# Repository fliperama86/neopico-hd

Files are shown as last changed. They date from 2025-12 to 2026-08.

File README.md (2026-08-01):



# NeoPico-HD

Digital video and audio capture with HDMI output for Neo Geo MVS arcade hardware using Raspberry Pi Pico 2 (RP2350B).

## Features

- **Native 240p HDMI output** at 60fps (via 480p line doubling for audio compatibility)
- **Experimental exact-clock 720p HDMI output** - the normal selector uses a 64.000 MHz, 1440x741 reduced-blanking raster at 59.979 Hz and centers the source at 3x scale
- **15-bit RGB + SHADOW/DARK capture** - 19-bit capture path includes SHADOW and DARK control lines
- **Pixel Conversion Modes** - Stable 32K-entry RGB LUT, plus an optional live and persistent `Digital`/`Analog` normal-color selector that remains separate from DARK/SHADOW processing
- **Translucent OSD Panel** - Enabled by default; game pixels under the black panel retain 12.5% brightness while text and menu colors remain opaque
- **Digital audio capture** from I2S bus (before DAC) with 48kHz HDMI output
- **Zero-overhead DMA video capture** - uses PIO + DMA with ping-pong buffering for perfect stability
- **PicoHDMI Output** - Powered by the [PicoHDMI](https://github.com/fliperama86/pico_hdmi) library for efficient, hardware-native TMDS encoding via RP2350 HSTX.

## Status

| Feature | Status |
| --- | --- |
| 480p HDMI video | Working |
| 720p HDMI video | Experimental (exact-clock runtime selector mode) |
| 60fps capture | Working |
| RGB555 Digital path | Working |
| Live Colors selector | Available whenever DARK/SHADOW is off (MVS builds) |
| SHADOW/DARK capture | Working |
| SHADOW/DARK conversion  | Experimental, default off; split-LUT hardware test showed bottom-screen pixel jitter |
| HDMI audio (48kHz) | Working |
| OSD Diagnostics | Working |
| Morhph4K, RetroTink 4K  | Tested |
| Samsung Q80, Acer Pred. | Tested |

## Hardware Requirements

- **Raspberry Pi Pico 2** - Must be RP2350**B** variant (48 GPIOs) for digital audio capture
- **Neo Geo MVS board** - Tested on MV1C
- **HDMI connector** wired to Pico GPIO

### Hardware Setup & Signal Integrity

To ensure clean audio and video capture, follow these best practices:

1.  **Common Ground**: A solid ground connection between the MVS board and the Pico is **mandatory**.
2.  **HDMI Power**: It is **absolutely mandatory** to have the HDMI connector properly powered with **+5V**. While some devices (like the Morph4K) may be forgiving, others (like the RetroTINK, TVs and monitors) will not pick up the signal without it.
3.  **Level Shifting**: Route all MVS -> Pico digital lines through proper **5V-to-3.3V level shifters**.
4.  **Clock Conditioning**: Keep **Schmitt-trigger conditioning** on PCLK and BCK for clean edges.
5.  **Power-Path Isolation**: Prevent back-feed between external 5V and USB 5V (ideal diode/power mux approach recommended).
6.  **Cable Separation**: Physically separate the I2S audio wires (GPIO 22-24 path) from the video wire bundle to avoid coupling.
7.  **Shielding**: Use a **GND-Signal-GND** pattern when using ribbon cables.

### Pin Configuration

#### Video Capture (Bank 1)

| Function | GPIO | Notes |
| --- | --- | --- |
| MVS CSYNC  | GPIO 27 | Composite sync |
| MVS PCLK | GPIO 28 | 6 MHz pixel clock |
| MVS Blue | GPIO 29-33 | B4-B0 (contiguous) |
| MVS Green  | GPIO 34-38 | G4-G0 (contiguous) |
| MVS Red | GPIO 39-43 | R4-R0 (contiguous) |
| MVS SHADOW | GPIO 44 | Shadow dimming |
| MVS DARK | GPIO 45 | Dark dimming control |

#### HSTX Output (Bank 0/1)

| Function | GPIO |
| --- | --- |
| TMDS CLK | GPIO 12-13 |
| TMDS D0  | GPIO 14-15 |
| TMDS D1  | GPIO 16-17 |
| TMDS D2  | GPIO 18-19 |

#### Audio Capture

| Function | GPIO | MV1C Tap Point |
| --- | --- | --- |
| I2S DAT  | GPIO 22 | R91 |
| I2S WS | GPIO 23 | R90 |
| I2S BCK  | GPIO 24 | R92 |

#### Controller OSD Inputs (MVS/AES)

| Controller input | GPIO |
| --- | ---- |
| START / MENU | GP0  |
| SELECT / BACK | GP1  |
| DOWN | GP2  |
| UP | GP3  |

The inputs are active low and use weak internal pull-ups so untapped pins stay
idle. They are always enabled, on both MVS/AES and SNES builds (GP0-3 are
unused by SNES capture, so this is harmless there too).

## Prebuilt Firmware

GitHub Releases include ready-to-flash selector firmware. Each UF2 can switch
between 240p, 480p, and 720p from the reboot-based OSD resolution menu. The MVS
asset also includes persistent Audio and live-preview Colors menus. The optional
PC monitor modes are default-off and are not included in those release choices.
The selector's 720p entry uses the exact 64.000 MHz reduced-blanking timing;
because it is non-CTA and advertises VIC 0, sink compatibility still needs broad
testing.

| Asset | Capture | OSD choices |
| ----- | --- | --- |
| `neopico_hd_mvs.uf2` | Neo Geo MVS/AES | Resolution, Audio, and Digital/Analog Colors |
| `neopico_hd_snes.uf2` | SNES | Resolution |

Matching ELF files and the `neopico-hd-jlcpcb.zip` fabrication package are also
attached to each release. Controller-driven AES OSD navigation is enabled in
both release assets (GP0-3 are unused by SNES capture).

## Building

Requires [Pico SDK](https://github.com/raspberrypi/pico-sdk) with `PICO_SDK_PATH` set.

```bash
# Build and flash
./flash

# Optional standalone HDMI/OSD self-test firmware
cmake -S . -B build_selftest -DNEOPICO_BUILD_SELFTEST=ON
cmake --build build_selftest --target neopico_selftest -j4

# Standard MVS build. Audio is always SELECTABLE (persistent Audio menu
# between the digital NEO-YSA2 tap and an external PCM1802 ADC) and the
# live persistent Colors selector (Digital/Analog normal-color, ignoring
# DARK/SHADOW) is available automatically since DARK/SHADOW defaults off.
cmake -S . -B build_mvs
cmake --build build_mvs --target neopico_hd -j4

# Separate DARK/SHADOW timing experiment. This path produced bottom-screen
# pixel jitter in hardware testing. Enabling it automatically compiles out
# the Colors selector (the two features share the same capture LUT machinery).
cmake -S . -B build_effects \
  -DNEOPICO_ENABLE_DARK_SHADOW=ON \
  -DNEOPICO_MVS_EFFECT_MODEL=MISTER
cmake --build build_effects --target neopico_hd -j4

# Digital-only register-processing experiment. This replaces the split effect
# LUT with RBIT, bitfield, saturating DARK, and packed SHADOW operations. It is
# default off and must be hardware-validated before use in release firmware.
cmake -S . -B build_effects_processing \
  -DNEOPICO_COPY_TO_RAM=ON \
  -DNEOPICO_ENABLE_DARK_SHADOW=ON \
  -DNEOPICO_MVS_DIGITAL_EFFECT_PROCESSING=ON \
  -DNEOPICO_MVS_EFFECT_MODEL=MISTER
cmake --build build_effects_processing --target neopico_hd -j4
```

## Architecture

```
Core 0: Video Capture               Core 1: Audio Pipeline + HSTX
+--------------------------+       +--------------------------+
| Video: PIO1 -> DMA (PP)  |       | Audio: PIO2 -> processing|
| Conv: 32K LUT (dual opt) |       | [ PicoHDMI Library ]     |
| Main loop: Control       |       | - 640x480 @ 60Hz         |
| Heartbeat LED            |       | - HDMI Data Islands      |
+--------------------------+       +--------------------------+
          |                        +--------------------------+
          |                                   |
          +--------- framebuf ----------------+
                  (320x240 RGB565)
```

### PicoHDMI Library Integration

The project leverages the [PicoHDMI](https://github.com/fliperama86/pico_hdmi) library (found in `lib/pico_hdmi`) to interface with the RP2350's HSTX peripheral. This library provides the high-performance TMDS encoding and Data Island management required for stable HDMI output.

- **Dedicated Output Core**: To ensure rock-solid HDMI timing (exactly 800 cycles per line), the library runs its main loop on **Core 1**. This isolates the high-priority TMDS serialization from the video capture logic on Core 0.
- **Zero-Latency Scaling**: We use the library's `video_output_set_scanline_callback()` to implement a scanline doubler. This performs 2x vertical upscaling (240p to 480p) on-the-fly as pixels are streamed to the HSTX, avoiding the need for a full 480p framebuffer.
- **HDMI Audio Injection**: Audio data is integrated via the library's Data Island queue (`hstx_di_queue`). The audio subsystem pushes TERC4-encoded packets into this queue, which the library then automatically injects during the horizontal blanking intervals.
- **Frame Synchronization**: A VSYNC callback is used to keep the video capture ring buffer and the HDMI output in perfect sync, minimizing latency and preventing screen tearing.

## Documentation

- **[System Architecture](docs/ARCHITECTURE.md)**: High-level design, core partitioning, and the closed-loop audio sync.
- **[Video Implementation](docs/MVS_MV1C_DIGITAL_VIDEO.md)**: Tap points, signal logic, and PIO capture.
- **[Audio Implementation](docs/MVS_MV1C_DIGITAL_AUDIO.md)**: I2S format, ASRC strategy, and drift control.
- **[Standalone PCM1802 USB Capture](docs/PCM1802_USB_CAPTURE.md)**: Raw ADC diagnostic firmware and host capture tool.
- **[HSTX & HDMI](docs/HSTX_IMPLEMENTATION.md)**: Output timing, TMDS, and Data Islands.
- **[OSD](docs/OSD_IMPLEMENTATION.md)**: On-Screen Display rendering.
- **[Reboot Resolution Switching](docs/REBOOT_RESOLUTION_SWITCHING.md)**: Reboot selector modes.
- **[720p Samsung Game Mode Investigation](docs/720P_SAMSUNG_GAME_MODE_INVESTIGATION.md)**: Current findings on Samsung Game Mode 720p glitches.
- **[Known Issues](docs/KNOWN_ISSUES.md)**: Current limitations and compatibility notes.

## Architecture Highlights

- **Dual-Core Design**: Dedicated cores for Video Capture (Core 0) and HDMI Output (Core 1).
- **Closed-Loop Audio Sync**: Software-defined feedback loop effectively "genlocks" the MVS audio to the HDMI clock, preventing drift and glitches without an FPGA.
- **Zero-Lag**: Scanline-doubling architecture with no framebuffer delay.

## Installation

Unlicense

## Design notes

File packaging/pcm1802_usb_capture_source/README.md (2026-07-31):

# NeoPico PCM1802 USB Capture Source

This is a standalone source package for the NeoPico PCM1802 USB capture
diagnostic. It builds without the NeoPico-HD video or PicoHDMI sources.

The firmware captures standard-I2S PCM1802 DOUT as signed, stereo, 24-bit PCM
and sends versioned, CRC-protected packets through TinyUSB CDC. The default
transport preserves all 24 bits. An optional reduced-bandwidth transport sends
the upper 16 bits, and the included host tool automatically writes a matching
48 kHz stereo WAV file.

## Validation status

The source package is built from the same files as the NeoPico-HD repository.
Its standalone CMake project is tested after export with clean 24-bit and 16-bit
RP2350 builds. The 24-bit firmware has completed a local zero-drop 48 kHz
hardware capture; achievable USB throughput remains host-dependent.

## Source layout

```text
CMakeLists.txt
LICENSE
src/
  main.c
  usb_descriptors.c
  tusb_config.h
  i2s_capture.pio
tools/
  capture_pcm1802_usb.py
```

## Requirements

- Raspberry Pi Pico SDK with RP2350 support
- Arm GNU Toolchain
- CMake and a supported build tool such as Ninja or Make
- WeAct RP2350B board, or another RP2350 board exposing GP22 through GP24

## Build

Set `PICO_SDK_PATH`, then configure and build from this extracted directory:

```sh
cmake -S . -B build \
  -DPICO_SDK_PATH="$HOME/pico-sdk" \
  -DCMAKE_BUILD_TYPE=Release
cmake --build build --target neopico_pcm1802_usb_capture -j
```

The default board is `weact_studio_rp2350b_core`. Override `PICO_BOARD` and, if
needed, `PICO_PLATFORM` for another RP2350 board.

The standalone UF2 is generated at:

```text
build/neopico_pcm1802_usb_capture.uf2
```

For the reduced-bandwidth diagnostic, add this configure option and use a
separate build directory:

```sh
-DNEOPICO_PCM1802_USB_BITS_PER_SAMPLE=16
```

The default is `24`. The 16-bit option does not reconfigure the PCM1802 or PIO;
it discards the least-significant byte only while staging USB packets.

## Expected PCM1802 connection

| Signal | RP2350B pin |
| --- | --- |
| PCM1802 DOUT | GP22 |
| PCM1802 LRCK | GP23 |
| PCM1802 BCK | GP24 |

Expected format: standard Philips I2S, 24-bit, LRCK low for left and high for
right. With 12.288 MHz SCKI in 256fs master mode, LRCK is 48 kHz and BCK is
3.072 MHz.

## Power safety

Prevent backfeeding between USB 5 V and external 5 V. Disconnect external power
unless the installation has verified power-path isolation. Keep a solid shared
ground between the PCM1802 and RP2350B, and do not alter wiring while powered.

## Host protocol self-test and capture

The self-test does not require pyserial or hardware:

```sh
python3 tools/capture_pcm1802_usb.py --self-test
```

Install pyserial for a real capture:

```sh
python3 -m pip install pyserial
python3 tools/capture_pcm1802_usb.py pcm1802-raw.wav
```

Use `--seconds 30` for a timed capture or `--port COM5` on Windows when explicit
port selection is needed.

Flashing this diagnostic temporarily replaces the normal NeoPico-HD firmware.
Flash the normal NeoPico-HD UF2 again after collecting the WAV.

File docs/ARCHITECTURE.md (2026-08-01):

# NeoPico-HD System Architecture

NeoPico-HD is a specialized firmware that transforms the RP2350 microcontroller into a real-time, digital-to-digital capture and upscaling bridge for the Neo Geo MVS.

## 1. High-Level Overview

The system bridges two asynchronous clock domains:
1.  **Input Domain**: The Neo Geo MVS (Variable/Drifting clock ~6 MHz pixel, ~55.5 kHz audio).
2.  **Output Domain**: Standard HDMI/DVI (Fixed clock 25.2 MHz pixel, 48 kHz audio).

Unlike FPGA solutions that "slave" the output clock to the input, NeoPico-HD uses the RP2350's raw horsepower to **resample** the data in real-time, maintaining a standards-compliant HDMI output signal regardless of the input source's behavior.

## 2. Core Responsibilities

The workload is strictly partitioned between the two cores to ensure deterministic timing for critical tasks.

### Core 0: Capture & Conversion (The "Input" Core)
*   **Video Capture**: Uses PIO1 (Bank 1 GPIOs) to sample the 15-bit RGB bus + Control signals at exactly 6 MHz.
*   **Synchronization**: Re-synchronizes the PIO state machine on every single CSYNC falling edge to prevent horizontal drift.
*   **Pixel Processing**:
    *   Detects `SHADOW` and `DARK` bits.
    *   Default build uses a pre-computed 32K LUT for corrected RGB555 -> RGB565 conversion.
    *   Whenever `NEOPICO_ENABLE_DARK_SHADOW` is off (MVS builds), the live Colors selector generates 64 KiB `Digital` and `Analog` normal-color LUTs at boot. Core 0 selects one base pointer at input VSYNC, while the pixel loop remains one lookup per pixel. Both choices ignore SHADOW/DARK.
    *   Separate `NEOPICO_ENABLE_DARK_SHADOW=ON` uses an 8,448-byte R/G-plus-B split LUT for four effect states. This timing experiment produced bottom-screen pixel jitter and remains default off.
    *   Converts raw MVS data into standard RGB565.
*   **Frame Management**: Writes to a ping-pong buffer in RAM.
*   **Deferred Colors Persistence**: After a completed frame, Core 0 services the rare queued flash write and resets capture for clean synchronization. This path is experimental and does not run during ordinary frames.

### Core 1: Output & Audio (The "Output" Core)
*   **Video Output**: Drives the HSTX peripheral to generate 640x480p @ 60Hz DVI/HDMI signals.
*   **Scanline Doubling**: Reads the 320x240 capture buffer and performs line doubling on-the-fly during DMA interrupts.
*   **OSD Overlay**: Injects the On-Screen Display menu pixels during the scanline generation phase.
*   **Colors Control**: Browsing previews through a frame-boundary LUT request. SELECT restores the committed model; START/MENU queues persistence without rebooting.
*   **Audio Pipeline**:
    *   Captures I2S audio via PIO2 (Bank 0).
    *   Runs the **Closed-Loop ASRC** (Asynchronous Sample Rate Converter) to downsample ~55.5kHz to 48kHz.
    *   Encodes audio into TERC4 Data Islands and injects them into the HDMI blanking intervals.

## 3. The Audio Sync Solution (Closed-Loop ASRC)

One of the project's key innovations is handling the asynchronous audio without an FPGA.

### The Problem
The MVS audio clock drifts relative to the RP2350's crystal. A fixed resampling ratio eventually leads to buffer underrun (silence) or overflow (glitches) every ~40 seconds.

### The Solution
We implemented a **Proportional Control Loop**:
1.  **Measure**: The system monitors the fill level of the HDMI Data Island Ring Buffer (`hstx_di_queue`).
2.  **Feedback**:
    *   If buffer > 60% full -> The SRC is "producing too fast". We effectively increase the input rate parameter, causing the SRC to drop more samples to catch up.
    *   If buffer < 35% full -> The SRC is "producing too slow". We decrease the input rate parameter, causing the SRC to emit more samples.
3.  **Result**: The audio buffer hovers around 50%, essentially "locking" the audio production rate to the video consumption rate.

## 4. Memory Map

| Region | Size | Usage |
| :--- | :--- | :--- |
| **SRAM_STRIPED** | 8.25-128 KiB | **Video LUT** (64 KiB stable table, 128 KiB dual normal-color menu, or 8.25 KiB separate four-state effect experiment) |
| **SRAM** | 150 KB | **Framebuffer** (320x240 RGB565) |
| **SRAM** | 16 KB | **Audio DMA Buffer** (Raw I2S capture) |
| **SCRATCH_X** | 4 KB | **Core 1 ISRs** (HSTX/Audio critical code) |
| **SCRATCH_Y** | 4 KB | **Core 0 ISRs** (Capture critical code) |

## 5. Hardware Interfaces

*   **Bank 0 (GPIO 0-29)**: Standard I/O. Used for I2S Audio (PIO2) and HSTX Output.
*   **Bank 1 (GPIO 25-47)**: High-speed capture. Used for the MVS 24-bit video bus.
    *   *Note*: Accessing Bank 1 requires specific SDK register manipulation (`GPIOBASE` offsets).

## 6. Critical Constraints

*   **Interrupt Latency**: Core 1's DMA ISR must complete well within the horizontal blanking period (~1.9µs) to maintain HDMI sync.
*   **CPU Cycle Sensitivity**: In the scanline generation phase, every nanosecond counts. Unoptimized logic (such as `if` statements inside pixel loops) will cause the HSTX FIFO to underrun, resulting in an immediate loss of video signal.
*   **Grounding**: The digital video tap is extremely sensitive to ground loops. A low-impedance shared ground is mandatory.

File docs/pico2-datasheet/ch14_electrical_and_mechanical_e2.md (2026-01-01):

## Chapter 14. Electrical and mechanical E2

This section contains physical and electrical details for RP2350.

## 14.1. QFN-60 package

Millimetre

Nom.

0.850

0.203 REF

0.400 BSC

0.350

Tolerances of form and position aaa

bbb cCC

didd eee

fff

All dimensions are in millimetres

Drawings not to scale ddd M

<!-- image -->

A

C A

в

Table 1423. Thermal data for the QFN-60 package.

Figure 144. Recommended PCB Footprint for the RP2350 QFN-60 package

<!-- image -->

Leads have a matte Tin (Sn) finish. Annealing is done post-plating, baking at 150°C for 1 hour. Minimum thickness for lead plating is 8 microns, and the intermediate layer material is CuFe2P (roughened Copper (Cu)).

## 14.1.1. Thermal characteristics

The thermal characteristics of the QFN-60 package are shown in Table 1423.

| Device | θ JA (°C/W) - Still Air | θ JA (°C/W) - 1m/s Forced Air | θ JA (°C/W) - 2m/s Forced Air | θ JB (°C/W) | θ JC (°C/W) |
|---|---|---|---|---|---|
| RP2350A  | 40.542 | 31.99 | 30.264 | 12.588 | 14.315 |
| RP2354A  | TBD | TBD | TBD | TBD | TBD |

## 14.1.2. Recommended PCB footprint

<!-- image -->

## 14.2. QFN-80 package

\_aser mark for pir identification in

this area aaa

C ×2

aaa

Table 1424. Thermal data for the QFN-80 package.

× 80

Bottom view

D2- ffM

A

Pin 1 identification

<!-- image -->

<!-- image -->

##  NOTE

Leads have a matte Tin (Sn) finish. Annealing is done post-plating, baking at 150°C for 1 hour. Minimum thickness for lead plating is 8 microns, and the intermediate layer material is CuFe2P (roughened Copper (Cu)).

## 14.2.1. Thermal characteristics

The thermal characteristics of the QFN-80 package are shown in Table 1424.

| Device | θ JA (°C/W) - Still Air | θ JA (°C/W) - 1m/s Forced Air | θ JA (°C/W) - 2m/s Forced Air | θ JB (°C/W) | θ JC (°C/W) |
|---|---|---|---|---|---|
| RP2350B  | TBD | TBD | TBD | TBD | TBD |
| RP2354B  | TBD | TBD | TBD | TBD | TBD |

## 14.2.2. Recommended PCB footprint

<!-- image -->

## 14.3. Flash in package

RP2354A and RP2354B feature 2 MB of internal flash. In all other respects, including pinout, they are identical to their flashless  counterparts  RP2350A  and  RP2350B.  They  use  the  same  QFN-60  (RP2354A)  and  QFN-80  (RP2354B) packages. An RP2354 device contains two stacked silicon die:

- the same RP2350 die as the flashless variants
- a Winbond W25Q16JVWI QSPI NOR flash

## Winbond W25Q16JVWI datasheet

For detailed information on the W25Q16JVWI device used in RP2354 see:

www.winbond.com/hq/product/code-storage-flash-memory/serial-norflash/?\_\_locale=en&amp;partNo=W25Q16JV

The six dedicated QSPI pads on the RP2350 die ( CSn , SCK and SD0 through SD3 ) connect to both the internal flash die and the external package pins. This makes them behave similarly to flashless RP2350 devices in the following ways:

- The QSPI CSn can be driven low at reset or power-up to select BOOTSEL mode
- This harmlessly selects the internal flash die but does not issue commands to it
- The QSPI SD1 pin can be driven high when selecting BOOTSEL to choose UART boot
- UART TX appears on SD2 and UART RX on SD3 , as per Section 5.8
- Even with the chip select asserted low, the internal flash die maintains a high-impedance state on its SD0 through SD3 pins if there are no transitions on SCK , so you can keep CSn asserted throughout UART boot
- Internal flash can be programmed via UF2 drag-and-drop download using the USB BOOTSEL mode
- A second QSPI device can be attached externally by connecting it to the QSPI pins and a secondary chip select from the Bank 0 GPIOs
- This may be used for additional flash capacity, or external QSPI RAM

- See Section 12.14 for more details of the RP2350 QSPI memory interface and its capabilities

The internal flash die can also be programmed externally by holding the RP2350 die in reset via the RUN pin (active-low reset), and driving QSPI signals into the chip from an external programmer.

The internal  flash  is  powered  by  the  QSPI\_IOVDD  supply  input.  This  voltage  must  be  in  the  range  2.7  to  3.6 V.  You should account for the increased high-frequency currents on this supply pin in your decoupling circuit and PCB layout.

The maximum QSPI clock frequency of the W25Q16JVWI is 133 MHz. Consult the W25Q16JVWI datasheet for detailed timings and AC parameters.

If you do not require access to the RP2350 QSPI bus from the outside, you should minimise the track length connected to the QSPI package pins on your PCB. This avoids unnecessary emissions and capacitive loading of the QSPI bus.

The PADRESETB reset input on the W25Q16JVWI is not connected to any external package pins, or to any internal signals on the RP2350 die. This means there is no way to perform a hardware reset of the flash die. When the RP2350 die comes out of reset it initialises the flash die in the same way it would an external flash device by issuing a fixed XIP exit sequence that returns the flash die to a serial command state in preparation for execute-in-place setup.

## 14.4. Package markings

RP2350 comes in 7 × 7 mm QFN-60 and 10 × 10 mm QFN-80 packages, which are marked with the following data:

- Pin 1 dot
- Logo
- Part number
- Date code (Week)
- Silicon lot number
- Date code (Year)

The part number consists of the following:

- Device name "RP2350"
- Package type, "A" for QFN-60 or "B" for QFN-80
- Package revision "0"
- Die stepping "A2", "A3", or "A4"

See Appendix C for a summary of the differences between die steppings.

## 14.5. Storage conditions

To preserve the shelf and floor life of bare RP2350 devices, follow JEDEC J-STD (020E &amp; 033D).

RP2350 QFN-60 is classified as Moisture Sensitivity Level 1 (MSL1). The MSL of QFN-80 is still being characterised and details will follow in a future datasheet update.

All RP2350 devices should be stored under 30°C and 85% relative humidity.

## 14.6. Solder profile

RP2350 is a Pb-free part, with a T p value of 260°C.

All  temperatures  refer  to  the  centre  of  the  package,  measured  on  the  package  body  surface  that  faces  up  during

Figure 147. Classification profile (not to scale)

Table 1425. Solder profile values

assembly reflow (live-bug orientation). If parts are reflowed in a different orientation (e.g. dead-bug), T p shall be within ±2°C of the live-bug T p and still meet the T c requirements; otherwise, you must adjust the profile to achieve the latter.

<!-- image -->

Reflow profiles in this document are for classification/preconditioning, and are not meant to specify board assembly profiles. Actual board assembly profiles should be developed based on specific process needs and board designs, and should not exceed the parameters in Table 1425.

| Profile feature | Value |
|---|---|
| Temperature min (T smin ) | 150°C |
| Temperature max (T smax ) | 200°C |
| Time (t s ) from (T smin to T smax ) | 60 - 120 seconds  |
| Ramp-up rate (T L to T p ) | 3°C/second max. |
| Liquidous temperature (T L ) | 217°C |
| Time (t L ) maintained above T L | 60 to 150 seconds |
| Peak package body temperature (T p ) | 260°C |
| Classification temperature (T c ) | 260°C |
| Time (t p ) within 5°C of the specified classification temperature (T c ) | 30 seconds |
| Ramp-down rate (T p to T L ) | 6°C/second max. |
| Time 25°C to peak temperature | 8 minutes max. |

## 14.7. Compliance

RP2350 QFN-60 is compliant to Moisture Sensitivity Level 1. The Moisture Sensitivity Level compliance of RP2350 QFN80 is yet to be fully characterised, and details will follow in a future datasheet update.

RP2350 is compliant to the requirement of REACH Substances of Very High Concern (SVHC), EU ECHA directive.

RP2350 is compliant to the requirement and standard of Controlled Environment-related Substance of RoHS directive (EU) 2011/65/EU and directive (EU) 2015/863.

Raspberry Pi Ltd carried out the following Package Level reliability qualifications on RP2350:

- Temperature Cycling per JESD22-A104
- HAST per JESD22-A110
- HTSL per JESD22-A103
- MSL level per JESD22-A113

The following Silicon Level reliability qualification were also carried out:

- HTOL per JESD22-A108F

<!-- image -->

##  NOTE

A  tin  whiskers  test  is  not  performed.  RP2350  is  a  bottom-only  termination  device  in  the  QFN-60  and  QFN-80 packages, therefore JEDEC standard (JESD201A) is not applicable.

## 14.8. Pinout

## 14.8.1. Pin locations

## 14.8.1.1. QFN-60 (RP2350A)

Figure 148. RP2350 Pinout for QFN-60 7 × 7mm

Figure 149. RP2350 Pinout for QFN-80 10 × 10mm

<!-- image -->

## 14.8.1.2. QFN-80 (RP2350B)

<!-- image -->

Table 1426. Pin Types

Table 1427. GPIO pins

## 14.8.2. Pin definitions

## 14.8.2.1. Pin types

In the following pin tables (Table 1427), the pin types are defined as shown below.

| Pin Type | Direction | Description |
|---|---|---|
| Digital In | Input only | Standard Digital . Programmable Pull-Up, Pull-Down, Slew Rate, Schmitt Trigger and Drive Strength. Default Drive Strength is 4 mA. |
| Digital IO | Bi-directional | Standard Digital . Programmable Pull-Up, Pull-Down, Slew Rate, Schmitt Trigger and Drive Strength. Default Drive Strength is 4 mA. |
| Digital In (FT) | Input only | Fault Tolerant Digital . These pins are described as Fault Tolerant, which in this case means that very little current flows into the pin whilst it is below 3.63 V and IOVDD is 0 V. Additionally, they will tolerate voltages up to 5.5 V, provided IOVDD is powered to 3.3 V. |
| Digital IO (FT) | Bi-directional | These pins have enhanced ESD protection. Programmable Pull-Up, Pull-Down, Slew Rate, Schmitt Trigger and Drive Strength. Default Drive Strength is 4 mA. |
| Digital IO / Analogue | Bi-directional (digital), Input (Analogue) | Standard Digital and ADC input . Programmable Pull-Up, Pull-Down, Slew Rate, Schmitt Trigger and Drive Strength. Default Drive Strength is 4 mA. |
| USB IO | Bi-directional | These pins are for USB use, and contain internal pull-up and pull-down resistors, as per the USB specification. USB operation requires external 27 Ω series resistors. |
| Analogue (XOSC) | | Oscillator input pins for attaching a 12 MHz crystal. Alternatively, XIN may be driven by a square wave. |

## 14.8.2.2. Pin list

| Name | QFN-60 Number | QFN-80 Number | Type | Power Domain | Reset State | Description |
|---|---|---|---|---|---|---|
| GPIO0  | 2 | 77 | Digital IO (FT) | IOVDD | Pull-Down | User IO |
| GPIO1  | 3 | 78 | Digital IO (FT) | IOVDD | Pull-Down | User IO |
| GPIO2  | 4 | 79 | Digital IO (FT) | IOVDD | Pull-Down | User IO |
| GPIO3  | 5 | 80 | Digital IO (FT) | IOVDD | Pull-Down | User IO |
| GPIO4  | 7 | 1 | Digital IO (FT) | IOVDD | Pull-Down | User IO |
| GPIO5  | 8 | 2 | Digital IO (FT) | IOVDD | Pull-Down | User IO |
| GPIO6  | 9 | 3 | Digital IO (FT) | IOVDD | Pull-Down | User IO |
| GPIO7  | 10 | 4 | Digital IO (FT) | IOVDD | Pull-Down | User IO |
| GPIO8  | 12 | 6 | Digital IO (FT) | IOVDD | Pull-Down | User IO |
| GPIO9  | 13 | 7 | Digital IO (FT) | IOVDD | Pull-Down | User IO |
| GPIO10 | 14 | 8 | Digital IO (FT) | IOVDD | Pull-Down | User IO |
| GPIO11 | 15 | 9 | Digital IO (FT) | IOVDD | Pull-Down | User IO |
| GPIO12 | 16 | 11 | Digital IO (FT) | IOVDD | Pull-Down | User IO |
| GPIO13 | 17 | 12 | Digital IO (FT) | IOVDD | Pull-Down | User IO |
| GPIO14 | 18 | 13 | Digital IO (FT) | IOVDD | Pull-Down | User IO |

| Name | QFN-60 Number | QFN-80 Number | Type | Power Domain | Reset State | Description |
|---|---|---|---|---|---|---|
| GPIO15 | 19 | 14 | Digital IO (FT) | IOVDD | Pull-Down | User IO |
| GPIO16 | 27 | 16 | Digital IO (FT) | IOVDD | Pull-Down | User IO |
| GPIO17 | 28 | 17 | Digital IO (FT) | IOVDD | Pull-Down | User IO |
| GPIO18 | 29 | 18 | Digital IO (FT) | IOVDD | Pull-Down | User IO |
| GPIO19 | 31 | 19 | Digital IO (FT) | IOVDD | Pull-Down | User IO |
| GPIO20 | 32 | 20 | Digital IO (FT) | IOVDD | Pull-Down | User IO |
| GPIO21 | 33 | 21 | Digital IO (FT) | IOVDD | Pull-Down | User IO |
| GPIO22 | 34 | 22 | Digital IO (FT) | IOVDD | Pull-Down | User IO |
| GPIO23 | 35 | 23 | Digital IO (FT) | IOVDD | Pull-Down | User IO |
| GPIO24 | 36 | 25 | Digital IO (FT) | IOVDD | Pull-Down | User IO |
| GPIO25 | 37 | 26 | Digital IO (FT) | IOVDD | Pull-Down | User IO |
| GPIO26_ADC0 | 40 | - | Digital IO / Analogue | IOVDD / ADC_AVDD | Pull-Down | User IO or ADC input |
| GPIO27_ADC1 | 41 | - | Digital IO / Analogue | IOVDD / ADC_AVDD | Pull-Down | User IO or ADC input |
| GPIO28_ADC2 | 42 | - | Digital IO / Analogue | IOVDD / ADC_AVDD | Pull-Down | User IO or ADC input |
| GPIO29_ADC3 | 43 | - | Digital IO / Analogue | IOVDD / ADC_AVDD | Pull-Down | User IO or ADC input |
| GPIO26 | - | 27 | Digital IO (FT) | IOVDD | Pull-Down | User IO |
| GPIO27 | - | 28 | Digital IO (FT) | IOVDD | Pull-Down | User IO |
| GPIO28 | - | 36 | Digital IO (FT) | IOVDD | Pull-Down | User IO |
| GPIO29 | - | 37 | Digital IO (FT) | IOVDD | Pull-Down | User IO |
| GPIO30 | - | 38 | Digital IO (FT) | IOVDD | Pull-Down | User IO |
| GPIO31 | - | 39 | Digital IO (FT) | IOVDD | Pull-Down | User IO |
| GPIO32 | - | 40 | Digital IO (FT) | IOVDD | Pull-Down | User IO |
| GPIO33 | - | 42 | Digital IO (FT) | IOVDD | Pull-Down | User IO |
| GPIO34 | - | 43 | Digital IO (FT) | IOVDD | Pull-Down | User IO |
| GPIO35 | - | 44 | Digital IO (FT) | IOVDD | Pull-Down | User IO |
| GPIO36 | - | 45 | Digital IO (FT) | IOVDD | Pull-Down | User IO |
| GPIO37 | - | 46 | Digital IO (FT) | IOVDD | Pull-Down | User IO |
| GPIO38 | - | 47 | Digital IO (FT) | IOVDD | Pull-Down | User IO |
| GPIO39 | - | 48 | Digital IO (FT) | IOVDD | Pull-Down | User IO |
| GPIO40_ADC0 | - | 49 | Digital IO / Analogue | IOVDD / ADC_AVDD | Pull-Down | User IO or ADC input |
| GPIO41_ADC1 | - | 52 | Digital IO / Analogue | IOVDD / ADC_AVDD | Pull-Down | User IO or ADC input |

Table 1428. QSPI pins

Table 1429. Crystal oscillator pins

Table 1430. Miscellaneous pins

Table 1431. USB pins

| Name | QFN-60 Number | QFN-80 Number | Type | Power Domain | Reset State | Description |
|---|---|---|---|---|---|---|
| GPIO42_ADC2 | - | 53 | Digital IO / Analogue | IOVDD / ADC_AVDD | Pull-Down | User IO or ADC input |
| GPIO43_ADC3 | - | 54 | Digital IO / Analogue | IOVDD / ADC_AVDD | Pull-Down | User IO or ADC input |
| GPIO44_ADC4 | - | 55 | Digital IO / Analogue | IOVDD / ADC_AVDD | Pull-Down | User IO or ADC input |
| GPIO45_ADC5 | - | 56 | Digital IO / Analogue | IOVDD / ADC_AVDD | Pull-Down | User IO or ADC input |
| GPIO46_ADC6 | - | 57 | Digital IO / Analogue | IOVDD / ADC_AVDD | Pull-Down | User IO or ADC input |
| GPIO47_ADC7 | - | 58 | Digital IO / Analogue | IOVDD / ADC_AVDD | Pull-Down | User IO or ADC input |

| Name | QFN-60 Number | QFN-80 Number | Type | Power Domain | Reset State | Description |
|---|---|---|---|---|---|---|
| QSPI_SD3  | 55 | 70 | Digital IO | QSPI_IOVDD | Pull-Up | QSPI data |
| QSPI_SCLK | 56 | 71 | Digital IO | QSPI_IOVDD | Pull-Down | QSPI clock |
| QSPI_SD0  | 57 | 72 | Digital IO | QSPI_IOVDD | Pull-Down | QSPI data |
| QSPI_SD2  | 58 | 73 | Digital IO | QSPI_IOVDD | Pull-Up | QSPI data |
| QSPI_SD1  | 59 | 74 | Digital IO | QSPI_IOVDD | Pull-Down | QSPI data |
| QSPI_SS | 60 | 75 | Digital IO | QSPI_IOVDD | Pull-Up | QSPI chip select / USB BOOTSEL |

| Name | QFN-60 Number | QFN-80 Number | Type | Power Domain | Description |
|---|---|---|---|---|---|
| XIN | 21 | 30 | Analogue (XOSC) | IOVDD | Crystal oscillator. XIN may also be driven by a square wave. |
| XOUT | 22 | 31 | Analogue (XOSC) | IOVDD | Crystal oscillator. |

| Name | QFN-60 Number | QFN-80 Number | Type | Power Domain | Reset State | Description |
|---|---|---|---|---|---|---|
| RUN | 26 | 35 | Digital In (FT) | IOVDD | Pull-Up | Chip enable / reset_n |
| SWCLK  | 24 | 33 | Digital In (FT) | IOVDD | Pull-Up | Serial Wire Debug clock |
| SWDIO  | 25 | 34 | Digital IO (FT) | IOVDD | Pull-Up | Serial Wire Debug data  |

| Name | QFN-60 Number | QFN-80 Number | Type | Power Domain | Description |
|---|---|---|---|---|---|
| USB_DP | 52 | 67 | USB IO | USB_OTP_VDD | USB Data +ve. 27 Ω series resistor required for USB operation |

Table 1432. Power supply pins

Table 1433. Absolute maximum ratings

| Name | QFN-60 Number | QFN-80 Number | Type | Power Domain | Description |
|---|---|---|---|---|---|
| USB_DM | 51 | 66 | USB IO | USB_OTP_VDD | USB Data -ve. 27 Ω series resistor required for USB operation |

| Name | QFN-60 Number(s) | QFN-80 Number(s) | Description |
|---|---|---|---|
| DVDD | 6, 23, 39 | 10, 32, 51 | Core supply |
| IOVDD | 11, 20, 30, 38, 45, 54 | 5, 15, 24, 29, 41, 50, 60, 76 | IO supply |
| QSPI_IOVDD  | 54 | 69 | QSPI IO supply |
| USB_OTP_VDD | 53 | 68 | USB & OTP supply |
| ADC_AVDD | 44 | 59 | ADC supply |
| VREG_AVDD | 46 | 61 | Voltage regulator analogue supply |
| VREG_PGND | 47 | 62 | Voltage regulator ground |
| VREG_LX | 48 | 63 | Voltage regulator switching output (connect to inductor) |
| VREG_VIN | 49 | 64 | Voltage regulator input supply |
| VREG_FB | 50 | 65 | Voltage regulator feedback input |
| GND | - | - | Ground connection via central exposed pad |

## 14.9. Electrical specifications

The following electrical specifications are obtained from characterisation over the specified temperature and voltage ranges,  as  well  as  process  variation,  unless  the  specification  is  marked  as  'Simulated'.  In  this  case,  the  data  is  for information purposes only, and is not guaranteed.

## 14.9.1. Absolute maximum ratings

Stresses  beyond  the  absolute  maximum  ratings  listed  in  the  following  table  can  cause  permanent  damage  to  the device. These are stress ratings only and do not refer to the functional operation of the device.

| Parameter | Symbol | Conditions | Minimum | Maximum | Units | Comment |
|---|---|---|---|---|---|---|
| Core Supply (DVDD) Voltage | DVDD | | -0.5 | 1.21 | V | |
| I/O Supply (IOVDD) & QSPI Supply (QSPI_IOVDD) Voltage | IOVDD | | -0.5 | 3.63 | V | |

Table 1434. ESD performance for all pins, unless otherwise stated

Table 1435. Thermal Performance

Table 1436. Digital IO characteristics Standard and FT unless otherwise stated. In this table IOVDD also refers to QSPI\_IOVDD where appropriate

| Parameter | Symbol | Conditions | Minimum | Maximum | Units | Comment |
|---|---|---|---|---|---|---|
| Voltage at IO (Standard) | V PIN | | -0.5 | IOVDD + 0.5 | V | |
| Voltage at IO (FT) | V PIN_FT | IOVDD=3.3V | -0.5 | 5.5 | V | IOVDD must be present |
| Voltage at IO (FT) | V PIN_FT | IOVDD=2.5V | -0.5 | 4.2 | V | IOVDD must be present |
| Voltage at IO (FT) | V PIN_FT | IOVDD=1.8V | -0.5 | 3.63 | V | IOVDD must be present |
| Voltage at IO (FT) | V PIN_FT | IOVDD=0V | -0.5 | 3.63 | V | |
| Junction temperature | | | -40 | 125 | °C | |
| Storage temperature | | | | 150 | °C | |

## 14.9.2. ESD performance

| Parameter | Symbol | Maximum | Units | Comment |
|---|---|---|---|---|
| Human Body Model | HBM | 2 | kV | Compliant with JEDEC specification JS-001- 2012 (April 2012) |
| Human Body Model Digital (FT) pins only | HBM | 4 | kV | Compliant with JEDEC specification JS-001- 2012 (April 2012) |
| Charged Device Model | CDM | 500 | V | Compliant with JESD22-C101E (December 2009) |

## 14.9.3. Thermal performance

| Parameter | Symbol | Minimum | Typical | Maximum | Units | Comment |
|---|---|---|---|---|---|---|
| Ambient | T C | -40 | | 85 | °C | |
| Temperature | | | | | | |

## 14.9.4. IO electrical characteristics

| Parameter | Symbol | Conditions | Minimum | Maximum | Units | Comment |
|---|---|---|---|---|---|---|
| Pin Input Leakage Current | I IN | | | 1 | μ A | |
| Input Voltage | V IH | IOVDD=1.8V | 0.65 * IOVDD | IOVDD + 0.3 | V | |
| High (Standard IO) | | IOVDD=2.5V | 1.7 | IOVDD + 0.3 | V | |
| | | IOVDD=3.3V | 2 | IOVDD + 0.3 | V | |

Table 1437. USB IO

characteristics

| Parameter | Symbol | Conditions | Minimum | Maximum | Units | Comment |
|---|---|---|---|---|---|---|
| Input Voltage High (FT) | V IH | IOVDD=1.8V | 0.65 * IOVDD | 3.63 | V | IOVDD must be powered to tolerate input voltages above 3.63V |
| Input Voltage High (FT) | V IH | IOVDD=2.5V | 1.7 | 4.2 | V | IOVDD must be powered to tolerate input voltages above 3.63V |
| Input Voltage High (FT) | V IH | IOVDD=3.3V | 2 | 5.5 | V | IOVDD must be powered to tolerate input voltages above 3.63V |
| Input Voltage Low | V IL | IOVDD=1.8V | -0.3 | 0.35 * IOVDD | V | |
| Input Voltage Low | V IL | IOVDD=2.5V | -0.3 | 0.7 | V | |
| Input Voltage Low | V IL | IOVDD=3.3V | -0.3 | 0.8 | V | |
| Input Hysteresis Voltage | V HYS | IOVDD=1.8V | 0.1 * IOVDD  | | V | Schmitt Trigger enabled |
| Input Hysteresis Voltage | V HYS | IOVDD=2.5V | 0.2 | | V | Schmitt Trigger enabled |
| Input Hysteresis Voltage | V HYS | IOVDD=3.3V | 0.2 | | V | Schmitt Trigger enabled |
| Output Voltage High | V OH | IOVDD=1.8V | 1.24 | IOVDD | V | I OH = 2, 4, 8 or 12mA depending on setting |
| Output Voltage High | V OH | IOVDD=2.5V | 1.78 | IOVDD | V | I OH = 2, 4, 8 or 12mA depending on setting |
| Output Voltage High | V OH | IOVDD=3.3V | 2.62 | IOVDD | V | I OH = 2, 4, 8 or 12mA depending on setting |
| Output Voltage Low | V OL | IOVDD=1.8V | 0 | 0.3 | V | I OL = 2, 4, 8 or 12mA depending on setting |
| Output Voltage Low | V OL | IOVDD=2.5V | 0 | 0.4 | V | I OL = 2, 4, 8 or 12mA depending on setting |
| Output Voltage Low | V OL | IOVDD=3.3V | 0 | 0.5 | V | I OL = 2, 4, 8 or 12mA depending on setting |
| Pull-Up Resistance | R PU | IOVDD=1.8V | 32 | 106 | k Ω | |
| Pull-Up Resistance | R PU | IOVDD=2.5V | 42 | 123 | k Ω | |
| Pull-Up Resistance | R PU | IOVDD=3.3V | 32 | 86 | k Ω | |
| Pull-Down Resistance | R PD | IOVDD=1.8V | 35 | 189 | k Ω | |
| Pull-Down Resistance | R PD | IOVDD=2.5V | 49 | 180 | k Ω | |
| Pull-Down Resistance | R PD | IOVDD=3.3V | 36 | 113 | k Ω | |
| Maximum Total IOVDD current | I IOVDD_MAX | | | 100 | mA | Sum of all current being sourced by GPIO pins |
| Maximum Total QSPI_IOVDD current | I QSPI_IOVDD_MAX | | | 20 | mA | Sum of all current being sourced by QSPI pins |
| Maximum Total VSS current due to GPIO (IOVSS) | I IOVSS_MAX | | | 100 | mA | Sum of all current being sunk into GPIO pins |
| Maximum Total VSS current due to QSPI (QSPI_IOVSS) | I QSPI_IOVSS_MAX | | | 20 | mA | Sum of all current being sunk into QSPI pins |

Table 1438. ADC characteristics

Table 1439. Oscillator pin characteristics

| Parameter | Symbol | Minimum | Maximum | Units | Comment |
|---|---|---|---|---|---|
| Pin Input Leakage Current | I IN | | 1 | μ A | |
| Single Ended Input Voltage High | V IHSE | 2 | | V | |
| Single Ended Input Voltage Low  | V ILSE | | 0.8 | V | |
| Differential Input Voltage High | V IHDIFF | 0.2 | | V | |
| Differential Input Voltage Low  | V ILDIFF | | -0.2 | V | |
| Output Voltage High | V OH | 2.8 | USB_OTG_VDD | V | |
| Output Voltage Low | V OL | 0 | 0.3 | V | |
| Pull-Up Resistance - RPU2 | R PU2 | 0.873 | 1.548 | k Ω | |
| Pull-Up Resistance - RPU1&2 | R PU1&2  | 1.398 | 3.063 | k Ω | |
| Pull-Down Resistance | R PD | 14.25 | 15.75 | k Ω | |

| Parameter | Symbol | Minimum | Typical | Maximum | Units | Comment |
|---|---|---|---|---|---|---|
| ADC Input Voltage Range  | V PIN_ADC | 0 | | ADC_AVDD  | V | |
| Effective Number of Bits | ENOB | 9 | 9.5 | | bits | |
| Resolved Bits | | | | 12 | bits | |
| ADC Input Impedance | R IN_ADC  | 100 | | | k Ω | |

| Parameter | Symbol | Minimum | Typical | Maximum | Units | Comment |
|---|---|---|---|---|---|---|
| Input Frequency | f osc | 1 | 12 | 50 | MHz | See Section 8.6.3 for restrictions imposed by PLLs. See Section 5.2.8.1 for restrictions imposed by the USB and UART bootloaders. |

Table 1440. SWCLK pin characteristics

| Parameter | Symbol | Minimum | Typical | Maximum | Units | Comment |
|---|---|---|---|---|---|---|
| Input Voltage High | V IH | 0.65*IOVDD | | IOVDD + 0.3 | V | Square Wave input. XIN only. XOUT floating |
| Input Voltage Low  | V IL | 0 | | 0.35*IOVDD  | V | Square Wave input. XIN only. XOUT floating |

<!-- image -->

## NOTE

By default, USB Bootmode relies on a 12MHz input being present. However OTP can be configured to override the XOSC and PLL settings during USB Bootmode. See Section 13.10 for details.

See Section 8.2 for more details on the Oscillator, and the Minimal Design Example in Hardware design with RP2350 for information on crystal usage.

| Parameter | Symbol | Minimum | Typical | Maximum | Units | Comment |
|---|---|---|---|---|---|---|
| SWCLK Input Frequency | f SWCLK  | 0 | 10 | 50 | MHz | See Table 1430 for SWCLK pin definitions. |

Host-to-target data on the SWDIO pin should be transmitted centre-aligned with SWCLK . Target-to-host data on the SWDIO pin transitions on rising edges of SWCLK .

<!-- image -->

## NOTE

RP2350 internal SWD logic in the SW-DP operates reliably up to 50 MHz. However, signal integrity of the external SWD signals may be a challenge.

If you observe unreliable SWD operation such as write data parity errors from the SW-DP, reduce the SWCLK frequency. Always connect ground directly between the SWD probe and RP2350 in addition to SWDIO and SWCLK . Minimise the wire length between the probe and RP2350, and avoid multi-drop wiring at higher frequencies.

## 14.9.4.1. Interpreting GPIO output voltage specifications

The GPIOs on RP2350 have four different output drive strengths, nominally called 2, 4, 8 and 12mA modes. These are not hard limits, nor do they mean that they will always source (or sink) the selected amount of milliamps.

The amount of current a GPIO sources or sinks is dependent on the load attached. It will attempt to drive the output to the IOVDD level (or 0V in the case of a logic 0), but the amount of current it is able to source is limited and dependent on the selected drive strength.

Therefore the higher the current load is, the lower the voltage will be at the pin. At some point, the GPIO will source so much current and the voltage will drop so low that it won't be recognised as a logic 1 by the input of a connected device. The output specifications in Table 1436 quantify how much lower the voltage can be expected to be when drawing specified amounts of current from the pin.

The Output High Voltage (VOH) is defined as the lowest voltage the output pin can be when driven to a logic 1 with a particular  selected  drive  strength;  e.g.,  4mA  sourced  by  the  pin  whilst  in  4mA  drive  strength  mode.  The  Output  Low Voltage is similar, but with a logic 0 being driven.

In addition to this, the sum of all the IO currents being sourced (i.e. when outputs are being driven high) from the IOVDD bank (essentially the GPIO and QSPI pins), must not exceed I IOVDD\_MAX . Similarly, the sum of all the IO currents being sunk (i.e. when the outputs are being driven low) must not exceed I IOVSS\_MAX .

Voltage at GPIO pin (V)

3.5

2.5

1.5

1.2

E 0.8

0.6

0.4

0.2

Voltage at GPIO pin :

Figure 150. Typical Current vs Voltage curves of a GPIO output.

— 2mA setting

— 2mA setting

Table 1441. Power Supply Specifications

Typical GPIO Output High IV curve

....

Figure 150 shows the effect on the output voltage as the current load on the pin increases. You can clearly see the effect of the different drive strengths; the higher the drive strength, the closer the output voltage is to IOVDD (or 0V) for a given current. The minimum VOH and maximum VOL limits are shown in red.

<!-- image -->

You can see that at the specified current for each drive strength, the voltage is well within the allowed limits, meaning that this particular device could drive a lot more current and still be within V OH /VOL specification. This is a typical part at room temperature, but because devices vary, there will be a spread of other devices which will have voltages much closer to this limit.

If  your  application doesn't need such tightly controlled voltages, you can source or sink more current from the GPIO than the selected drive strength setting. However, experimentation is required to determine if it indeed safe to do so in your application.

## 14.9.5. Power supplies

| Power Supply | Supplies | Min | Typ | Max | Units |
|---|---|---|---|---|---|
| IOVDD a | Digital IO | 1.62  | 1.8 / 3.3 |  3.63 | V |
| QSPI_IOVDD (RP2350 only) a | Digital IO | 1.62  | 1.8 / 3.3 |  3.63 | V |
| QSPI_IOVDD (RP2354 only) | Digital IO | 2.97  | 3.3 |  3.63 | V |
| DVDD b | Digital core | 1.05  | 1.1 |  1.16 | V |
| VREG_VIN | Voltage regulator | 2.7 | 3.3 |  5.5  | V |
| VREG_AVDD | Voltage regulator | 3.135 | 3.3 |  3.63 | V |

Table 1442. Voltage Regulator Specifications

| Power Supply | Supplies | Min | Typ | Max | Units |
|---|---|---|---|---|---|
| USB_OTP_VDD | USB PHY & OTP | 3.135 | 3.3 |  3.63 | V |
| ADC_AVDD c | ADC | 1.62  | 3.3 |  3.63 | V |

<!-- image -->

##  NOTE

RP2354 contains an internal 3.3V flash device, therefore QSPI\_IOVDD must be 3.3V. Furthermore, if the QSPI pins are to be used to connect to an additional flash or PSRAM device, then IOVDD must be 3.3V, as a GPIO is used as QSPI chip select in this case.

## 14.9.6. Core voltage regulator

| Parameter | Description | Min | Typ | Max | Units |
|---|---|---|---|---|---|
| V OUT (normal mode) | regulated output voltage range (normal mode) | 0.55  | 1.1 | 3.3 | V |
| V OUT (low power mode) | regulated output voltage range (low power mode) | 0.55  | 1.1 | 1.3 | V |
| Δ V OUT (normal mode) | voltage deviation from programmed value (normal mode) | -3 | | 3 | % of selected output voltage |
| Δ V OUT (low power mode) | voltage deviation from programmed value (low power mode) | -9 | | 9 | % of selected output voltage |
| I MAX (normal mode) | output current (normal mode) | | | 200 | mA |
| I MAX (low power mode) | output current (low power mode) | | | 1 | mA |
| I LIMIT (normal mode startup) | current limit (normal mode startup) | | 240 | 300 | mA |
| I LIMIT (normal mode) | current limit (normal mode) | 260 | 500 | 800 | mA |
| I LIMIT (low power mode) | current limit (low power mode) | 5 | |  25 | mA |
| VOUT_OK TH.ASSERT | VOUT_OK assertion threshold | 87 | 90 |  93 | % of selected output voltage |

0.9

0.8

0.7 #

0.4

0.3

0.2

Figure 151. Typical Regulator Efficiency, Vout =1.1V, VREG\_VIN=3.3V.

Typical Regulator Efficiency

| Parameter | Description | Min | Typ | Max | Units |
|---|---|---|---|---|---|
| VOUT_OK TH.DEASSERT | VOUT_OK de- assertion threshold | 84 | 87 | 90 | % of selected output voltage |
| f sw | switching frequency | | 3 | | MHz |
| Efficiency (V OUT =1.1V) | I load =10mA, VREG_VIN=2.7V | | 74 | | % |
| Efficiency (V OUT =1.1V) | I load =10mA, VREG_VIN=3.3V | | 70 | | % |
| Efficiency (V OUT =1.1V) | I load =10mA, VREG_VIN=5.5V | | 59 | | % |
| Efficiency (V OUT =1.1V) | I load =100mA, VREG_VIN=2.7V | | 70 | | % |
| Efficiency (V OUT =1.1V) | I load =100mA, VREG_VIN=3.3V | | 72 | | % |
| Efficiency (V OUT =1.1V) | I load =100mA, VREG_VIN=5.5V | | 72 | | % |
| Efficiency (V OUT =1.1V) | I load =200mA, VREG_VIN=2.7V | | 70 | | % |
| Efficiency (V OUT =1.1V) | I load =200mA, VREG_VIN=3.3V | | 59 | | % |
| Efficiency (V OUT =1.1V) | I load =200mA, VREG_VIN=5.5V | | 63 | | % |

<!-- image -->

##  WARNING

VOUT can  exceed  the  maximum  core  supply  ( DVDD ).  While  there  is  a  voltage  limit  to  prevent  this  happening accidentally,  the  limit  can  be  disabled  under  software  control.  For  reliable  operation DVDD should  not  exceed  its maximum voltage rating.

<!-- image -->

## 14.9.7. Power consumption

Table 1443. Baseline power consumption

Table 1444. Baseline power consumption for ADC and USBCTRL

## 14.9.7.1. Peripheral power consumption

Baseline readings are taken with only clock sources and essential peripherals (BUSCTRL, BUSFAB, VREG, Resets, ROM, SRAMs) active in the WAKE\_EN0 / WAKE\_EN1 registers. Clocks are set to default clock settings.

Each peripheral is activated in turn by enabling all clock sources for the peripheral in the WAKE\_EN0 / WAKE\_EN1 registers. Current consumption is the increase in current when the peripheral clocks are enabled.

| Peripheral | Typical DVDD Current Consumption ( μ A/MHz) |
|---|---|
| DMA | 2.6 |
| I2C0 | 3 |
| I2C1 | 3.6 |
| IO + Pads | 24.5 |
| PWM | 9.9 |
| SIO | 2 |
| SHA256 | 0.1 |
| SPI0 | 1.7 |
| SPI1 | 1.4 |
| Timer 0 | 0.8 |
| Timer 1 | 0.6 |
| TRNG | 0.8 |
| UART0 | 2.6 |
| UART1 | 3.6 |
| Watchdog | 1.1 |
| XIP | 37.6 |

Because of fixed  reference  clocks  of  48MHz,  as  well  as  the  variable  system  clock  input,  ADC  and  USBCTRL  power consumption does not vary linearly with system clock (as it does for other peripherals which only have system and/or peripheral  clock  inputs).  The  following  table  shows  absolute  DVDD  current  consumption  of  the  ADC  and  USBCTRL blocks at standard clocks settings:

| Peripheral | Typical DVDD Current Consumption (mA) |
|---|---|
| ADC | 0.14 |
| USBCTRL | 1.25 |

## 14.9.7.2. Power consumption in Low Power states

Table 1445 shows the typical power consumption in low power states P1.0 → P1.7 . All voltage supplies are 3.3V (except DVDD which is supplied by the voltage regulator (in low power mode)), with the environment at room temperature.

All GPIOs, SWDIO and SWCLK are pulled down  internally, and  not connected  externally. QSPI  is  connected  to W25Q16JVSSIQ flash device. USB PHY has been powered down, and the DP and DM pull-downs were enabled prior to entering the low power state. The USB cable remains connected to a host computer. The table also shows the power consumed when RUN is held low. This is not technically a low power state (the voltage regulator is in normal switching mode), but it is included for completeness.

Table 1445. Low Power States Power Consumption

Table 1446. Power Consumption

| Low Power State | VREG_VIN ( μ A) | VREG_AVDD ( μ A) | IOVDD ( μ A) | QSPI_IOVDD ( μ A) | ADC_IOVDD ( μ A) | USB_OTP_VDD ( μ A) | Total Power ( μ W) |
|---|---|---|---|---|---|---|---|
| P1.0 | 128 | 0.5 | 11 | 22 | 1 | 3.5 | 548 |
| P1.1 | 77 | 0.5 | 11 | 22 | 1 | 3.5 | 380 |
| P1.2 | 79 | 0.5 | 11 | 22 | 1 | 3.5 | 380 |
| P1.3 | 26 | 0.5 | 11 | 22 | 1 | 3.5 | 204 |
| P1.4 | 120 | 0.5 | 11 | 22 | 1 | 3.5 | 520 |
| P1.5 | 67 | 0.5 | 11 | 22 | 1 | 3.5 | 345 |
| P1.6 | 68 | 0.5 | 11 | 22 | 1 | 3.5 | 350 |
| P1.7 | 19 | 0.5 | 11 | 22 | 1 | 3.5 | 188 |
| RUN=low | 40 | 187 | 69 | 22 | 1 | 35 | 1170 |

## 14.9.7.3. Power consumption for typical user cases

The following table details the typical power consumption of RP2350 in various example use cases. All measurements were taken using 3.3V voltage supplies (except DVDD, which is supplied by the voltage regulator (set to 1.1V)), with the environment at room temperature.

SWD and SWCLK are not connected externally. GPIO0 and GPIO1 are connected to a Raspberry Pi Debug Probe (UART), but all  other  GPIOs are not connected (except USB Boot mode, where GPIO0 and GPIO1 are also unconnected). QSPI is connected to W25Q16JVSSIQ flash device, and USB is connected to a host.

hello\_serial , hello\_usb and hello\_adc are  basic  applications  found  in  pico-examples  where  characters  are  constantly transmitted to a serial console.

| Use Case | Condition | VREG_VIN ( μ A) | VREG_AVDD ( μ A) | IOVDD ( μ A) | QSPI_IOVDD ( μ A | ADC_IOVDD ( μ A) | USB_OTP_VDD ( μ A) | Total Power (mW) |
|---|---|---|---|---|---|---|---|---|
| USB Boot mode | Bus Idle (average) | 6530 | 220 | 437 | 22 | 1 | 375 | 25 |
| USB Boot mode | During Boot (peak) | | | | | | 6050 | |
| USB Boot mode | During UF2 write (average) | | | | | | 1280 | |
| hello_serial | | 14690 | 216 | 506 | 22 | 1 | 62 | 51.1 |
| hello_usb | | 14700 | 216 | 453 | 22 | 1 | 570 | 52.7 |
| hello_adc | | 14680 | 216 | 506 | 22 | 142 | 62 | 51.6 |
| CoreMark benchmark | Single core @150MHz | 11000 | 212 | 455 | 22 | 1 | 90 | 38.7 |

## 14.9.7.3.1. Power consumption versus frequency

There is a relationship between the core RP2350 frequency and the current consumed by the DVDD supply. Figure 152 shows the measured results of a typical RP2350 device that continuously runs CoreMark benchmark tests on a single core at various core clock frequencies.

35

30

25

20

15

10

5

0

Figure 152. DVDD Current vs Core Frequency of a typical RP2350 device, whilst running CoreMark benchmark

50

<!-- image -->

## Appendix A: Register field types

## Changes from RP2040

Register field types are unchanged.

## Standard types

## RW:

- Read/Write
- Read operation returns the register value
- Write operation updates the register value

## RO:

- Read-only
- Read operation returns the register value
- Write operations are ignored

## WO:

- Write-only
- Read operation returns 0
- Write operation updates the register value

## Clear types

## SC:

- Self-Clearing
- Writing a 1 to a bit in an SC field will trigger an event, once the event is triggered the bit clears automatically
- Writing a 0 to a bit in an SC field does nothing

## WC:

- Write-Clear
- Writing a 1 to a bit in a WC field will write that bit to 0

- Writing a 0 to a bit in a WC field does nothing
- Read operation returns the register value

## FIFO types

These fields are used for reading and writing data to and from FIFOs. Accompanying registers provide FIFO control and status. There is no fixed format for the control and status registers, as they are specific to each FIFO interface.

## RWF:

- Read/Write FIFO
- Reading this field returns data from a FIFO
- When the read is complete, the data value is removed from the FIFO
- If the FIFO is empty, a default value will be returned; the default value is specific to each FIFO interface
- Data written to this field is pushed to a FIFO, Behaviour when the FIFO is full is specific to each FIFO interface
- Read and write operations may access different FIFOs

## RF:

- Read FIFO
- Functions the same as RWF, but read-only

## WF:

- Write FIFO
- Functions the same as RWF, but write-only

## Appendix B: Units used in this document

This datasheet follows standard practice for use of SI units as recommended by NIST, except in the context of memory and storage capacity. Here it adopts the convention that the prefixes k ( kilo ), M ( mega ) and G ( giga ) always refer to the nearest power of two to their standard decimal value. This aligns the datasheet with common usage for these units.

## Memory and storage capacity

This datasheet expresses memory and storage capacity using the following units:

- b: bit
- kb: kilobit, 2 10 b = 1024 b
- Mb: megabit, 2 20 b = 1,048,576 b
- Gb: gigabit, 2 30 b = 1,073,741,824 b
- B: byte, eight bits, one octet
- kB: kilobyte, 2 10 B = 1024 B
- MB: megabyte, 2 20 B = 1,048,576 B
- GB: gigabyte, 2 30 B = 1,073,741,824 B

The bit is the most basic unit of information. A bit is either true ( 1 ) or false ( 0 ).

## Transfer Rate

Units for transfer rate are dimensionally the product of one byte or bit with a unit of frequency such as MHz. Therefore the standard SI prefixes apply:

- b/s: bit per second
- kb/s: kilobit per second, 1000 b/s
- Mb/s: megabit per second, 1,000,000 b/s
- Gb/s: gigabit per second, 1,000,000,000 b/s
- B/s: byte per second, 8 b/s
- kB/s: kilobyte per second, 1000 B/s
- MB/s: megabyte per second, 1,000,000 B/s
- GB/s: gigabyte per second, 1,000,000,000 B/s

## Physical Quantities

The following units express physical quantities such as voltage and frequency:

- A: ampere, unit of electrical current, one coulomb per second

- mA: milliampere, 10 -3 A
- μ A: microampere, 10 -6 A · Ω : ohm, unit of electrical impedance or resistance, one volt per ampere ◦ M Ω : megohm, 10 6 Ω ◦ k Ω : kilohm, 10 3 Ω ◦ m Ω : milliohm, 10 -3 Ω · V: volt, unit of electrical potential difference, one joule per coulomb ◦ kV: kilovolt, 10 3 V ◦ mV: millivolt, 10 -3 V ◦ μ V: microvolt, 10 -6 V · Hz: hertz, unit of frequency, one period per second (s -1 ) ◦ kHz: kilohertz, 10 3  Hz ◦ MHz: megahertz, 10 6  Hz ◦ GHz: gigahertz, 10 9  Hz · F: farad, unit of electrical capacitance, one coulomb per volt ◦ mF: millifarad, 10 -3 F ◦ μ F: microfarad, 10 -6 F ◦ nF: nanofarad, 10 -9 F ◦ pF: picofarad, 10 -12 F · H: henry, unit of electrical inductance, one volt-second per ampere (VsA -1 ) ◦ mH: millihenry, 10 -3  H ◦ μ H: microhenry, 10 -6  H ◦ nH: nanohenry, 10 -9  H · s: second, unit of time ◦ ms: millisecond, 10 -3 s ◦ μ s: microsecond, 10 -6 s ◦ ns: nanosecond, 10 -9 s ◦ ps: picosecond, 10 -12 s · J: joule, unit of energy or work, one newton-metre · C: coulomb, unit of electrical charge ◦ mC: millicoulomb, 10 -3 C ◦ μ C: microcoulomb, 10 -6 C ◦ nC: nanocoulomb, 10 -9 C · m: metre, unit of length or distance ◦ mm: millimetre, 10 -3  m · °C: degree celsius, unit of temperature · W: watt, unit of power, one joule per second (Js -1 ) or one volt-ampere (VA)

- mW: milliwatt, 10 -3  W
- μ W: microwatt, 10 -6  W
- nW: nanowatt, 10 -9  W

## Scale Prefixes

The standard SI prefixes used in the previous sections are:

- G: giga, factor of 10 9 (one short billion)
- M: mega, factor of 10 6 (one million)
- k: kilo, factor of 10 3 (one thousand)
- c: centi, factor of 10 -2 (one hundredth)
- m: milli, factor of 10 -3 (one thousandth)
- μ , micro, factor of 10 -6 (one millionth)
- n: nano, factor of 10 -9 (one short billionth)
- p: pico, factor of 10 -12 (one short trillionth)

The customary binary prefixes used in the memory and storage capacity section are:

- G: giga, factor of 2 30 (approximately 10 9 )
- M: mega, factor of 2 20 (approximately 10 6 )
- k: kilo, factor of 2 10 (approximately 10 3 )

These customary binary prefixes are equivalent to the following prefixes from IEC 60027-2:

- Gi, gibi
- Mi, mebi
- Ki, kibi

## Digit Separators

Numbers written out with many digits may have either commas or spaces inserted for easier reading:

- 1,000,000: one million
- 1 000 000: one million

A comma in a number never represents a decimal (radix) point.

## Appendix C: Hardware revision history

This appendix summarises the differences between RP2350 hardware revisions, referred to as steppings . To determine the stepping of an unknown device, check the package markings, as described in Section 14.4. Software running on the device can also read the CHIP\_ID.REVISION register field, or call the rp2350\_chip\_version() SDK function.

In this appendix:

- The term fix refers to an issue that's fully resolved.
- The term mitigate refers to an issue that's either partially resolved or believed to be fully resolved but with an unpredictable underlying cause, such as a fault injection vulnerability.
- The term update refers to any other difference between steppings.

This appendix offers a high-level overview; for detailed information, refer to individual errata entries in appendix E.

## RP2350 A2

Stepping A2 is identified by a CHIP\_ID.REVISION value of 0x2 .

A2 is the first generally available version of RP2350, and the earliest stepping documented in this datasheet.

## RP2350 A3

Stepping A3 is identified by a CHIP\_ID.REVISION value of 0x3 .

## Hardware changes

Stepping A3 introduces the following hardware fixes and mitigations:

- Fix RP2350-E3 : in QFN-60 package, GPIO\_NSMASK controls wrong PADS registers. Hardware now remaps GPIO\_NSMASK to the correct PADS registers in the QFN60 package.
- Fix RP2350-E9 : increased leakage current on Bank 0 GPIO when pad input is enabled. The pad circuit is modified to eliminate the erroneous leakage path through the input buffer.
- Mitigate RP2350-E12 : inadequate synchronisation of USB status signals. Signals used by the bootrom are now valid across the full PVT range in the bootrom's clock configuration. Other software must not rely on these mitigations.
- Mitigate RP2350-E16 : USB\_OTP\_VDD disruption can cause corrupt OTP row read data. The following changes apply:
- Multiple changes to the OTP PSM and OTP read circuits to detect unreliable operation.
- RISC-V debug is now disabled by CRIT1.SECURE\_DEBUG\_DISABLE, in addition to CRIT1.DEBUG\_DISABLE. (On A2, only the latter bit was used.)
- CRIT0.ARM\_DISABLE no longer disables the Arm processors.
- Programming both CRIT0.ARM\_DISABLE and CRIT0.RISCV\_DISABLE is decoded as an illegal combination, and the device won't boot.

- Update the reset state of the following clock configuration registers:
- ROSC: FREQA.DS0\_RANDOM and FREQA.DS1\_RANDOM from 0 to 1 , enabling randomisation of first two drive stages.
- CLOCKS: CLK\_SYS\_CTRL.SRC from 0 to 1 (select AUX source).
- CLOCKS: CLK\_SYS\_CTRL.AUXSRC from 0 to 2 (select ROSC as AUX source).

## Bootrom changes

The A3 bootrom introduces the following changes:

- Fix RP2350-E10 : UF2 drag-and-drop doesn't work with partition tables. This previously required a workaround in picotool , but the A3 bootrom no longer requires this workaround. picotool retains the workaround for compatibility with A2.
- Fix RP2350-E13 : a binary containing an explicitly invalid IMAGE\_DEF followed by a valid IMAGE\_DEF (in that order) fails to boot.
- Fix RP2350-E14 : the bootrom connect\_internal\_flash() function always uses pin 0, ignoring any configured FLASH\_DEVINFO CS1 chip select pin.
- Fix RP2350-E15 : the bootrom otp\_access() function applies incorrect access permission to pages 62 and 63.
- Fix RP2350-E19 : RP2350 reboot halts if certain bits are set in FRCE\_OFF when rebooting.
- Mitigate RP2350-E20 : an attacker with physical access to the chip and the ability to physically glitch the CPU at precise times could cause unsigned code execution on a secured RP2350 by targeting legitimate Non-secure calls to the bootrom reboot() function.
- Mitigate RP2350-E21 : an attacker with physical access to the chip and the ability to physically glitch the CPU at precise times, could extract sensitive data from OTP on a RP2350 in BOOTSEL mode.
- Fix RP2350-E22 : parsing a malformed lollipop block loop causes the system to halt rather than fail.
- Fix RP2350-E23 : PICOBOOT GET\_INFO command always returns zero for PACKAGE\_SEL)
- Mitigate RP2350-E26 : RCP random delays can create a side-channel. These delays are disabled in the bootrom.
- Update the early boot path to change the clk\_ref divider from 1 to 5 , and the ROSC divider from 8 to 2 .
- Together with the register reset state changes, this increases the boot clk\_sys frequency by a factor of 4, to approximately 48 MHz.
- These changes reduce boot time and fault injection susceptibility.
- These changes apply for all boot outcomes, including watchdog and POWMAN vector boot.

## RP2350 A4

Stepping A4 is identified by a CHIP\_ID.REVISION value of 0x8 .

## Hardware Changes

This stepping has no hardware changes.

## Bootrom Changes

The A4 bootrom introduces the following changes:

- Fix RP2350-E18 : the RP2350 forever fails to boot if FLASH\_PARTITION\_SLOT\_SIZE contains an invalid ECC bit pattern. This issue is a consequence of RP2350-E17 (a guarded read on a single ECC OTP row causes a fault if the data in the adjacent row isn't also valid ECC data). The underlying hardware issue isn't resolved, but the bootrom avoids the issue in this instance.
- Mitigate RP2350-E24 : an attacker with physical access to the chip, moderate hardware, and the ability to physically glitch the CPU at precise times, could cause unsigned code execution on a secured RP2350. The A4 bootrom contains additional fault injection mitigations for this vulnerability, and for other potential vulnerabilities with the same underlying mechanism.
- Fix RP2350-E25 : a LOAD\_MAP that uses non-word sizes previously didn't cause an error. The bootrom now correctly rejects these structures.

## Appendix E: Errata

Alphabetical by section.

## ACCESSCTRL

## RP2350-E3

| Reference | RP2350-E3 |
|---|---|
| Summary | In QFN-60 package, GPIO_NSMASK controls wrong PADS registers |
| Affects | RP2350 A2, QFN-60 package only |
| Description | RP2350 remaps IOs, their control registers and their ADC channels so that both package sizes appear to have consecutively numbered GPIOs, even though for physical design reasons the QFN-60 package bonds out a sparse selection of IO pads. The connection between the GPIO_NSMASK0/GPIO_NSMASK1 registers and the PADS registers doesn't take this remapping into account. Consequently, in the QFN-60 package only, the GPIO_NSMASK0 register bits are applied to registers for the wrong pads. Specifically, PADS_BANK0 registers 29 through 0 are controlled by the concatenation of GPIO_NSMASK bits 47 through 44, 39 through 33, 30 through 28, 24 through 17 and 15 through 8 (all inclusive ranges). This means that granting Non-secure access to the PADS registers in the QFN-60 package doesn't allow Non-secure software to control the correct pads. It may also allow Non-secure control of pads that aren't granted in GPIO_NSMASK0 . |
| Workaround  | Disable Non-secure access to the PADS registers by clearing PADS_BANK0.NSP, NSU . Implement a Secure Gateway (Arm) or ecall handler (RISC-V) to permit Non-Secure/U-mode code to read/write its assigned PADS_BANK0 registers. |
| Fixed by | RP2350 A3, Documentation, Software |

## Bootrom

## RP2350-E10

| Reference | RP2350-E10 |
|---|---|
| Summary | UF2 drag-and-drop doesn't work with partition tables |
| Affects | RP2350 A2 |
| Description | When dragging and dropping a UF2 onto the USB Mass Storage Device, the bootrom on chip revision A2 doesn't set up the flash before checking the partition table. This causes the UF2 download to fail if there is a partition table present. |

| Workaround | Add a single block at the start of the UF2 with an Absolute family ID, targeting the end of Flash, with block number set to 0 and number of blocks set to 2. This block is written to flash first but doesn't reboot the device, and sets up the flash for the rest of the UF2 to be downloaded correctly. This is handled for you automatically by picotool in the SDK, which adds this block when generating UF2s if the --abs-block flag is specified. This workaround means that the last block of flash is erased when downloading such a UF2, which could overwrite user data. As of picotool version 2.1.0, this additional UF2 block is marked with a Raspberry Pi specific UF2 extension UF2_EXTENSION_RP2_IGNORE_BLOCK ( 0x9957e304 ). The RP2350 A3 and later bootroms, contain a fix for this erratum, and therefore don't need the workaround. The presence of this extension in the UF2 block allows the newer RP2350 to recognize and ignore the workaround block, thus avoiding the risk of |
|---|---|
| Fixed by | RP2350 A3 bootrom, Documentation, Software |

## RP2350-E13

| Reference | RP2350-E13 |
|---|---|
| Summary | A binary containing an explicitly invalid IMAGE_DEF followed by a valid IMAGE_DEF (in that order) fails to boot |
| Affects | RP2350 A2 |
| Description | When the block loop of a binary contains an IMAGE_DEF that is explicitly invalid before the valid IMAGE_DEF for RP2350, booting from that binary fails. An IMAGE_DEF is explicitly invalid if either: • It is for RP2040 • It doesn't have a rollback version, and the BOOT_FLAGS0.ROLLBACK_REQUIRED flag is set in OTP |
| Workaround  | Instead of an explicitly invalid IMAGE_DEF , use an IGNORED item. RP2040 doesn't require an IMAGE_DEF to boot a binary, and when using rollback, the invalid IMAGE_DEF is ignored anyway. SDK uses this workaround for RP2040 binaries. When you set PICO_CRT0_INCLUDE_PICOBIN_BLOCK , the SDK uses an IGNORED item instead of an IMAGE_DEF for RP2040 binaries. You can override this behaviour and use an IMAGE_DEF by setting PICO_CRT0_INCLUDE_PICOBIN_IMAGE_TYPE_ITEM . For an additional example, see the universal binaries in pico-examples. picotool uses this workaround for rollback versions. When you use picotool seal to seal a binary and add a rollback version, it converts the first IMAGE_DEF without a rollback version to an IGNORED item. |
| Fixed by | RP2350 A3 bootrom, Documentation, Software |

## RP2350-E14

| Reference | RP2350-E14 |
|---|---|
| Summary | The bootrom connect_internal_flash() function always uses pin 0, ignoring any configured FLASH_DEVINFO CS1 chip select pin |
| Affects | RP2350 A2 |

| Description | When using the bootrom function connect_internal_flash() to configure CS1 (for instance, during a flash boot), the bootrom always configures the pad registers for pin 0, ignoring any CS1 pin specified in FLASH_DEVINFO. As a result, the specified CS1 pin remains isolated (see Section 9.7). Accesses to the QSPI device connected to the second chip select fails unless CS1 is connected to pin 0. FLASH_DEVINFO can be configured in OTP or at runtime. For more information, see flash_devinfo16_ptr. |
|---|---|
| Workaround | Manually configure the CS1 pads registers to remove the isolation after using the bootrom connect_internal_flash() function. Alternatively, connect CS1 to pin 0. |
| Fixed by | RP2350 A3 bootrom, Documentation, Software |

## RP2350-E15

| Reference | RP2350-E15 |
|---|---|
| Summary | The bootrom otp_access() function applies incorrect access permission to pages 62 & 63 |
| Affects | RP2350 A2 |
| Description | The bootrom otp_access() function incorrectly applies the access permissions specified in OTP rows PAGE62_LOCK1 and PAGE63_LOCK1 to the entirety of their respective OTP pages (62 and 63). This is incorrect, as pages 62 and 63 contain lock words for other pages: each lock word is instead protected by the permissions of the corresponding page. The ATE programming then locks down write access from non-Secure software and the bootloader to the page 63 lock word (to prevent non-Secure setting of the RMA flag), and write access from non-Secure software to the page 62 lock word. This prevents non-Secure software from modifying any of the OTP page locks, and the bootloader from modifying the locks for pages 32-63. |
| Workaround  | When running code on the device, don't use the non-Secure otp_access() function to set locks for OTP pages. To set OTP page locks from non-Secure code, implement your own Secure API to do this that can be called from non-Secure code. Page locks for OTP pages 32-63 can be set by picotool using the picotool otp permissions command. This command loads a Secure binary into XIP SRAM on the device to change the permissions before rebooting back into the USB bootloader. |
| Fixed by | RP2350 A3 bootrom, Documentation, Software |

## RP2350-E18

| Reference | RP2350-E18 |
|---|---|
| Summary | The RP2350 will forever fail to boot if FLASH_PARTITION_SLOT_SIZE contains an invalid ECC bit pattern |
| Affects | RP2350 A2, RP2350 A3 |

| Description | If ECC row programming is interrupted, an ECC row may contain a value that fails ECC validation. Because any ECC could potentially contain an invalid, partially written value, the bootrom uses a separate "enable" flag in OTP to indicate whether a particular ECC row is expected to contain a valid value. The user is expected to only set this flag after a particular ECC row is known to have been written correctly. For FLASH_PARTITION_SLOT_SIZE, the "enable" flag is BOOT_FLAGS0.OVERRIDE_FLASH_PARTITION_SLOT_SIZE. In the case of FLASH_PARTITION_SLOT_SIZE, the bootrom reads the row value and asserts the value is valid before checking the enable flag, and thus the boot process will hang if the BOOT_FLAGS0.OVERRIDE_FLASH_PARTITION_SLOT_SIZE row in OTP contains an invalid ECC value. |
|---|---|
| Workaround | Don't program FLASH_PARTITION_SLOT_SIZE or at least be aware that doing so may brick your device if the programming operation is interrupted or fails. |
| Fixed by | RP2350 A4 bootrom, Documentation |

## RP2350-E19

| Reference | RP2350-E19 |
|---|---|
| Summary | RP2350 reboot hangs if certain bits are set in FRCE_OFF when rebooting. |
| Affects | RP2350 A2 |
| Description | An incorrect assertion in the boot path, assumes the all bits (other than FRCE_OFF.PROC1) are clear. These bits can only be set during boot if the user had set them and then re-entered the boot path. |
| Workaround  | Don't perform a WATCHDOG or POWMAN boot, or a core0 reset with bits other than FRCE_OFF.PROC1 set. |
| Fixed by | RP2350 A3 bootrom, Documentation |

## RP2350-E20

| Reference | RP2350-E20 |
|---|---|
| Summary | An attacker with physical access to the chip and the ability to physically "glitch" the CPU at precise times, could cause unsigned code execution on a secured RP2350 by targeting legitimate Non-secure calls to the bootrom reboot() function |
| Affects | RP2350 A2 |
| Description | The RP2350 bootrom provides a reboot() function to reboot the RP2350. This method is potentially accessible to Non-secure callers via the PICOBOOT interface (e.g. picotool ) or, if the corresponding permission is set, to Non-secure code running on the device. A particular reboot type ( REBOOT_TYPE_PC_SP ) isn't allowed in the bootrom reboot() function when called from Non-secure code as it launches user-provided code in a Secure state post reboot. The reboot() function correctly disallows this reboot type when called from a Non-secure context. However, if a valid reboot type (e.g. REBOOT_TYPE_NORMAL ) is passed to the function instead, a late, precisely-timed processor glitch can cause an incorrect code path to be taken, which configures the WATCHDOG scratch registers in a way that allows secure execution of user-provided code post reboot. |

| Workaround | If any WATCHDOG based reboot types other than into the regular boot path aren't required (this includes programmatic reboots into BOOTSEL mode and FLASH_UPDATE boots which are important when using A/B partitions), the OTP flag BOOT_FLAGS0.DISABLE_WATCHDOG_SCRATCH can be set, which causes the WATCHDOG scratch registers to be completely ignored during boot, meaning that the only type of boot available via WATCHDOG reset is regular boot. A more refined approach would be to disable use of the reboot() function from Non-secure code. This is the default case for Non-secure code started by a secure application (see Section 5.4.2). However, the BOOTSEL mode bootloader is itself a Non-secure application that does have access to the function. BOOTSEL mode, however, can be disabled if not needed through BOOT_FLAGS0.DISABLE_BOOTSEL_UART_BOOT, BOOT_FLAGS0.DISABLE_BOOTSEL_USB_PICOBOOT_IFC, and BOOT_FLAGS0.DISABLE_BOOTSEL_USB_MSD_IFC. BOOT_FLAGS0.DISABLE_BOOTSEL_USB_PICOBOOT_IFC is the most important because PICOBOOT provides a conduit for a user to pass specific parameters to the bootrom reboot() function. However, any other use of BOOTSEL mode could be vulnerable in conjunction with some other future attack on the Non-secure code. |
|---|---|
| Credit | Marius Muench |
| Fixed by | RP2350 A3 bootrom, Documentation |

## RP2350-E21

| Reference | RP2350-E21 |
|---|---|
| Summary | An attacker with physical access to the chip, and the ability to physically "glitch" the CPU at precise times, could potentially extract sensitive data from OTP on a RP2350 in BOOTSEL mode. |
| Affects | RP2350 A2 |
| Description | An attacker with physical access to the chip, could precisely time physical glitch attacks during entry to BOOTSEL mode and cause some OTP page access permissions for BOOTSEL mode not to be applied, leading to possible exposure of sensitive data. The RP2350 BOOTSEL mode exposes an API over PICOBOOT such that a user can read or write OTP rows through picotool . Certain OTP rows (such as encryption keys or other secrets) shouldn't be readable through this method. Equally, certain rows might be protected against writes. This is handled at the page (64 row) level by page locks stored in OTP. On entry to BOOTSEL mode, the OTP should be locked down such that no software (including Secure software) can access anything not marked as accessible to BOOTSEL mode. However, with two precisely timed processor glitches, it's possible to prevent a page being correctly locked. |
| Workaround  | 1. Disable the BOOTSEL mode bootloader altogether via BOOT_FLAGS0.DISABLE_BOOTSEL_UART_BOOT, BOOT_FLAGS0.DISABLE_BOOTSEL_USB_PICOBOOT_IFC, and BOOT_FLAGS0.DISABLE_BOOTSEL_USB_MSD_IFC. BOOT_FLAGS0.DISABLE_BOOTSEL_USB_PICOBOOT_IFC is the most important, as PICOBOOT provides the conduit for a user to access the OTP, however any other use of BOOTSEL mode could be vulnerable in conjunction with some other future attack on the non-Secure code. 1. Use an OTP access key (Section 13.5.2) to protect OTP data you don't want accessed from BOOTSEL mode, although this only helps if the data isn't needed until your application can provide the key. |
| Credit | Thomas Roth |

| Fixed by | RP2350 A3 bootrom, Documentation |
|---|---|

## RP2350-E22

| Reference | RP2350-E22 |
|---|---|
| Summary | Parsing a malformed "lollipop" block loop will cause a hang rather than a failure |
| Affects | RP2350 A2 |
| Description | PARTITION_TABLE s and IMAGE_DEF s metadata are stored as part of a block loop. These block loops are parsed during boot and at other times. A "lollipop" block loop is an invalid block loop, which loops back from the last block to a block, which isn't the first. Such an invalid block loop is never generated by the SDK or by picotool ; however, it could potentially be generated by other tooling. |
| Workaround  | Don't use "lollipop" block loops. If you program a "lollipop" block loop into flash such that it's read during the boot process, it will cause a boot hang and also a hang on entry into BOOTSEL mode. Therefore, to re- enable booting, you must clear the flash in some other way, for example, from the debugger over SWD. |
| Fixed by | RP2350 A3 bootrom, Documentation |

## RP2350-E23

| Reference | RP2350-E23 |
|---|---|
| Summary | PICOBOOT GET_INFO command always returns zero for PACKAGE_SEL |
| Affects | RP2350 A2 |
| Description | The PICOBOOT GET_INFO command can be used to get system information in a similar way to the bootrom get_sys_info() function. This information can include the value read from PACKAGE_SEL, which indicates whether the RP2350 package is QFN60 or QFN80. The SYSINFO block is erroneously left in reset when entering BOOTSEL mode, and thus this register is read as zero when accessed via PICOBOOT. This problem doesn't affect use of the bootrom get_sys_info() function itself from user code. |
| Workaround  | Determine the package size by reading register_link_macro:[register=OTP_DATA_NUM_GPIOS_ROW] via the PICOBOOT OTP_READ command instead. This workaround is used by picotool . |
| Fixed by | RP2350 A3 bootrom, Documentation, Software |

## RP2350-E24

| Reference | RP2350-E24 |
|---|---|
| Summary | An attacker with physical access to the chip, moderate hardware, and the ability to physically "glitch" the CPU at precise times, could cause unsigned code execution on a secured RP2350. |
| Affects | RP2350 A2, RP2350 A3 |

| Description | An attacker with physical access to the chip, and the ability to switch the contents of "flash" as read by the RP2350 over QSPI during boot at precise times, could, combined with a precisely-timed physical "glitch" attack of the CPU, trick the bootrom into checking the signature of data other than the program binary as loaded into memory during secure boot. If this "other" data passes the signature check, then the attacker's binary is executed without itself having passed a signature check, which allows the user to run arbitrary unsigned code on the RP2350. |
|---|---|
| Credit | Kévin Courdesses (see https://courk.cc/rp2350-challenge-laser#flash-memory-organization) |
| Workaround | None |
| Fixed by | RP2350 A4 bootrom |

## RP2350-E25

| Reference | RP2350-E25 |
|---|---|
| Summary | A LOAD_MAP that uses non-word sizes doesn't cause an error. |
| Affects | RP2350 A2, RP2350 A3 |
| Description | Non-word sizes in a LOAD_MAP aren't supported and were documented as such. However, they don't currently cause an error. Whilst non-word sizes might currently work in some certain cases, you should never use them because they might not work as you expect in all cases and can be properly treated as an error in the future. The SDK and picotool don't generate such LOAD_MAP s with non-word sized entries. |
| Workaround  | Don't use non-word (not multiple of 4) sizes in a LOAD_MAP . A best practice is to make sure that linker memory segments are both word-sized and word-aligned. As of the RP2350 A4 bootrom, non-word sizes are detected when checking the LOAD_MAP and cause the IMAGE_DEF to be considered invalid if present. |
| Fixed by | RP2350 A4 bootrom, Documentation |

## Bus Fabric

## RP2350-E27

| Reference | RP2350-E27 |
|---|---|
| Summary | Bus priority controls apply to wrong managers for APB and FASTPERI arbiters. |
| Affects | RP2350 A2, RP2350 A3, RP2350 A4 |

| Description | RP2350 bus fabric consists mainly of an AHB5 crossbar, where 6 upstream ports (managers) are routed to 15 downstream crossbar ports. Figure 5 shows the overall structure of the bus fabric, including this crossbar. Because there can be multiple accesses to a given downstream crossbar port on any one cycle, an arbiter circuit selects one transfer to forward to the downstream port, and stalls all other transfers targeting this port. The BUSCTRL BUS_PRIORITY register controls these arbiter circuits. It configures a 1-bit priority level for each of the following four groups of AHB5 managers: • DMA write • DMA read • Core 0 instruction fetch and core 0 load/store • Core 1 instruction fetch and core 1 load/store Accesses from high-priority managers are always routed preferentially over those from low-priority managers. Multiple accesses from managers of the same priority are processed one at a time, taking turns in a repeating cycle (round-robin arbitration). On the FASTPERI and APB arbiters, these signals are mis-wired, such that the wrong managers are prioritised: • BUS_PRIORITY.PROC0 controls DMA write priority • BUS_PRIORITY.PROC1 controls core 0 load/store priority • BUS_PRIORITY.DMA_R controls core 1 load/store priority • BUS_PRIORITY.DMA_W controls DMA read priority The BUS_PRIORITY controls are applied correctly for all other arbiters: ROM, SRAM, and XIP. For example, if the DMA_R and DMA_W bits were set, this would prioritise DMA over processor access to ROM, |
|---|---|
| Workaround | There is no complete fix, but the necessary prioritisation can often still be achieved by configuring BUS_PRIORITY for correct priority at the peripherals, and then arranging buffers in SRAM to minimise contention, such as using SRAM8 or SRAM9 as processor-private memories. Also consider the following approaches: • Split RAM access across the SRAM0 to SRAM3 and SRAM4 to SRAM7 striped regions to further reduce RAM contention. • Try to reduce overall peripheral bandwidth demand by using wider accesses for peripherals that support it. For example, SPI supports 16-bit data, and HSTX and PIO support 32-bit data. • Avoid processor polling of peripheral status registers. Instead, use interrupts or DMA DREQ signals. • Assess whether the default round-robin arbitration performs better than the reachable asymmetric priority configurations. |
| Fixed by | Documentation |

## DMA

RP2350-E5

| Reference | RP2350-E5 |
|---|---|
| Summary | Interactions between CHAIN_TO and ABORT of active channels |
| Affects | RP2350 A2, RP2350 A3, RP2350 A4 |
| Description | The CHAN_ABORT register commands a DMA channel to stop issuing transfers, and to clear its BUSY flag once in-flight transfers have completed. This was originally intended for recovering channels that are stuck with their DREQ low. An ABORT is initiated by writing a bitmap of aborted channels to CHAN_ABORT. Bits remain set until each channel comes to rest. This erratum is a compound of two behaviours: first, aborting a channel will cause its CHAIN_TO to fire, if and only if the aborted channel is the last channel to have completed a write transfer. Second, a channel undergoing an ABORT is susceptible to be re-triggered on the last cycle before the ABORT register clears, because the channel is both inactive and enabled on this cycle, and the ABORT itself doesn't inhibit triggering. However, since the ABORT is still in effect, the transfer count is held at zero. On the cycle after the ABORT finishes, the channel completes because its transfer counter is zero. This causes the channel's IRQ and CHAIN_TO to fire on the cycle after the ABORT completes. These two behaviours are problematic when aborting multiple channels that chain to one another, since they may cause the channels to immediately restart post-abort. |
| Workaround  | Before aborting an active channel, clear the EN bit (CH0_CTRL_TRIG.EN) of both the aborted channel and any channel it chains to. This ensures the channel isn't susceptible to re-triggering. |
| Fixed by | Documentation |

## RP2350-E8

| Reference | RP2350-E8 |
|---|---|
| Summary | CHAIN_TO might not fire for zero-length transfers |
| Affects | RP2350 A2, RP2350 A3, RP2350 A4 |
| Description | The CTRL.CHAIN_TO field configures a channel to start another channel once it completes its programmed sequence of transfers. The CHAIN_TO takes place on the cycle where the channel's last write completes, and the chainee becomes active on the next cycle. The hardware implementation assumes that CHAIN_TO always happens as a result of a write completion. This isn't the case when a channel is triggered with a transfer count of zero; in this case the channel completes on the cycle immediately after the trigger without performing any bus accesses. A CHAIN_TO from a channel started with a transfer count of zero will fire if and only if that channel is the last channel to have completed a write transfer. This is true only when the channel in question has previously performed a non-zero-length sequence of transfers, and no other channel has completed a write since. |
| Workaround  | Don't use CHAIN_TO in conjunction with zero-length transfers. Avoid zero-length transfers in the middle of control block lists, and replace them with dummy transfers if possible. |
| Fixed by | Documentation |

## GPIO

## RP2350-E9

| Reference | RP2350-E9 |
|---|---|
| Summary | Increased leakage current on Bank 0 GPIO when pad input is enabled |
| Affects | RP2350 A2 |

## Description

For GPIO pads 0 through 47:

Increased leakage current when Bank 0 GPIO pads are configured as inputs and the pad is somewhere between VIL and VIH (the undefined logic region).

When the pad is set as an input (input enable is enabled and output enable is disabled) and the voltage on the pad is within the undefined logic region, the leakage current exceeds the standard specified I IN leakage level. During this condition the pad can source current (the exact amount is dependent on the chip  itself  and  the  exact  pad  voltage,  but  typically  around  120 μ A).  This  leakage  will  hold  the  pad  at around 2.2 V as that is the effective  source  voltage  of  the  leakage,  and  can  only  be  overcome  with  a suitably low impedance driver / pull.

The pad pull-down (if enabled) is significantly weaker than the leakage current in this state and therefore isn't strong enough to pull the pad voltage low.

Driving  /  pulling  the  pad  input  low  with  a  low  impedance  source  of  8.2 k Ω or  less  will  overcome  the erroneous leakage and drive the voltage below the level where the leakage current occurs, so in this case if the pad is driven / pulled low it will stay low.

The  erroneous  leakage  only  occurs  (and  continues  to  occur)  when  the  pad  input  enable  is  enabled; disabling the input enable will reset (remove) the leakage.

The pad pull-up still works. If enabled it will pull the pad to IOVDD as it will pull the input voltage out of the problematic range.

The  voltages  and  currents  above  are  based  on IOVDD at  3.3 V.  For IOVDD at  1.8 V  the  effective  source voltage of the leakage becomes 1.8 V and the peak current is around 30 μ A. This is effectively a pull-up (separate to the standard pad pull-up) when the pad voltage is between 0.6 V and 1.8 V.

These  graphs  show  the  leakage  current  versus  pad  input  voltage  for  a  typical  chip  for IOVDD at  3.3 V Figure 153 and 1.8 V Figure 154.

In detail, this issue presents under the following conditions, for any GPIO 0 through 47:

1. The voltage on the pad is in the undefined logic region.
2. Input buffer is enabled in GPIO0.IE
3. Output buffer is disabled (e.g. selecting the NULL GPIO function)
4. Isolation is clear in GPIO0.ISO, or the previous were true at the point isolation was set

When all of the above conditions are met, the input leakage of the pad may exceed the specification.

This issue may affect a number of common circuits:

- Relying on floating pins to have a low leakage current
- Relying on the internal pull-down resistor

If  the  internal  pull-up  is  enabled  then  any  floating  signal  will  be  pulled  high  thus  removing  increased leakage  condition  as  the  excess  leakage  is  only  sourcing  current.  This  of  course  can't  prevent  the increased leakage if the pad is fed via a strong source e.g. strong potential divider.

This  doesn't  affect  the  pull-down  behaviour  of  the  pads  immediately  following  a  PoR  or  RUN  reset because the input enable field is initially clear. The pull-down resistor functions normally in this state.

This issue doesn't affe

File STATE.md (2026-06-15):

# NeoPico-HD — Live State

**Contract:** this document is LIVE — edited in place to always reflect current
reality. Any agent or human picking up the project starts here. The
append-only history stays in `SCRATCHBOOK.md`; architecture rules in
`AGENTS.md`; protocol details in `docs/`.

_Last updated: 2026-06-12 (late evening; 720p precomposed genlock — signal
measurably perfect, picky-sink suspected, second-TV test is the gate)._

---

## TL;DR — where we are right now

- **S1 (480p precomposed-on-RT) is VALIDATED** (run #9, ~1 h clean). The
  runtime-modes RT library running the *precomposed tiny ISR* is the
  architecture of record. The copy-model ISR is on death row.
- **S3 (720p precomposed) is implemented and mostly working.** Picture is
  correct (pillarboxed 4:3, 3x scale), audio works, RS=0 (no HDMI desync
  ever), FIFO never underflows, ISR never runs late. Four real defects were
  found and fixed today (see ledger). A **dynamic genlock** (locks output to
  the MVS ~59.186 Hz via vtotal + sub-line elastic-blanking trim) was built
  from scratch.
- **One symptom remains:** once the genlock LOCKS, the sink shows a
  whole-frame jolt (OSD + game jump together) every ~8–20 s. **Every on-chip
  signal we can measure is constant through these jolts** (FIFO level, ISR
  gap, vtotal, trim, audio-underrun count). The unlocked/drifting state is
  always clean.
- **Prime remaining suspect: the TV.** Locked output is non-CEA 720p (762
  lines, 59.186 Hz, ~1.4% off standard). Same TV ran 480p (standard 525-line)
  clean for an hour. **THE NEXT ACTION IS A ONE-CABLE TEST ON A SECOND
  DISPLAY** — no code. It splits the world: second sink clean → ship as a
  per-sink quirk; second sink also jolts → it's on the wire in a dimension we
  haven't instrumented yet.

**Live build (uncommitted, on the bench):** `build-720p-s3/`. Boots with the
OSD open on a new **Genlock** telemetry screen. All work is in the working
tree of BOTH repos — nothing committed yet (see "Uncommitted code" below).

---

## Current bench build: `build-720p-s3/`

Flags: `NEOPICO_VIDEO_720P=ON NEOPICO_EXP_PRECOMPOSED_HDMI=ON
NEOPICO_EXP_GENLOCK_DYNAMIC=ON NEOPICO_ENABLE_OSD=ON NEOPICO_ENABLE_SELFTEST=ON
NEOPICO_OSD_ROOT_MENU=ON NEOPICO_COPY_TO_RAM=ON NEOPICO_VIDEO_DVI_ONLY=OFF`
(`PICO_HDMI_RUNTIME_MODES=ON` — this is the **RT** path).

Flash: `pi flash build-720p-s3/src/neopico_hd.uf2` (auto reboot-to-bootloader;
the board occasionally drops off USB and needs a cable reseat / BOOT-reset —
this happened ~3x today, not a firmware issue).

### Genlock OSD screen (boots open; also root-menu entry "Genlock")
Row layout (what to read on the bench):
- `PHASE` — µs between MVS vsync and HDMI vsync. Setpoint target = 11000.
  Healthy: parks near 11000 and wanders slowly within the deadband.
- `TRIM` — applied elastic-blanking trim in pixel-clocks (negative = shorter
  blanking = faster output). Equilibrium ≈ −5…−7 (was −17…−20 before the
  uniform-trim fix). Constant for minutes at a time.
- `SLOTS` — # of blanking-line RAW_REPEAT words being trimmed. Should be 10
  (7 clean templates + 3 DI templates). If 0, the servo is a no-op.
- `VTOTAL` — parked at 762 in steady state. 761/763 only flicker during
  acquire.
- `UPTIME` — seconds since boot (doubles as a glitch stopwatch).
- bottom probe row `F.. G.. U.....`:
  - `F` = min HSTX FIFO level seen in last 1 s (≈7, never dips at glitch).
  - `G` = max inter-IRQ gap µs in last 1 s (≈23, never spikes at glitch).
  - `U` = cumulative audio silence-packet insertions (climbs fast at boot to
    ~24000 then frozen; no glitch correlation).

---

## 720p GENLOCK SAGA — investigation ledger (2026-06-12)

Goal: lock the 720p output frame rate to the MVS (~59.186 Hz) so the
free-run beat doesn't cause periodic gray frames, AND do it without
disturbing the sink. The MVS is the timing master; we slave HDMI to it.

**Defects found & fixed, in order (each had a distinct on-screen fingerprint):**

1. **Free-run beat → full gray frame ~1/s** (run #10). Output free-ran 60.00
   Hz vs MVS 59.185; once per ~1.3 s beat the HDMI vsync sampled a capture
   frame-base with zero lines committed → whole frame prepped as no-signal
   gray. *Fix:* dynamic genlock (slave output rate to MVS).

2. **Top-of-image disruption (3-4x band duplication)** — ring lapping. The
   16-line pre-expanded ring holds ~1.07 ms of beam; the Core 1 background
   task legitimately stalls 100s of ms (audio SRC bursts), so prep fell
   behind and the beam wrapped onto stale entries. *Fix:* moved prep off the
   background task onto a **hardware alarm IRQ on Core 1** (250 µs tick,
   bounded ~6 lines/tick, preempts audio bursts; scanline DMA ISR still
   preempts it). `video_pipeline_p720_alarm_cb`.

3. **Frame-restart race** — vsync ISR reset the prep cursor while the alarm
   IRQ was mid-prep; the post-increment landed after the reset → line 0
   skipped → stale top slots. *Fix:* vsync only bumps `p720_frame_seq`; the
   alarm context is the SOLE owner of the prep cursors and detects the new
   frame itself (single writer).

4. **Top garbage under stretched vtotal — LATENT RT LIBRARY BUG.**
   `get_scanline_state()` classified active video as
   `!vsync && !front_porch && !back_porch`, but `active_line` was computed as
   `v_scanline - (v_total - v_active)`. When genlock stretches `v_total`, the
   extra lines between back porch and active got classified active with a
   huge/negative `active_line` → garbage scanout at the top. *Fix:* active
   video is now PINNED right after the back porch
   (`blank_head = v_fp + v_sync + v_bp`), so vsync-to-active distance never
   depends on v_total and stretched lines land at the frame BOTTOM (invisible
   blanking). **This bug affected every dynamic-genlock experiment ever run on
   this lib, including 480p/532-line.** Fixed in lib + mirrored to 2.1-dev.

5. **Gradual gray fills screen every ~4 s — wrong nominal.** 760-line nominal
   was computed for the CEA 74.25 MHz pixel clock, but the hardware runs
   **372 MHz / 5 = 74.4 MHz** (NOT 74.25). At 74.4 MHz, 760 lines = 59.33 Hz
   (too fast) so the phase wrapped. *Fix:* `GENLOCK_NOMINAL_VTOTAL_720 = 762`
   (74.4M / (1650·762) = 59.187 Hz, +2 µs/frame vs MVS — near-perfect),
   plus a fast-acquire state.

6. **Glitch cycle (6 s / 66 s, then 8 s / 23 s) with horizontal kicks — the
   genlock CONTROLLER itself.** This was the long fight. Progression:
   - vtotal bang-bang (762↔761) dithered the frame period a whole line
     (~22 µs) every few frames → sink V-PLL hunts. **Finding: this sink
     visibly reacts to vtotal steps.**
   - → **Elastic blanking (sub-line trim):** keep vtotal CONSTANT, trim a few
     pixels off the big RAW_REPEAT in blanking lines (~0.5 µs/frame per pixel,
     44x finer than a line, below sink line-PLL perception). NEW 2.1 LIBRARY
     FEATURE: `video_output_set_vblank_htrim_px()`. This is the genlock's
     fine actuator.
   - servo sign bug (positive feedback), then limit-cycling (trim/drift/phase
     is a double integration), then a deadlock in the outlier rejection
     (stale reference rejected every real sample → trim pinned at clamp).
     Each fixed in turn: outlier reject w/ streak-accept, slew limit
     1 px/frame, then a **slow integrator** (hold trim constant; step ±1 px
     only past a ±400 µs deadband, rate-limited), then **derivative gating**
     (only step when phase is not already returning — anti-windup + damping).
   - **Bench finding that reframed everything:** trim sitting at the −30 clamp
     (CONSTANT) → clean; trim at the servo equilibrium hunting ±1 px → glitch.
     The sink reacts to trim ACTIVITY, not value.

7. **Intra-vblank sawtooth — uniform trim fix.** We were trimming only ~7 of
   the ~42 blanking lines (DI-carrying templates were excluded out of
   caution). That imposed a line-to-line H-period sawtooth (1650 vs 1650+trim)
   inside every vblank, which the sink tracked once |trim| > ~14 px (matches
   "glitches start around −14"). *Fix:* register the DI vblank templates too
   (`vblank_di_ping/pong/null`). False positives impossible: TERC4 payload
   words always carry high bits, can't match a bare RAW_REPEAT in the
   1200–1600 px window. Tripled authority → equilibrium trim −17 → ~−5.

**After all 7 fixes: the residual jolt.** Locked = jolt every ~8–20 s,
unlocked = clean, AT ANY SETPOINT (tested 8000 and 11000). Discriminators run:
- OSD-jumps-with-picture test → **whole output frame**, not a capture slip.
- FIFO min `F` + ISR-gap `G` probe → **constant through jolts** (output
  delivery provably perfect; no underflow, no late ISR).
- vtotal-spike debounce + raw-excursion counter `A` → `A` stuck at boot value
  → **no measurement-spike-induced vtotal steps**.
- audio silence-insert counter `U` → climbs at boot then frozen, **no glitch
  correlation** → audio queue exonerated.
- DVI-only discriminator → **INVALID / no signal**: precomposed templates
  carry HDMI guard-band/preamble structure, can't be served as clean DVI.
  (Lib gap to note for 2.1; do not retry as-is.)

**Conclusion / current hypothesis:** every on-chip signal dimension is
measurably CONSTANT while the sink jolts. The one thing unique to the locked
state is a frozen, non-CEA timing (762 lines, 59.186 Hz, ~1.4% off standard).
Leading theory: **the TV's format-detection / re-sync heuristic twitches on a
near-but-not-standard timing it can't fully settle on.** Supporting: this same
TV ran standard-timing 480p (525 lines) clean for an hour.

### >>> NEXT ACTION (no code): test a SECOND display <<<
One cable swap. `build-720p-s3` as-is.
- Second sink clean at lock → genlock is correct; this TV dislikes near-CEA
  timing. Treat as per-sink quirk (consider a future "standard-timing +
  accept-the-beat" fallback mode, or true CEA 74.25 via a different
  sysclk/divider).
- Second sink jolts identically → it IS on the wire; instrument the last
  un-probed dimensions (data-island TERC4 content / IEC channel-status
  cadence / infoframe checksum timing under lock).

---

## Uncommitted code (BOTH repos dirty — nothing committed for the 720p work)

**`~/Projects/neogeo/neopico-hd`** (working tree):
- `src/video/video_pipeline.c` — 720p precomposed path (`p720_*` ring, alarm
  IRQ prep, retry pass) + the entire genlock servo (`genlock_dynamic_update`,
  elastic-trim integrator with deadband + derivative gating + slew limit +
  vtotal-spike debounce). Constants: `GENLOCK_NOMINAL_VTOTAL_720=762`,
  `GENLOCK_PHASE_SETPOINT_US=11000` (was 8000; an EXPERIMENT value — revisit),
  `PULLBACK=14000`, `RESUME=4000`, `P720_PREP_INTERVAL_US=250`,
  `P720_RING_LINES=16`. Publishes `g_genlock_phase_us`,
  `g_genlock_outzone_count`.
- `src/experiments/menu_diag_experiment.c` — new `MENU_SCREEN_GENLOCK` +
  "Genlock" root entry; boots OSD open on it; 1 Hz value updates; probe row.
- `src/osd/selftest_layout.c` — reverted the temporary debug line (clean).
- `src/main.c`, `src/video/video_pipeline.h` — `video_pipeline_precomp_background`
  hook + 720p decls.
- `src/CMakeLists.txt` — precomposed 720p restriction relaxed (240p still
  FATAL_ERROR: "S3b pre-doubled ring not done").
- `src/video/scale_pixels.S` (NEW) + `NEOPICO_TRIPLE_ASM` flag (default OFF) —
  hand-written M33 kernels for the 3x/4x pixel-scale (the alarm-IRQ hot path):
  STM-batched stores + post-inc loads, ~1.8-2x vs C, in `.scratch_y` (RAM).
  Boot `video_pipeline_scale_selftest()` compares asm vs C refs over several
  counts (incl. odd/zero); verdict in `g_scale_asm_selftest_ok`, shown on the
  Genlock OSD as `ASM:OK`/`ASM:BAD`. Host-simulated register-faithful (ALL
  MATCH) + disassembly-verified; NOT yet run on device. `build-720p-s3/` is
  currently configured with `NEOPICO_TRIPLE_ASM=ON` (built, not flashed).
  NOTE: this is a prep-MARGIN win, NOT a fix for the locked-state jolt (that's
  still the second-TV question). Flag-OFF is empty-object equivalent by
  construction (`#if NEOPICO_TRIPLE_ASM` guards the whole .S; C bodies under
  `#if !NEOPICO_TRIPLE_ASM`).
- `lib/pico_hdmi` (submodule pointer M; the nested checkout is itself dirty).

**`~/Projects/pico_hdmi`** (branch `2.1-dev`, `src/video_output_rt.c` dirty):
- Elastic blanking: `video_output_set_vblank_htrim_px()` +
  `_get_vblank_htrim_slots/px()` + `htrim_register_all()` (hooked after
  `compose_ring_built`). **2.1 feature.**
- Active-video pinned after back porch (defect #4 fix). **2.1 fix.**
- Perf probe: `video_output_perf_probe_read()` (FIFO min + IRQ gap).
- NOTE: the neopico nested `lib/pico_hdmi` copy and the standalone
  `~/Projects/pico_hdmi` 2.1-dev tree must be kept in sync by hand; the
  active-line fix is mirrored, but verify the htrim + probe code matches
  before committing/pushing 2.1-dev.

**Commit plan when the second-TV verdict is in:** (1) commit lib 2.1-dev
(elastic blanking + active-pin fix + probe) and push branch; (2) commit
neopico 720p path + genlock + Genlock OSD screen behind the existing flags
(verify flag-OFF UF2 unchanged); (3) bump submodule pointer.

---

## Resolved foundation (earlier today — context for the above)

- **Precomposed-on-RT (S1) works.** The exact RT+features path that dropped
  sync in seconds as the *copy-model* ISR is rock-solid as the *precomposed
  tiny ISR* (run #9). RS=0 all day across every 720p experiment confirms the
  RT machinery itself never faulted.
- **XIP layout sensitivity → SOLVED:** `NEOPICO_COPY_TO_RAM=ON`
  (pico_set_binary_type) eliminates runtime XIP; this is why dead code used to
  perturb sync. The precomposed tiny-ISR is the only ISR light enough to also
  survive copy_to_ram (the heavyweight copy-model RT ISR + striped-SRAM fetch
  contention was TOXIC — dropped in seconds).
- **`__scratch_x("")` merges ALL functions into one section** → the linker
  can never GC dead scratch code individually; #if-gate unused scratch
  functions out (did this for the copy-model dispatcher; scratch_x 0x800→0x5c0).
- Canonical 480p baseline: run #6, sha `76c1233d`,
  `build-precomp-baseline/`. RT×copy_to_ram TOXIC policy stands. Scenario B
  (precomposed → runtime-modes path = pico_hdmi 2.1) ratified and in progress.

## Remaining 2.1 stages (DESIGN-2.1.md)
- **S2** — swap-free DMA topology (eliminate the per-IRQ 16/32-bit `al1_ctrl`
  swap). NOTE: 720p uses 32-bit pointer mode and never touches the swap, so
  the S2 hazard is ABSENT at 720p; it's a 480p/native-mode concern.
- **S3b** — 240p (4x = pre-doubled ring + hardware 2x). 720p (3x) done.
- **S4** — runtime mode switching + wire the Resolution menu entry onto the
  precomposed path (currently reboot-based).

## Run log (one line per soak)

| # | Date | Firmware (sha + flags) | Outcome |
|---|---|---|---|
| 1 | 06-11 | v0.6.0 release | clean >1 h |
| 2 | 06-11 | 981efab+3d1cb91, flags OFF | clean ~1 h |
| 3-5,7 | 06-11/12 | precomp+OSD+selftest, flash/XIP | sync drops (XIP, since fixed) |
| 6 | 06-12 | pure phase-2 baseline 76c1233d | CLEAN ~8 h overnight |
| 8 | 06-12 | oracle: glitch-patch + COPY_TO_RAM | CLEAN — XIP convicted |
| 9 | 06-12 | **S1** RT+precomp+OSD+menu+copy_to_ram (`build-s1/`) | **CLEAN ~1 h — S1 validated** |
| 10 | 06-12 | S3-720p first cut | gray flash ~1/s; RS=0 (free-run beat) |
| 11-20 | 06-12 | S3-720p + genlock iterations (`build-720p-s3/`) | 7 defects found & fixed; see ledger |
| 21 | 06-12 | S3-720p genlock final (setpoint 11000, uniform trim, probes) | locked picture clean EXCEPT whole-frame jolt ~8-20 s; all on-chip signals constant → **second-TV test pending** |

## Standing constraints (digest; full rules in AGENTS.md + SCRATCHBOOK)
- scratch_x hard boundary 0x800; measure before adding anything to scratch
  (`grep -A1 '^\.scratch_x' src/neopico_hd.elf.map`). Live build: ~0x6b0.
- `__scratch_x("")` functions can't be GC'd individually — #if-gate dead ones.
- No printf/blocking I/O on Core 1 background path (1 UART line = 7 ms stall).
- OSD render pattern: full draw on entry, value-only ~1 Hz updates.
- Flag-gate everything experimental, default OFF; verify flag-OFF UF2 byte-identical.
- Validate audio with a pure sine + spectrogram (SFX/square waves mask drops).
- The neopico `lib/pico_hdmi` checkout is intentionally a separate dirty tree;
  keep it in sync with `~/Projects/pico_hdmi` 2.1-dev by hand.

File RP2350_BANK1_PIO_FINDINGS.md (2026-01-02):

# RP2350 Bank 1 & PIO Capture: Technical Findings

This document summarizes the technical investigation into video capturing using Bank 1 GPIOs (GP32-47) on the RP2350 B revision.

## 1. Hardware Architecture (Bank 1)

- **GPIO Layout:** RP2350 has 48 GPIOs. Bank 0 (0-31) and Bank 1 (32-47).
- **The GPIOBASE Register:** PIO instances on RP2350 (PIO0 and PIO1) have a new register at offset `0x168`. This register defines the base of a 32-pin window accessible to the PIO.
- **PIO2 Limitation:** PIO2 is a "reduced" instance and **lacks the GPIOBASE register**. It is permanently fixed to Bank 0 (0-31). Video capture must use PIO0 or PIO1.

## 2. PIO Instruction Limitations

- **5-Bit Fields:** The `WAIT GPIO <n>` and `JMP PIN <n>` instructions use a 5-bit field for the pin number. This allows addressing only 32 pins (0-31).
- **Relative Addressing:** On RP2350, these 5 bits are **relative to GPIOBASE**.
  - If `GPIOBASE = 16`, then `WAIT GPIO 0` actually waits for **GP16**.
  - To wait for **GP46**, the instruction needs index `30` (46 - 16).

## 3. SDK "Help" Trap

One of the most unexpected findings was the behavior of `pio_add_program()`:

- **Automatic Instruction Modification:** When `PICO_PIO_USE_GPIO_BASE` is defined, the SDK's program loader **automatically XORs the 5th bit** of `WAIT GPIO` instructions based on the current `GPIOBASE`.
- **Conflict:** if you manually calculate the relative index in your `.pio` file (e.g., using 13 for GP29), and the SDK "helps" you by XORing it again, the PIO ends up looking at the wrong pin entirely.
- **Absolute vs Relative:** The SDK expects you to use **absolute** GPIO numbers in the `.pio` file, and it will attempt to remap them at runtime. However, this remapping is inconsistent across different SDK versions and depends on the `pinhi` field in the `pio_sm_config` struct.

## 4. Struct Layout Mismatch

- **`pio_sm_config` Size:** On RP2350, the `pio_sm_config` struct has an additional 32-bit field `pinhi`.
- **Memory Corruption:** If the application is compiled with different flags than the SDK library, the offsets for `pinctrl`, `execctrl`, and `shiftctrl` will be misaligned, leading to silent failures or crashes when calling `pio_sm_init`.
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

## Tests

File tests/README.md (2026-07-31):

# Host tests

## Exhaustive MVS color characterization

Run:

```sh
bash tests/run_mvs_color_exhaustive.sh
```

The test compiles with the host C compiler and writes its temporary binary
outside the repository. It does not build firmware or access Pico hardware.

It executes all 32,768 captured RGB555 values in all four DARK/SHADOW flag
combinations. Structural conversion errors fail the test. Known color-accuracy
differences are printed as characterization results so they can be corrected
and converted into strict expectations one change at a time.

The same run exhaustively checks both normal-color menu choices. `Digital`
must match the stable RGB555-to-RGB565 LUT for every source color. `Analog`
must match the independent normal-state DAC reference for every source color.
The normal-color API has no DARK/SHADOW input.

It also checks the default-off Digital register-processing backend against the
independent Digital reference for every color and effect state. Raw-word tests
repeat all cases with every CSYNC/PCLK bit combination to ensure captured bits
1:0 cannot leak into the RGB555 fields.

The runner also checks the live menu source contract: moving the selection
requests a preview, SELECT requests the committed model, START queues
persistence, both 64 KiB LUTs exist, and the Colors case contains no
save-and-reboot call.

The runner builds the production split-table code twice, once for each
compile-time model. Independent, test-only reference models are pinned to the
MiSTer Neo Geo implementation and MAME's Neo Geo resistor-network model. Every
production channel entry, split-table result, and synthesized raw capture word
must match its selected independent reference. MAME's resistor values are a
model, not a substitute for measurements from the target MV1C board under the
intended load.

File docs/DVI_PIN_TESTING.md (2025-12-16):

# DVI Pin Configuration for RP2350

## Working Configuration

```
CLK:  GP31-32 (CLKN/CLKP)
D0:   GP25-26 (D0N/D0P)
D1:   GP27-28 (D1N/D1P)
D2:   GP29-30 (D2N/D2P)
```

## Key Findings

### 1. PIO GPIO Window Limitation
RP2350 PIO can only access a 32-pin window at a time. Default is GPIO 0-31.

**Fix for GP32+:** Call `pio_set_gpio_base(pio0, 16)` before `dvi_init()` to shift window to GPIO 16-47.

### 2. PWM Clock Pin Requirement
PWM clock requires both pins on the same PWM slice (even-numbered base pin).

**Fix for odd clock pins:** Add `DVI_USE_PIO_CLOCK=1` compile definition to use PIO-based clock instead.

## Implementation

See `src/neopico_config.h` for the shared configuration:
- `neopico_dvi_cfg` - DVI serializer pin mapping
- `neopico_dvi_gpio_setup()` - Call before `dvi_init()`

All DVI targets in CMakeLists.txt include `DVI_USE_PIO_CLOCK=1`.

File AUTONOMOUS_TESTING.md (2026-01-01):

# Autonomous Testing Procedures

## Serial Monitor - CRITICAL

**NEVER use `cat` or `screen` for serial monitoring** - they are IO-blocking and will cause the agent to hang indefinitely if the device doesn't respond.

### Correct Method: Python with Timeout

```python
import serial
import time
import sys

def monitor_serial(port, baudrate=115200, duration=20):
    """
    Non-blocking serial monitor with timeout.
    Returns immediately if port doesn't exist or after duration expires.
    """
    try:
        ser = serial.Serial(port, baudrate, timeout=0.1)
        start_time = time.time()

        while time.time() - start_time < duration:
            if ser.in_waiting:
                data = ser.read(ser.in_waiting)
                print(data.decode('utf-8', errors='replace'), end='')
                sys.stdout.flush()
            time.sleep(0.05)

        ser.close()
        return True
    except Exception as e:
        print(f"Serial error: {e}", file=sys.stderr)
        return False

# Usage
port = '/dev/tty.usbmodem*'  # Find actual port first
monitor_serial(port, duration=20)
```

## Testing Workflow

1. **Build**: `cd build && make <target>`
2. **Flash**: `picotool load -f ./src/<target>.uf2`
3. **Find Port**: `ls -t /dev/tty.usbmodem* | head -1`
4. **Monitor**: Python script with timeout (NEVER cat/screen)
5. **Analyze**: Parse output, make decisions
6. **Fix**: Update code if needed
7. **Repeat**: Loop until success or blocked

## When to Report to User

- ✅ Definitive results (success or identified root cause)
- ✅ Blocked by major decision (multiple valid approaches)
- ✅ Hardware not responding (device stuck/not found)
- ❌ NOT for status updates or intermediate steps

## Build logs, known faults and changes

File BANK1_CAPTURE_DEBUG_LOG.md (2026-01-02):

# Bank 1 Video Capture Debugging Log

**Date:** 2026-01-01
**Status:** Colors correct, pixels scrambled horizontally

---

## Session Summary

Successfully captured video from MVS using RP2350 Bank 1 GPIOs (GP31-46), but pixels are horizontally scrambled within each line.

---

## Key Findings

### ✅ **SOLVED: Color Mapping**

**Issue:** Background was red-brownish instead of black
**Root Cause:** Incorrect pin mapping - R4 was mapped to GP46 (CSYNC pin) instead of GP45
**Fix:** Updated `pins.h` and `hardware_config.h`:

```c
// BEFORE (WRONG):
#define PIN_MVS_R4 46  // This is CSYNC!
r |= ((gpio_data >> 15) & 1) << 4;  // GP46 → R4 (WRONG)

// AFTER (CORRECT):
#define PIN_MVS_R4 45  // Correct R4 pin
r |= ((gpio_data >> 14) & 1) << 4;  // GP45 → R4 (CORRECT)
```

**Result:** Colors now perfect - black background, white grid, correct blue borders

---

### ✅ **WORKING: Bank 1 GPIO Access**

- **GPIOBASE=16** correctly set for PIO1 (offset 0x168)
- **gpio_get()** works on Bank 1:
  - GP29 (6MHz PCLK): 317k toggles/100ms = 26% capture efficiency ✓
  - GP46 (15.7kHz CSYNC): 3.2k toggles/100ms = 103% efficiency ✓
- **PIO** successfully reads GP31-46 and produces data
- **FIFO** has data, PC advancing

---

### ✅ **WORKING: Bit Remapping**

**GPIO → RGB555 mapping verified correct:**

- All 16 GPIOs (GP31-46) map correctly to RGB bits
- Remapping function `remap_gpio_to_rgb555()` produces correct colors
- RGB555 → RGB565 conversion works

---

### ✅ **SOLVED: Horizontal Pixel Scrambling**

**Issue:** Diagonal streaks and inconsistent horizontal alignment.
**Root Cause:** `WAIT GPIO <n>` instructions in PIO are relative to `GPIOBASE`.

- `WAIT 1 GPIO 43` (CSYNC) was being interpreted as index 11 (43-32=11).
- In the `GPIOBASE=16` window, index 11 is **GP27 (Red 1)**.
- The PIO was syncing to the Red data toggles instead of CSYNC.
  **Fix:**

1. Switched to `WAIT PIN <n>` in PIO, which is relative to the `IN_BASE` register.
2. Manually configured `IN_BASE` and `JMP_PIN` via direct register writes to point to Bank 1 indices (e.g., 27 for GP43).
   **Result:** Rock-solid horizontal alignment.

---

### ✅ **SOLVED: "Only Blue" Channel / Missing Colors**

**Issue:** Only blue bits were visible; red/green were black.
**Root Cause:** Mismatch between PIO `shift_right` and bit extraction logic.

- `shift_right = true` + `autopush = 18` placed the 18-bit pixel at `word[31:14]`.
- Extraction logic expected data at `word[17:0]`.
- Only the "Blue" channel (bits 11-15) saw any data (specifically bit 14/15).
  **Fix:** Set `shift_right = false` (Shift Left) in Pixel SM configuration.
  **Result:** All colors now perfectly captured and correctly mapped.

---

## Final Hardware Configuration

### Pin Mapping (Verified Correct)

```
Bank 0:
  GP29: PCLK (6 MHz)

Bank 1 (GP31-46):
  Red:   R0=GP42, R1=GP41, R2=GP44, R3=GP43, R4=GP45
  Green: G0=GP36, G1=GP33, G2=GP34, G3=GP31, G4=GP32
  Blue:  B0=GP35, B1=GP38, B2=GP37, B3=GP40, B4=GP39
  CSYNC: GP46
```

### PIO Configuration

```c
PIO1 (video capture):
  GPIOBASE: 16 (window GP16-47)
  Sync SM: IN_BASE=30 (GP46), JMP_PIN=30
  Pixel SM: IN_BASE=15 (GP31)
  Shift: right, autopush at 32 bits
```

### Timing Constants

```c
H_SKIP_START: 30 pixels (was 28, adjusted)
H_SKIP_END: 34 pixels (was 36, adjusted)
NEO_H_TOTAL: 384 pixels
Active capture: 320 pixels (160 words)
```

---

## Diagnostic Tools Created

1. **gpio_activity_map** - Hardware-in-loop electrical verification
2. **bank1_gpio_speed_test** - GPIO read performance testing
3. **pio_pc_tracker** - PIO state machine execution monitor
4. **USB viewer** - Live frame display over serial (viewer/run.sh)

---

## Next Steps

1. **Analyze scrambling pattern** - Use USB viewer to identify pixel ordering
2. **Check autopush timing** - Verify 32-bit word assembly
3. **Test different IN shift modes** - Try different PIO configurations
4. **Add horizontal sync per line** - Re-sync to CSYNC each line (not just per frame)
5. **Verify DMA/memory writes** - Check if framebuffer writes are sequential

---

## Reference Documentation

- `RP2350_BANK1_PIO_FINDINGS.md` - Technical findings on Bank 1/PIO
- `AUTONOMOUS_TESTING.md` - Testing procedures for autonomous operation
- Pin definitions: `src/pins.h`
- Bit remapping: `src/video/hardware_config.h`

---

## Code Changes Made

### Files Modified:

- `src/pins.h` - Fixed R4 pin (GP46→GP45)
- `src/video/hardware_config.h` - Updated bit remapping for R4
- `src/video/video_capture.c` - Added diagnostics, adjusted H_SKIP
- `src/video/video_capture.pio` - Removed initial PCLK sync (reverted)
- `src/main.c` - Added USB frame output for viewer
- `src/CMakeLists.txt` - Added diagnostic tool targets
- `viewer/run.sh` - Created viewer launch script (NEW)

### Files Created:

- `src/misc/gpio_activity_map.c`
- `src/misc/bank1_gpio_speed_test.c`
- `src/misc/pio_pc_tracker.c`
- `AUTONOMOUS_TESTING.md`
- `BANK1_CAPTURE_DEBUG_LOG.md` (this file)

---

_Last updated: 2026-01-01_
_Autonomous debugging session by Claude Code_

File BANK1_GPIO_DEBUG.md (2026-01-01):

# Bank 1 GPIO Debug Log - NeoPico-HD

**Date**: 2025-12-31
**Issue**: Video capture not working - black screen on HDMI and Python viewer

---

## Problem Statement

NeoPico-HD video capture showing no video output. Both HDMI and Python viewer (USB serial) show black/no frames.

---

## Root Cause: RP2350 PIO Bank 1 GPIO Limitation

**Technical Issue**: PIO instructions have 5-bit address fields
- `wait gpio N` - can only address N = 0-31 (5-bit field)
- `jmp pin N` - same 5-bit limitation
- **Bank 1 GPIOs (32-47) cannot be addressed directly!**

---

## Pin Configuration (Hardware Verified)

| Pin | Function | Bank | Status |
|-----|---|---|---|
| GP29 | PCLK (Pixel Clock) | Bank 0 | ✅ 6 MHz detected |
| GP46 | CSYNC (Composite Sync) | Bank 1 | ✅ ~16 kHz detected (via GPIO) |
| GP31-46 | RGB555 Data (scrambled) | Bank 1 | ⚠️ PIO cannot access |

**Verification Methods**:
- Oscilloscope: 6 MHz on GP29 ✓
- Direct GPIO read: GP46 toggles 10-20 times per 100ms ✓
- PIO test on GP29: 5.99 MHz detected ✓
- PIO test on GP46: **FAILED with wait gpio** ❌

---

## Attempted Solutions

### 1. Manual gpio_base Configuration (FAILED)
```c
pio->ctrl = (pio->ctrl & ~(0x1F << PIO_GPIOBASE_LSB)) | (32 << PIO_GPIOBASE_LSB);
```
- Set PIO CTRL.GPIOBASE to 32 (Bank 1 offset)
- **Result**: Still failed - gpio_base doesn't affect instruction encoding

### 2. JMP PIN Polling Workaround (FAILED)
```pio
wait_high:
    jmp pin found_high      ; Jump if pin high
    jmp wait_high           ; Loop
found_high:
```
- **Problem**: `jmp pin` also has 5-bit limitation!
- `sm_config_set_jmp_pin()` uses 5-bit EXECCTRL register field

### 3. SDK Function + WAIT PIN (TEST SUCCESS, MAIN CODE FAILED)

**Test Firmware** (`src/misc/bank1_test.c`):
```c
// Used SDK 2.1.1+ function for Bank 1 GPIO support
pio_claim_free_sm_and_add_program_for_gpio_range(
    &pio_edge_program, &pio, &sm, &offset,
    TEST_PIN, 1, true  // gpio_base=46, count=1, set_gpio_base=true
);

// PIO program
wait 0 pin, 0  // Wait for low
wait 1 pin, 0  // Wait for high (edge)
jmp x--, 0     // Count
```

**Result**: ✅ **SUCCESS!**
- Edges counted: **16,154 Hz** on GP46
- PIO selected: **PIO2** SM0
- gpio_base reported: **0** (not 32 as expected!)
- IN_BASE set to: **46** (pin_offset = TEST_PIN - gpio_base)

**Main Firmware** (`src/video/video_capture.c`):
- Applied same SDK function
- Simplified sync program to identical `wait pin` logic
- **Result**: ❌ **FAILED** - continuous timeouts
- Debug output: "Frame capture timeout" repeating
- Diagnosis: `wait_for_vsync()` never detects edges

---

## UPDATE: Boot Messages Investigation (2025-12-31 22:42)

**Finding**: Boot messages are NOT missing - they're printed before USB CDC enumerates!
- Main firmware runs successfully through all initialization
- Timeout messages appear (count 90+) proving stdio works
- Boot printfs happen during 2-second stdio_init delay before USB ready
- **Conclusion**: Firmware initializes correctly, but video capture fails in `wait_for_vsync()`

**USB Enumeration**: After flashing with picotool, explicit `picotool reboot` required for USB CDC to appear.

---

## UPDATE: Deep Dive Investigation (2025-12-31 23:00)

### Critical Findings

**✅ SDK Function Works Correctly**:
- `pio_claim_free_sm_and_add_program_for_gpio_range()` successfully claims PIO2 SM0
- `gpio_base = 0` (same as working test firmware)
- `pin_offset = PIN_CSYNC - gpio_base = 46 - 0 = 46`
- IN_BASE correctly set to 46

**✅ PIO Configuration Verified**:
```
PIO: PIO2 SM0
gpio_base: 0
pin_offset: 46
SM enabled: Yes
```

**❌ FIFO Always Empty**:
- 782,000+ empty checks per 100ms timeout
- Zero data ever pushed to FIFO
- `wait pin` instructions never trigger

### Debugging Steps Taken

1. **PIO Conflict Eliminated**:
   - Changed audio pipeline from PIO2 to PIO1 (then disabled entirely)
   - Disabled pixel capture program - sync runs alone
   - Still fails

2. **Exact Test Replication**:
   - Copied exact 3-instruction edge counter from working bank1_test
   - Matched GPIO initialization sequence exactly
   - Used same SDK function call
   - Used same pin_offset calculation
   - Still fails

3. **PIO Program Evolution**:
   ```pio
   ; Final simplified version (still fails)
   wait 0 pin, 0      ; Wait for CSYNC low
   wait 1 pin, 0      ; Wait for CSYNC high
   push noblock       ; Push edge to FIFO
   jmp entry_point    ; Loop
   ```

4. **Initialization Sequence**:
   ```c
   // Matches test exactly
   gpio_init(PIN_CSYNC);
   gpio_set_dir(PIN_CSYNC, GPIO_IN);
   gpio_pull_down(PIN_CSYNC);
   pio_gpio_init(g_pio_mvs, PIN_CSYNC);

   sm_config_set_in_pins(&c, pin_offset);  // 46
   pio_sm_init(g_pio_mvs, g_sm_sync, offset_sync, &c);
   pio_sm_set_enabled(g_pio_mvs, g_sm_sync, true);
   ```

### Hypotheses Remaining

1. **Hardware State**: MVS might be off/not outputting CSYNC during tests
   - User confirmed MVS works via SCART
   - Test firmware detected 16 kHz on GP46 earlier
   - **Need to verify MVS is currently ON**

2. **DVI Interference**: PicoDVI on PIO0 running before video capture init
   - Unlikely since different PIO blocks
   - But timing/GPIO state might matter

3. **RP2350 PIO2 Bank 1 Access**: gpio_base=0 might not allow Bank 1 access
   - Test had gpio_base=0 and worked
   - Contradicts this theory unless context-dependent

4. **Unknown Initialization Order Issue**: Something about full firmware breaks PIO
   - Test runs standalone, works
   - Main firmware has DVI/audio/complex init, fails
   - Same PIO code, same SDK function, different result

## Current Investigation: Why Test Works But Main Code Doesn't

### Differences Between Test and Main Code

| Aspect | Test (Working) | Main (Failing) |
|---|---|---|
| **PIO Programs** | 1 simple program | 2 programs (sync + pixel) |
| **Setup** | SDK function only | SDK function + manual add |
| **PIO Usage** | Dedicated PIO2 | Shared PIO (both programs) |
| **Other PIOs** | None | PIO0 used by DVI output |
| **GPIO Init** | Simple test pin | Complex: DVI, I2S, Video |
| **Timing** | No time-critical ops | DVI running on Core 1 |

### Hypotheses

1. **PIO Conflict**: Sync on PIO2, but pixel added manually might fail
2. **GPIO Initialization Order**: DVI init (PIO0) might affect PIO2 gpio_base
3. **Timing Issue**: Complex sync program has bugs vs simple edge counter
4. **IN_BASE Misconfiguration**: Init function not setting IN_BASE correctly

---

## Detailed Test Results

### bank1_test.c Output (WORKING)
```
TEST 1: Direct GPIO Read (baseline)
  Sample 1: 26 toggles in 100ms
  Sample 2: 10 toggles in 100ms
  Sample 3: 7 toggles in 100ms

TEST 2: PIO Edge Counter with SDK gpio_range function
  Using pio_claim_free_sm_and_add_program_for_gpio_range()
  Claimed PIO2 SM0, offset=29
  gpio_base=0, pin_offset=46
  Edges counted: 16154 (16154 Hz)
  ✓ SUCCESS! Bank 1 GPIO accessible with jmp pin!
  CSYNC frequency: ~16154 Hz (~15 kHz expected)
```

### Main Firmware Output (FAILING)
```
Starting Core 1 (DVI)
Starting line-by-line capture loop
Frame capture timeout (count: 10)
Frame capture timeout (count: 20)
Frame capture timeout (count: 30)
...
```
Timeout rate: ~100ms per timeout = 10 Hz timeout loop

---

## PIO Code Evolution

### Original (BROKEN - used jmp pin for Bank 1)
```pio
wait_csync_high:
    jmp pin csync_is_high       ; BROKEN: jmp pin can't access GP46
    jmp wait_csync_high
csync_is_high:
    ; ... pixel counting logic
```

### Current Simplified Version (STILL BROKEN)
```pio
.wrap_target
    wait 0 pin, 0               ; Wait for CSYNC low (IN_BASE=46, pin 0)
    wait 1 pin, 0               ; Wait for CSYNC high (rising edge)
    set x, 31
    mov isr, x
    push noblock
.wrap
```

**Configuration**:
- SDK function claims PIO and SM for GPIO range 46
- `sm_config_set_in_pins(&c, pin_csync)` where pin_csync = 46
- PIO should be PIO2 (as in test)

---

---

## Summary of Current State (2025-12-31 23:05)

### What Works
- ✅ bank1_test.c firmware successfully detects 16 kHz on GP46 (Bank 1 GPIO)
- ✅ SDK function correctly claims PIO2 SM0 and sets up for Bank 1 access
- ✅ Main firmware initializes without errors
- ✅ PIO configuration matches working test exactly

### What Doesn't Work
- ❌ Main firmware PIO FIFO always empty
- ❌ `wait pin` instructions never trigger in main firmware context
- ❌ Same code works in test, fails in main

### Critical Question
**Is the MVS currently powered on and outputting CSYNC?**

The test firmware successfully detected signals earlier today. If the MVS is currently off, that would explain why the FIFO is empty. The user confirmed MVS works via SCART, but we need to verify it's powered on RIGHT NOW during these tests.

## Next Steps

1. **IMMEDIATE**: Verify MVS hardware state
   - Check if MVS is powered on
   - Verify CSYNC signal present on GP46 with oscilloscope OR
   - Flash bank1_test again and confirm it still detects 16 kHz

2. **If MVS is ON and test still works**:
   - Compare exact memory/register state between test and main firmware
   - Try minimal main.c with ONLY sync detection (no DVI, no audio)
   - Check if DVI init on PIO0 affects GPIO state globally

3. **Alternative Approaches**:
   - Use direct GPIO polling instead of PIO as temporary workaround
   - Try HSTX for DVI output to free up PIO0
   - Investigate RP2350-specific PIO Bank 1 requirements

---

## Hardware Info

- **Board**: WeAct Studio RP2350B Core
- **MVS**: Neo Geo arcade board (CPS2 DigiAV reference)
- **SDK Version**: pico-sdk with `pio_claim_free_sm_and_add_program_for_gpio_range()` available
- **System Clock**: 150 MHz
- **DVI Output**: 640x480p 60Hz via PicoDVI (PIO0)

---

## Code References

- Test firmware: `/Users/dudu/Projects/neopico-hd/src/misc/bank1_test.c`
- Main capture: `/Users/dudu/Projects/neopico-hd/src/video/video_capture.c`
- PIO programs: `/Users/dudu/Projects/neopico-hd/src/video/video_capture.pio`
- Pin definitions: `/Users/dudu/Projects/neopico-hd/src/pins.h`

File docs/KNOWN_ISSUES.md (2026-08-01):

# Known Issues

This document tracks known hardware and software limitations of the NeoPico-HD project.

## HDMI Sync Stability

### 1. Soft Reset Reliability

**Issue**: Performing a soft reset on the RP2350 (e.g., via `picotool` or a reset button) often results in a "No Signal" state on the connected TV or scaler.
**Symptoms**: The HDMI sink fails to handshake with the HSTX hardware after a reboot.
**Workaround**:

1. Power OFF the Neo Geo MVS.
2. Reset the NeoPico-HD (Pico).
3. Power ON the Neo Geo MVS.

### 2. HDMI 5V Power Requirement

**Issue**: Lack of +5V on the HDMI connector's power pin.
**Symptoms**: "No Signal" on specific scalers, most notably the **RetroTINK** series, TVs and some monitors.
**Observations**:

- The **Morph4K** is more forgiving and can often sync without the 5V line.
- The **RetroTINK** (and many standard TVs) will fail to detect any signal if the 5V rail is not present on the HDMI cable.
  **Requirement**: You **must** wire +5V to the HDMI connector's power pin (Pin 18) for reliable operation.

### 3. Power-Domain Back-Feed During Startup

**Current hardware note**: NeoPico-HD PCB revisions in active use already route MVS digital lines through proper level shifting. PCLK/BCK conditioning via Schmitt-trigger stage is also present.

**Observation**: In some setups, the Pico can remain partially powered when `VSYS` is removed while other rails/signals are still connected.

**Likely cause**: Back-feed through mixed power domains (USB/HDMI 5V, level-shifter paths, or I/O clamp structures depending on the exact wiring and component choices).

**Risk**:

- Non-deterministic rail ramp/decay behavior.
- Startup transients that can disturb digital capture lock.
- Intermittent bring-up failures that disappear after a later relock/reset.

**Recommended hardware mitigations**:

1. Use level shifters/translators with **partial-power-down tolerance / Ioff** support.
2. Gate translator **OE** so MVS -> Pico signals are Hi-Z until 3.3V is stable.
3. Prevent source back-feeding between power inputs (USB vs external 5V) using proper power-path design (ideal diode/power mux).
4. Keep local decoupling close to VSYS/3V3 and translator rails.

### 4. Intermittent Scratched Audio on Cold Power-Up

**Issue**: When MVS and Pico power up together, audio can start heavily scratched/corrupted.

**Behavior**:

- Issue is intermittent (not every boot).
- A later Pico reset or capture relock often clears it immediately.

**Working hypothesis**: I2S capture can occasionally lock with bad startup phase/alignment during power transients, then remain in an active-but-corrupted state until capture is re-armed.

**Software status**:

- Startup mute/warmup is used.
- Capture includes watchdog restart on sustained inactivity.
- Current firmware adds a one-shot post-warmup relock path to emulate the "reset after clocks settle" recovery, without adding ISR load.

### 5. Rare Periodic HDMI Audio Dropouts (Resolved 2026-07-12)

**Issue**: A brief audio drop every tens of minutes, on all resolutions, both MVS and AES sources, across all firmware versions. Severity depended on the connected sink; some TVs never showed it.

**Root cause**: The Data Island scheduler paced audio with a floor-truncated 16.16 samples-per-line value, delivering ~0.18 samples/s (480p/240p; ~0.09 at 720p) less than the exactly-48000 Hz rate advertised via ACR on the same clock. The sink's audio buffer drained until it concealed with a short mute. Firmware buffers stayed healthy (the SRC servo locks production to the scheduler), so no firmware counter could see it.

**Resolution**: pico_hdmi `b6422ee` (`PICO_HDMI_EXACT_AUDIO_PACING`, default ON) paces with an exact rational accumulator; delivery now matches the ACR rate exactly in every runtime mode. NeoPico bump: `267ae19`. See `docs/HSTX_IMPLEMENTATION.md`, "Pacing & Clock Accuracy".

**Remaining distinct mechanisms** (not covered by this fix):

- A real video sync loss (>100 ms without vsync) triggers an audio re-arm: ~0.5 s mute coinciding with a visible video hiccup. Intentional recovery behavior.
- A Core 1 background stall longer than the queue cushion (~10 ms) splices silence packets. Build with `-DNEOPICO_DIAG_AUDIO_OSD=ON` to watch the `AU<n>` counter on the selftest screen; it climbing during an audible drop indicates this mechanism.

### 6. 720p Transient Corruption on Direct Low-Latency Sinks (Fixed on Affected Sink)

**Issue**: At 720p only, rare split-second bursts of whole-frame TMDS
corruption (purple/green scanline noise, including over the black pillarbox
bars) on sinks that consume the signal directly without re-clocking. Observed
on a Samsung Q80 in Game Mode; the same TV in Normal mode, gaming monitors,
and all scalers (RetroTINK 4K, Morph4K) are clean.

**Rates**: roughly one event per minute during gameplay, roughly one per five
minutes on a static screen. 480p is unconditionally clean in every setup.

**What is known** (2026-07): buffered/re-clocking sinks stay clean, while the
direct Samsung low-latency path can expose the transient. Displayed-content
changes are neither necessary nor sufficient as a trigger; the surviving
correlation is that only builds rendering the live capture ring have glitched.
The previous runtime timing drove clk_hstx at 372 MHz against a 150 MHz
datasheet rating. Main now uses exact-clock reduced-blanking 720p at 320 MHz
clk_hstx, a 64 MHz pixel clock, and 59.979 Hz. This remains above the rated HSTX
clock and uses non-CTA VIC-0 timing, so broad sink compatibility and the rare
sink compatibility remain under test. The affected Samsung result is recorded
below.

A separate orange-line diagnostic proved that one top-of-frame artifact was a
not-ready capture-ring read rather than TMDS corruption. The ring guard
(retaining the previous complete frame instead of an empty one; at the time an
experimental default-off option, now permanently on) passed an initial
no-logging smoke test. Continuous USB counter logging itself
disturbed video, so its event rate is not a clean baseline. A direct-TV test of
the corrected MVS release profile, with exact-clock 720p and the frame
guard enabled, also eliminated the magenta transient on the affected Samsung.
Because both changes were present, this result does not isolate which change
was necessary.

**Historical workarounds**: use 480p for direct TV connections, or run 720p
through a scaler or the TV's standard (non-game) mode.

**Validated fix profile** (2026-07-31): exact-clock 64 MHz runtime 720p plus
the ring guard (now permanently on). The previously affected Samsung now runs
cleanly in the direct low-latency path. Keep both changes together unless a
controlled A/B later isolates the required component.

**Tracking**: investigation log, experiment queue, and production mitigation
analysis in [`720P_PURPLE_GLITCH.md`](720P_PURPLE_GLITCH.md) and
[`720P_SAMSUNG_GAME_MODE_INVESTIGATION.md`](720P_SAMSUNG_GAME_MODE_INVESTIGATION.md).

---

## OSD & UI

- **Current Status**: OSD and the root settings menu are enabled by default.

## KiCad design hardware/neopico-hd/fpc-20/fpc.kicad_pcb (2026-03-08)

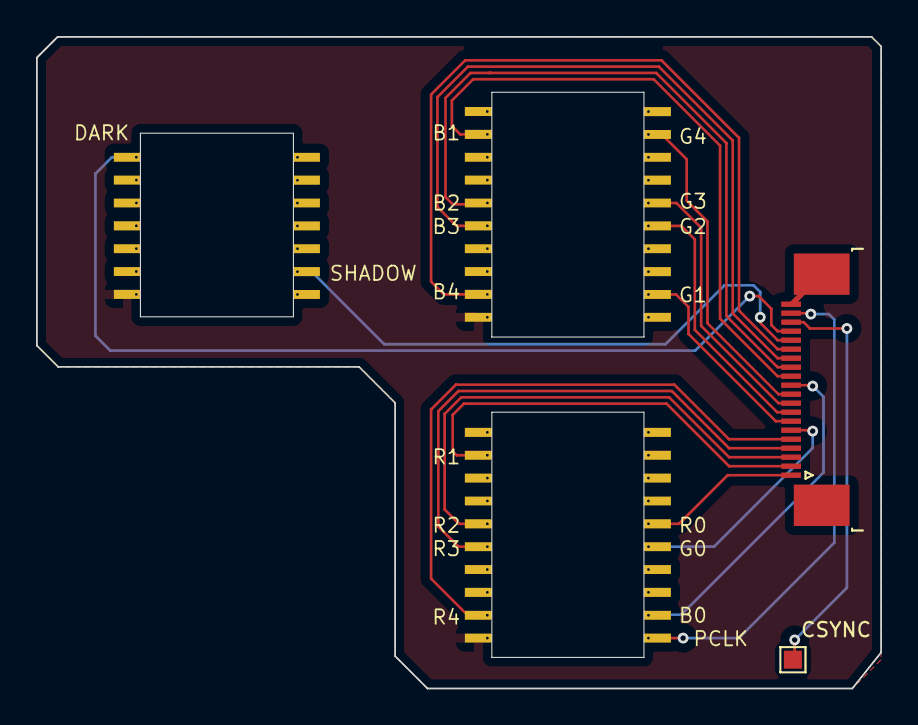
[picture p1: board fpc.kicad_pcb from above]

Board: 2 copper layers, 46.9 x 36.2 mm, 3 parts (0 on the bottom side), 20 nets.

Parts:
CSYNC_PAD: TestPoint_Pad_1.0x1.0mm
J1: Conn_02x27_Pin; MVS_Color_Latches
J2: Conn_01x20_Pin; TE_2-1734839-0_1x20-1MP_P0.5mm_Horizontal

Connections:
B0: J1.32, J2.11
B1: J1.2, J2.12
B2: J1.5, J2.13
B3: J1.6, J2.14
B4: J1.9, J2.15
CSYNC: CSYNC_PAD.1, J2.18
DARK: J1.41, J2.17
G0: J1.35, J2.6
G1: J1.12, J2.7
G2: J1.15, J2.8
G3: J1.16, J2.9
G4: J1.19, J2.10
GND: J1.10, J1.30, J1.47, J2.20
PCLK: J1.31, J2.19
R0: J1.36, J2.1
R1: J1.22, J2.2
R2: J1.25, J2.3
R3: J1.26, J2.4
R4: J1.29, J2.5
SHADOW: J1.53, J2.16

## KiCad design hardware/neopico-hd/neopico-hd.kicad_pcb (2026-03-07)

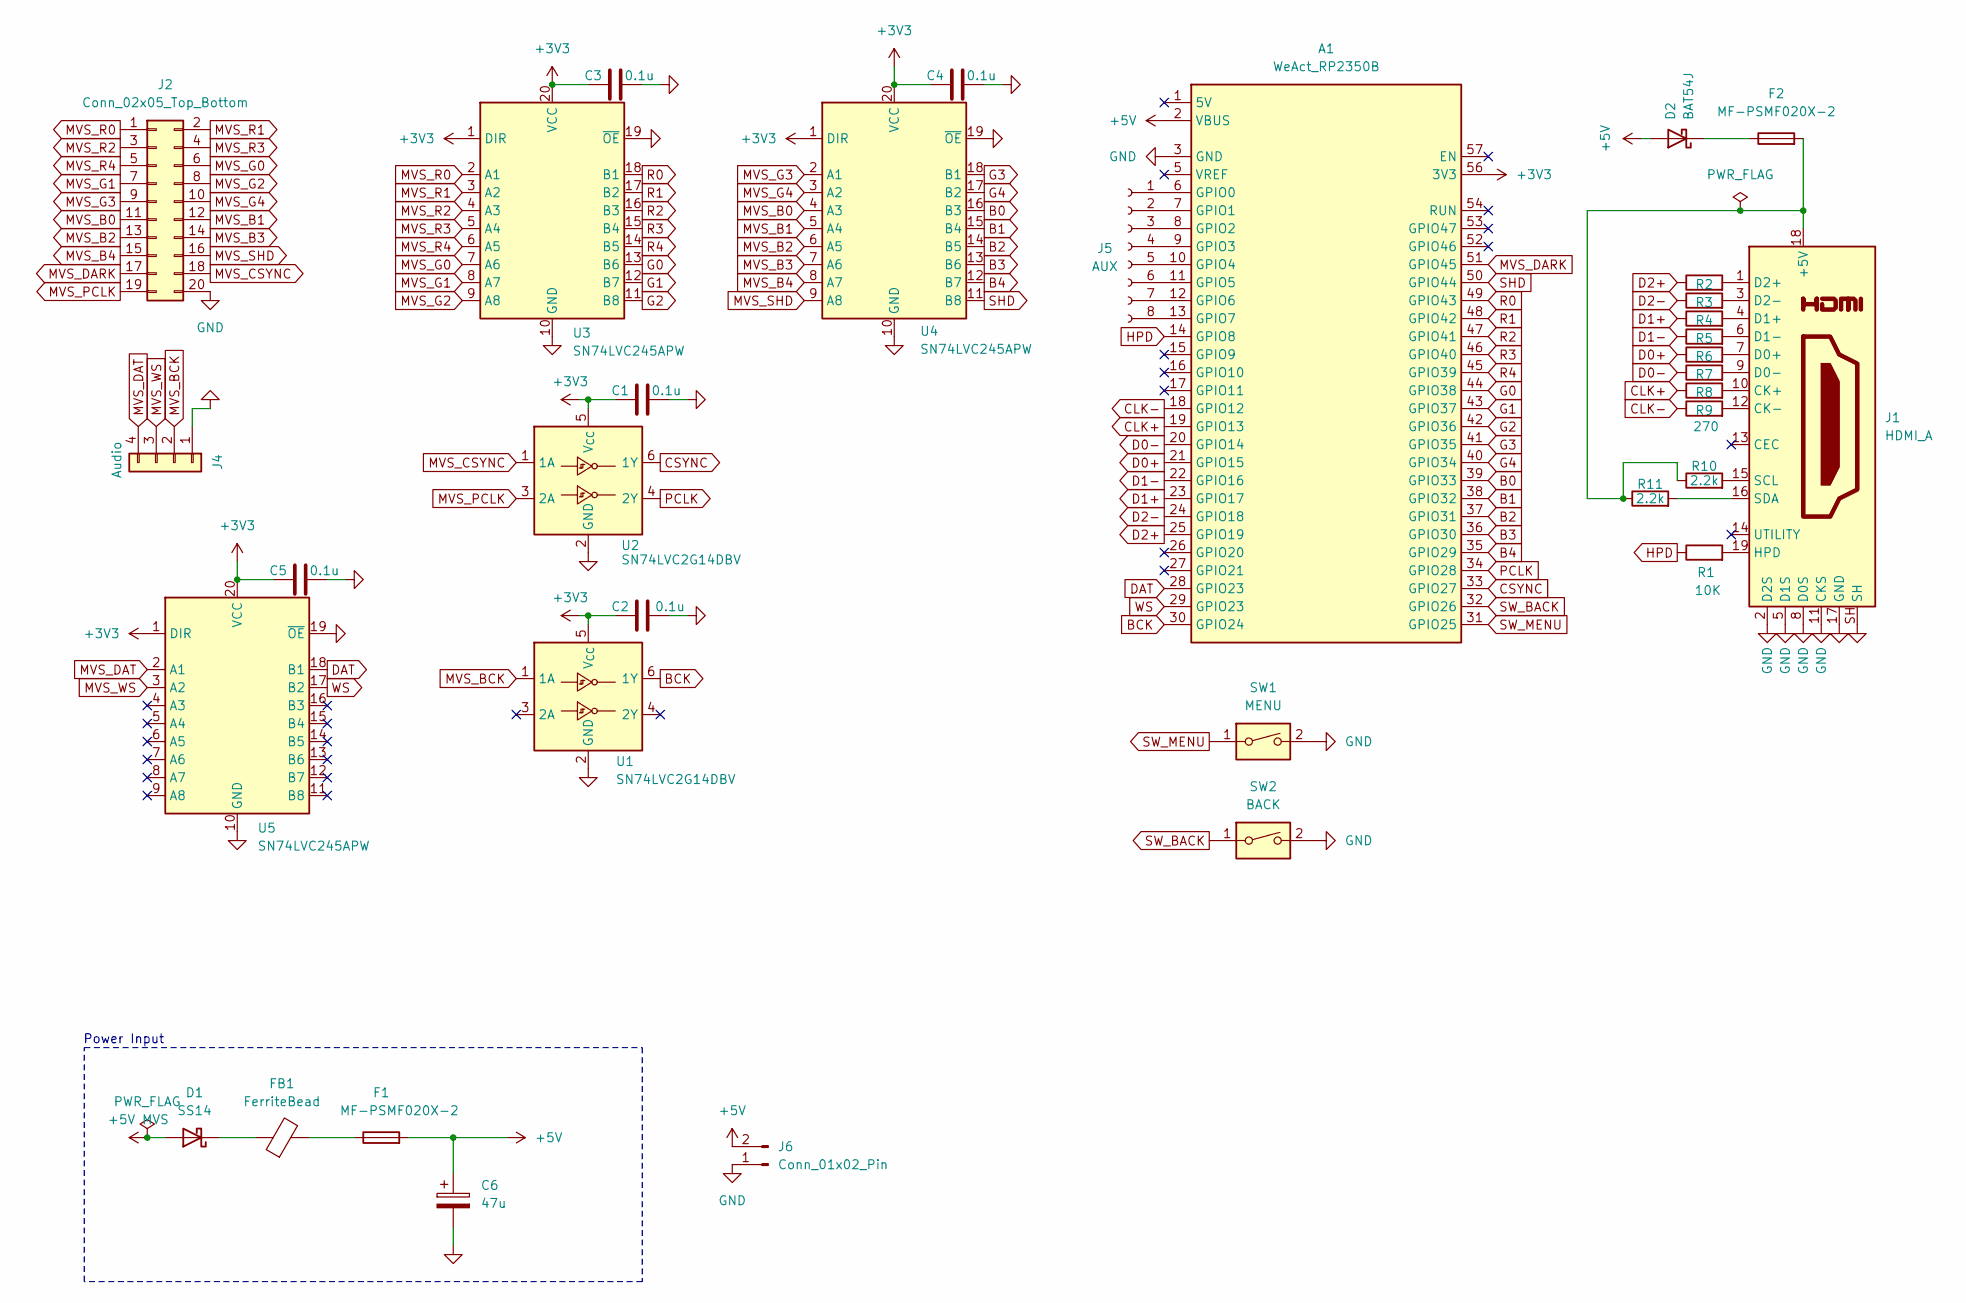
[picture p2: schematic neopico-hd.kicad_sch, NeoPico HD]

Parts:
A1: WeAct_RP2350B
C1, C2, C3, C4, C5: 0.1u; C_0805_2012Metric_Pad1.18x1.45mm_HandSolder; LCSC C1711
C6: 47u; CP_Elec_6.3x5.4_Nichicon; LCSC C7094687
D1: SS14; D_SMA; LCSC C83852
D2: BAT54J; D_SOD-323F; LCSC C86299
F1: MF-PSMF020X-2; C_0805_2012Metric; LCSC C89657
F2: MF-PSMF020X-2; Fuse_0805_2012Metric; LCSC C89657
FB1: FerriteBead; C_0805_2012Metric; LCSC C76815
J1: HDMI_A; HDMI_A_Molex_208658-1001_Horizontal; LCSC C111617
J2: Conn_02x05_Top_Bottom; IDC-Header_2x10_P2.54mm_Vertical
J4: Audio; JST_XA_B04B-XASK-1_1x04_P2.50mm_Vertical
J5: AUX; PinHeader_2x04_P2.54mm_Vertical
J6: Conn_01x02_Pin; PinHeader_1x02_P2.54mm_Vertical
R1: 10K; R_0603_1608Metric; LCSC C98220
R2, R3, R4, R5, R6, R7, R8, R9: 270; R_0402_1005Metric; LCSC C163474
R10, R11: 2.2k; R_0603_1608Metric; LCSC C114662
SW1: MENU; SW_SPST_CK_KXT3
SW2: BACK; SW_SPST_CK_KXT3
U1, U2: SN74LVC2G14DBV; SOT-23-6; LCSC C12401
U3, U4, U5: SN74LVC245APW; TSSOP-20_4.4x6.5mm_P0.65mm; LCSC C7848

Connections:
+3V3: A1.55 (3V3), A1.56 (3V3), C1.1, C2.1, C3.1, C4.1, C5.1, U1.5 (V_{CC}), U2.5 (V_{CC}), U3.1 (DIR), U3.20 (VCC), U4.1 (DIR), U4.20 (VCC), U5.1 (DIR), U5.20 (VCC); also elsewhere on the board
+5V: A1.2 (VBUS), C6.1, D2.2 (A), F1.2, J6.2
+5V MVS: D1.2 (A); also elsewhere on the board
B0: A1.39 (GPIO33), U4.16 (B3)
B1: A1.38 (GPIO32), U4.15 (B4)
B2: A1.37 (GPIO31), U4.14 (B5)
B3: A1.36 (GPIO30), U4.13 (B6)
B4: A1.35 (GPIO29), U4.12 (B7)
BCK: A1.30 (GPIO24), U1.6 (1Y)
CLK+: A1.19 (GPIO13), R8.1
CLK-: A1.18 (GPIO12), R9.1
CSYNC: A1.33 (GPIO27), U2.6 (1Y)
D0+: A1.21 (GPIO15), R6.1
D0-: A1.20 (GPIO14), R7.1
D1+: A1.23 (GPIO17), R4.1
D1-: A1.22 (GPIO16), R5.1
D2+: A1.25 (GPIO19), R2.1
D2-: A1.24 (GPIO18), R3.1
DAT: A1.28 (GPIO23), U5.18 (B1)
G0: A1.44 (GPIO38), U3.13 (B6)
G1: A1.43 (GPIO37), U3.12 (B7)
G2: A1.42 (GPIO36), U3.11 (B8)
G3: A1.41 (GPIO35), U4.18 (B1)
G4: A1.40 (GPIO34), U4.17 (B2)
GND: A1.3 (GND), A1.4 (GND), A1.58 (GND), A1.59 (GND), A1.60 (GND), C1.2, C2.2, C3.2, C4.2, C5.2, C6.2, J1.2 (D2S), J1.5 (D1S), J1.8 (D0S), J1.11 (CKS), J1.17 (GND), J1.SH, J2.20, J4.1, J6.1, SW1.2, SW2.2, U1.2 (GND), U2.2 (GND), U3.10 (GND), U3.19 (~OE), U4.10 (GND), U4.19 (~OE), U5.10 (GND), U5.19 (~OE); also elsewhere on the board
HPD: A1.14 (GPIO8), R1.1
MVS_B0: J2.11, U4.4 (A3)
MVS_B1: J2.12, U4.5 (A4)
MVS_B2: J2.13, U4.6 (A5)
MVS_B3: J2.14, U4.7 (A6)
MVS_B4: J2.15, U4.8 (A7)
MVS_BCK: J4.2, U1.1 (1A)
MVS_CSYNC: J2.18, U2.1 (1A)
MVS_DARK: A1.51 (GPIO45), J2.17
MVS_DAT: J4.4, U5.2 (A1)
MVS_G0: J2.6, U3.7 (A6)
MVS_G1: J2.7, U3.8 (A7)
MVS_G2: J2.8, U3.9 (A8)
MVS_G3: J2.9, U4.2 (A1)
MVS_G4: J2.10, U4.3 (A2)
MVS_PCLK: J2.19, U2.3 (2A)
MVS_R0: J2.1, U3.2 (A1)
MVS_R1: J2.2, U3.3 (A2)
MVS_R2: J2.3, U3.4 (A3)
MVS_R3: J2.4, U3.5 (A4)
MVS_R4: J2.5, U3.6 (A5)
MVS_SHD: J2.16, U4.9 (A8)
MVS_WS: J4.3, U5.3 (A2)
unnamed: A1.6 (GPIO0), J5.1
unnamed: A1.7 (GPIO1), J5.2
unnamed: A1.8 (GPIO2), J5.3
unnamed: A1.9 (GPIO3), J5.4
unnamed: A1.10 (GPIO4), J5.5
unnamed: A1.11 (GPIO5), J5.6
unnamed: A1.12 (GPIO6), J5.7
unnamed: A1.13 (GPIO7), J5.8
unnamed: D1.1 (K), FB1.1
unnamed: D2.1 (K), F2.1
unnamed: F1.1, FB1.2
unnamed: F2.2, J1.18 (+5V), R10.1, R11.1
unnamed: J1.10 (CK+), R8.2
unnamed: J1.12 (CK-), R9.2
unnamed: J1.7 (D0+), R6.2
unnamed: J1.9 (D0-), R7.2
unnamed: J1.4 (D1+), R4.2
unnamed: J1.6 (D1-), R5.2
unnamed: J1.1 (D2+), R2.2
unnamed: J1.3 (D2-), R3.2
unnamed: J1.19 (HPD), R1.2
unnamed: J1.15 (SCL), R10.2
unnamed: J1.16 (SDA), R11.2
PCLK: A1.34 (GPIO28), U2.4 (2Y)
R0: A1.49 (GPIO43), U3.18 (B1)
R1: A1.48 (GPIO42), U3.17 (B2)
R2: A1.47 (GPIO41), U3.16 (B3)
R3: A1.46 (GPIO40), U3.15 (B4)
R4: A1.45 (GPIO39), U3.14 (B5)
SHD: A1.50 (GPIO44), U4.11 (B8)
SW_BACK: A1.32 (GPIO26), SW2.1
SW_MENU: A1.31 (GPIO25), SW1.1
WS: A1.29 (GPIO23), U5.17 (B2)

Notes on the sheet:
Power Input

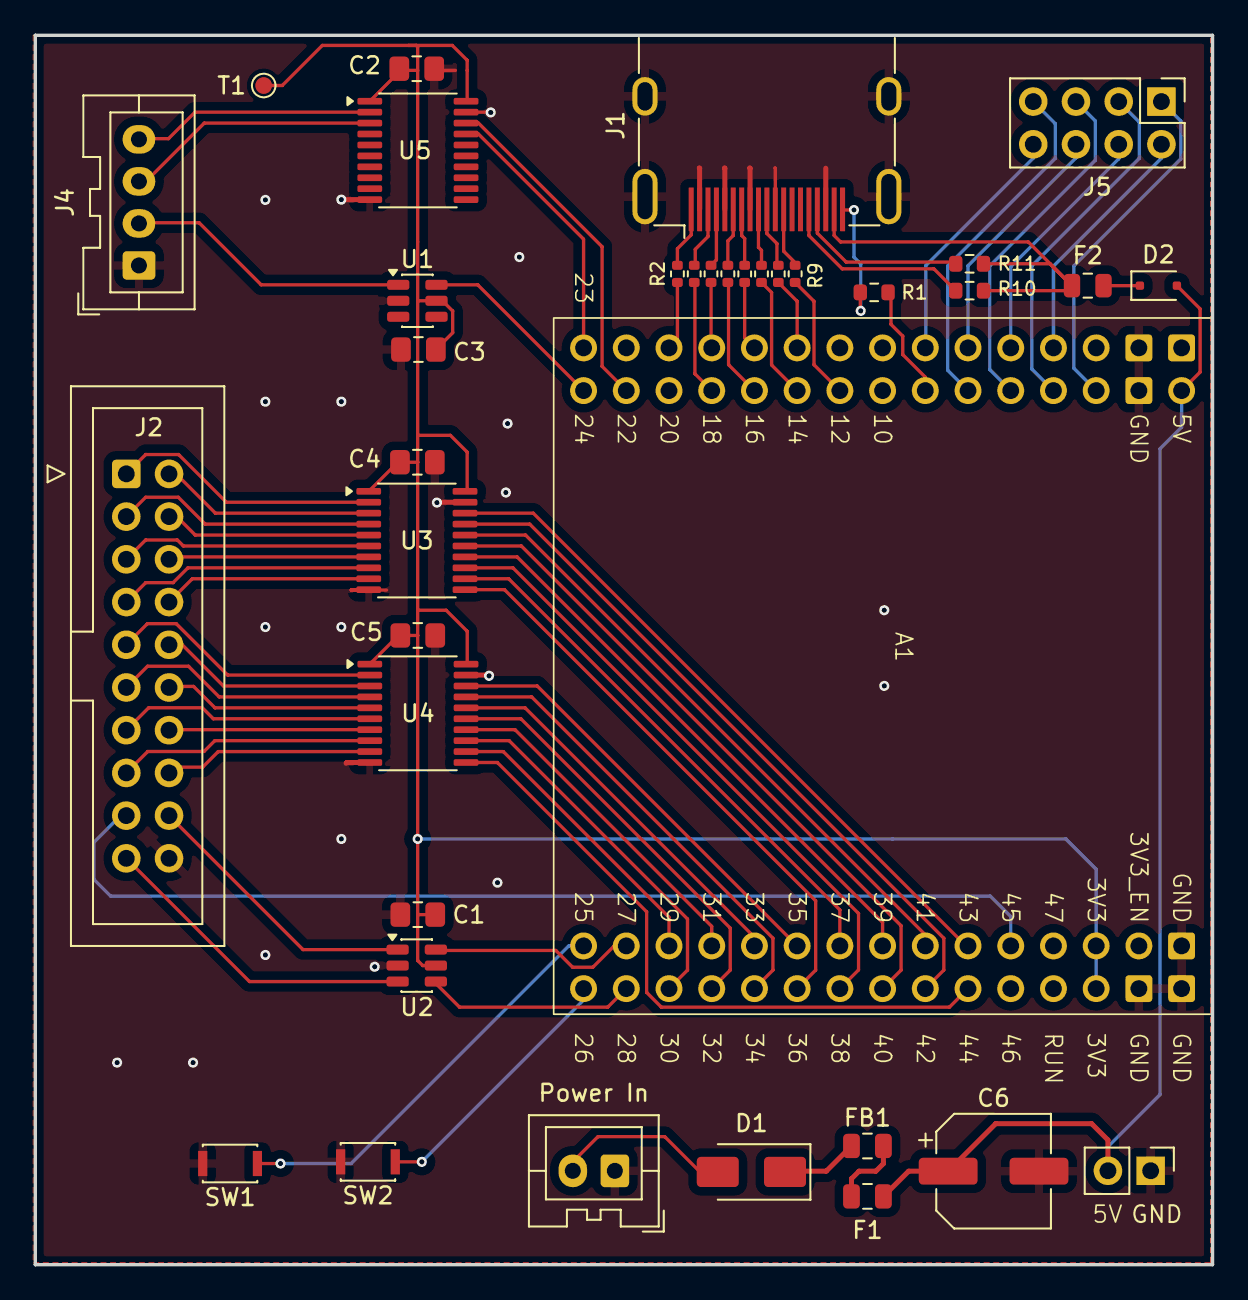
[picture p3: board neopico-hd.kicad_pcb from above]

Board: 2 copper layers, 70.0 x 73.1 mm, 37 parts (0 on the bottom side), 81 nets.

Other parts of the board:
Power In: JST_XA_B02B-XASK-1_1x02_P2.50mm_Vertical
T1: TestPoint_Pad_D1.0mm

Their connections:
+3V3: T1.1; also elsewhere on the board
+5V MVS: Power In.2; also elsewhere on the board
GND: Power In.1; also elsewhere on the board

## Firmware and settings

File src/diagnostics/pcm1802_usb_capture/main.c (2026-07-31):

/**
 * NeoPico-HD standalone PCM1802 USB capture diagnostic.
 *
 * This target intentionally initializes no video, HSTX, HDMI, SRC, filters, or
 * volume processing. It captures the PCM1802's standard-I2S DOUT as signed
 * 24-bit stereo samples and forwards either all 24 bits or the upper 16 bits
 * in framed packets over a TinyUSB CDC port.
 *
 * The host must complete an INFO -> HELLO -> START -> STARTED handshake before
 * capture begins. Every stream packet carries a session ID, sequence number,
 * source-frame index, cumulative DMA-drop count, and CRC32 so a receiver can
 * attach at any time without accepting stale or partial data.
 */

#include "pico/stdlib.h"

#include "hardware/dma.h"
#include "hardware/gpio.h"
#include "hardware/irq.h"
#include "hardware/pio.h"
#include "hardware/sync.h"

#include <stddef.h>
#include <stdint.h>
#include <string.h>

#include "bsp/board_api.h"
#include "i2s_capture.pio.h"
#include "tusb.h"

#if __BYTE_ORDER__ != __ORDER_LITTLE_ENDIAN__
#error "The PCM1802 USB capture protocol requires a little-endian target"
#endif

// PCM1802 standard-I2S wiring used by the production NeoPico-HD firmware.
#define PCM1802_PIN_DOUT 22u
#define PCM1802_PIN_LRCK 23u
#define PCM1802_PIN_BCK 24u

#define PCM1802_SAMPLE_RATE 48000u
#define PCM1802_CHANNELS 2u

#ifndef NEOPICO_PCM1802_USB_BITS_PER_SAMPLE
#define NEOPICO_PCM1802_USB_BITS_PER_SAMPLE 24
#endif

#if NEOPICO_PCM1802_USB_BITS_PER_SAMPLE != 16 && NEOPICO_PCM1802_USB_BITS_PER_SAMPLE != 24
#error "NEOPICO_PCM1802_USB_BITS_PER_SAMPLE must be 16 or 24"
#endif

#define PCM1802_BITS_PER_SAMPLE ((uint32_t)NEOPICO_PCM1802_USB_BITS_PER_SAMPLE)
#define PCM1802_BYTES_PER_SAMPLE (PCM1802_BITS_PER_SAMPLE / 8u)

// Capture always remains 24-bit. The optional 16-bit transport discards only
// the least-significant byte while packets are staged for USB.
#define AUDIO_FRAMES_PER_PACKET 128u
#define AUDIO_WORDS_PER_PACKET (AUDIO_FRAMES_PER_PACKET * PCM1802_CHANNELS)
#define AUDIO_BYTES_PER_FRAME (PCM1802_CHANNELS * PCM1802_BYTES_PER_SAMPLE)
#define AUDIO_PAYLOAD_BYTES (AUDIO_FRAMES_PER_PACKET * AUDIO_BYTES_PER_FRAME)

#if NEOPICO_PCM1802_USB_BITS_PER_SAMPLE == 16
_Static_assert(AUDIO_PAYLOAD_BYTES == 512u, "Unexpected 16-bit audio payload size");
#else
_Static_assert(AUDIO_PAYLOAD_BYTES == 768u, "Unexpected 24-bit audio payload size");
#endif

// The DMA ring holds about 85 ms at 48 kHz. Keep one packet of separation
// between the reader and writer so DMA cannot overwrite a packet as it is
// copied into the USB staging buffer.
#define DMA_RING_WORDS 8192u
#define DMA_RING_MASK (DMA_RING_WORDS - 1u)
#define DMA_RING_BYTES (DMA_RING_WORDS * sizeof(uint32_t))
#define DMA_SAFE_BACKLOG_WORDS (DMA_RING_WORDS - AUDIO_WORDS_PER_PACKET)

#define PROTOCOL_VERSION 1u
#define COMMAND_MAGIC "NPCMCMD1"
#define STREAM_MAGIC "NPCMDAT1"

enum command_type {
    COMMAND_INFO = 1,
    COMMAND_START = 2,
    COMMAND_STOP = 3,
};

enum packet_type {
    PACKET_HELLO = 1,
    PACKET_STARTED = 2,
    PACKET_AUDIO = 3,
    PACKET_STOPPED = 4,
    PACKET_ERROR = 5,
};

typedef struct __attribute__((packed)) {
    uint8_t magic[8];
    uint8_t version;
    uint8_t command;
    uint16_t packet_bytes;
    uint32_t session_id;
    uint32_t crc32;
} command_packet_t;

typedef struct __attribute__((packed)) {
    uint8_t magic[8];
    uint8_t version;
    uint8_t type;
    uint16_t header_bytes;
    uint32_t session_id;
    uint32_t sequence;
    uint32_t sample_rate;
    uint64_t first_frame;
    uint16_t frame_count;
    uint8_t channels;
    uint8_t bits_per_sample;
    uint32_t payload_bytes;
    uint64_t dropped_frames;
} stream_header_t;

_Static_assert(sizeof(command_packet_t) == 20u, "Unexpected command packet layout");
_Static_assert(sizeof(stream_header_t) == 48u, "Unexpected stream header layout");

#define STREAM_PACKET_MAX_BYTES (sizeof(stream_header_t) + AUDIO_PAYLOAD_BYTES + sizeof(uint32_t))

static uint32_t crc32_table[256];

static uint32_t dma_ring[DMA_RING_WORDS] __attribute__((aligned(DMA_RING_BYTES)));
static PIO capture_pio = pio2;
static const uint capture_sm = 0;
static uint capture_program_offset;
static int capture_dma_channel;
static volatile uint32_t capture_dma_wraps;
static bool capture_running;
static uint64_t capture_read_words;
static uint64_t capture_dropped_frames;

static uint8_t tx_packet[STREAM_PACKET_MAX_BYTES] __attribute__((aligned(4)));
static uint32_t tx_packet_bytes;
static uint32_t tx_packet_offset;

static uint8_t command_buffer[sizeof(command_packet_t)];
static uint32_t command_buffer_used;

static bool session_armed;
static bool streaming;
static uint32_t active_session_id;
static uint32_t packet_sequence;

static void crc32_init(void)
{
    for (uint32_t i = 0; i < 256u; ++i) {
        uint32_t value = i;
        for (uint32_t bit = 0; bit < 8u; ++bit) {
            value = (value >> 1u) ^ ((value & 1u) ? 0xEDB88320u : 0u);
        }
        crc32_table[i] = value;
    }
}

static uint32_t crc32_calculate(const uint8_t *data, size_t size)
{
    uint32_t crc = 0xFFFFFFFFu;
    for (size_t i = 0; i < size; ++i) {
        crc = crc32_table[(crc ^ data[i]) & 0xFFu] ^ (crc >> 8u);
    }
    return crc ^ 0xFFFFFFFFu;
}

static void __isr capture_dma_irq0_handler(void)
{
    const uint32_t mask = 1u << (uint)capture_dma_channel;
    if (dma_hw->ints0 & mask) {
        dma_hw->ints0 = mask;
        capture_dma_wraps++;
    }
}

static void capture_init(void)
{
    gpio_init(PCM1802_PIN_DOUT);
    gpio_init(PCM1802_PIN_LRCK);
    gpio_init(PCM1802_PIN_BCK);
    gpio_set_dir(PCM1802_PIN_DOUT, GPIO_IN);
    gpio_set_dir(PCM1802_PIN_LRCK, GPIO_IN);
    gpio_set_dir(PCM1802_PIN_BCK, GPIO_IN);
    gpio_disable_pulls(PCM1802_PIN_DOUT);
    gpio_disable_pulls(PCM1802_PIN_LRCK);
    gpio_disable_pulls(PCM1802_PIN_BCK);
    gpio_set_input_hysteresis_enabled(PCM1802_PIN_DOUT, true);
    gpio_set_input_hysteresis_enabled(PCM1802_PIN_LRCK, true);
    gpio_set_input_hysteresis_enabled(PCM1802_PIN_BCK, true);

    pio_set_gpio_base(capture_pio, 0);
    capture_program_offset = pio_add_program(capture_pio, &i2s_capture_pcm1802_program);
    i2s_capture_pcm1802_program_init(capture_pio, capture_sm, capture_program_offset, PCM1802_PIN_DOUT,
                                     PCM1802_PIN_LRCK, PCM1802_PIN_BCK);

    capture_dma_channel = dma_claim_unused_channel(true);
    dma_channel_config config = dma_channel_get_default_config((uint)capture_dma_channel);
    channel_config_set_read_increment(&config, false);
    channel_config_set_write_increment(&config, true);
    channel_config_set_dreq(&config, pio_get_dreq(capture_pio, capture_sm, false));
    channel_config_set_transfer_data_size(&config, DMA_SIZE_32);
    channel_config_set_ring(&config, true, 15u); // 2^15 bytes = 8192 words.
    channel_config_set_high_priority(&config, true);

    dma_channel_configure((uint)capture_dma_channel, &config, dma_ring, &capture_pio->rxf[capture_sm],
                          dma_encode_transfer_count_with_self_trigger(DMA_RING_WORDS), false);

    dma_channel_set_irq0_enabled((uint)capture_dma_channel, true);
    irq_set_exclusive_handler(DMA_IRQ_0, capture_dma_irq0_handler);
    irq_set_enabled(DMA_IRQ_0, true);
}

static void capture_stop(void)
{
    if (!capture_running) {
        return;
    }

    pio_sm_set_enabled(capture_pio, capture_sm, false);
    dma_channel_abort((uint)capture_dma_channel);
    dma_hw->ints0 = 1u << (uint)capture_dma_channel;
    capture_running = false;
}

static void capture_start(void)
{
    capture_stop();

    pio_sm_set_enabled(capture_pio, capture_sm, false);
    pio_sm_restart(capture_pio, capture_sm);
    pio_sm_clear_fifos(capture_pio, capture_sm);
    pio_sm_exec(capture_pio, capture_sm, pio_encode_jmp(capture_program_offset));

    memset(dma_ring, 0, sizeof(dma_ring));
    dma_channel_abort((uint)capture_dma_channel);
    dma_hw->ints0 = 1u << (uint)capture_dma_channel;

    uint32_t irq_state = save_and_disable_interrupts();
    capture_dma_wraps = 0;
    restore_interrupts(irq_state);

    capture_read_words = 0;
    capture_dropped_frames = 0;

    dma_channel_set_write_addr((uint)capture_dma_channel, dma_ring, false);
    dma_channel_set_transfer_count((uint)capture_dma_channel,
                                   dma_encode_transfer_count_with_self_trigger(DMA_RING_WORDS), false);
    dma_channel_start((uint)capture_dma_channel);
    pio_sm_set_enabled(capture_pio, capture_sm, true);
    capture_running = true;
}

static uint64_t capture_words_written(void)
{
    const uint32_t dma_mask = 1u << (uint)capture_dma_channel;
    const uintptr_t ring_base = (uintptr_t)dma_ring;

    uint32_t irq_state = save_and_disable_interrupts();
    uint32_t wraps;
    uint32_t pending_before;
    uint32_t pending_after;
    uintptr_t write_address;

    // DMA continues while CPU interrupts are masked. Retry if it crosses the
    // ring boundary during the snapshot so the wrap count and write address
    // always describe the same DMA lap.
    do {
        wraps = capture_dma_wraps;
        pending_before = dma_hw->ints0 & dma_mask;
        write_address = (uintptr_t)dma_hw->ch[capture_dma_channel].write_addr;
        pending_after = dma_hw->ints0 & dma_mask;
    } while (pending_before != pending_after);

    if (pending_before) {
        // The self-triggering DMA has wrapped, but its IRQ has not yet run.
        wraps++;
    }
    restore_interrupts(irq_state);

    const uint32_t write_index = (uint32_t)((write_address - ring_base) / sizeof(uint32_t)) & DMA_RING_MASK;
    return (uint64_t)wraps * DMA_RING_WORDS + write_index;
}

static uint64_t capture_available_words(void)
{
    const uint64_t words_written = capture_words_written();
    if (words_written < capture_read_words) {
        // Defensive recovery for a capture restart or unexpected DMA reset.
        capture_read_words = words_written & ~1ull;
    }

    uint64_t available = words_written - capture_read_words;
    if (available > DMA_SAFE_BACKLOG_WORDS) {
        uint64_t lost_words = available - DMA_SAFE_BACKLOG_WORDS;
        lost_words = (lost_words + 1u) & ~1ull; // Preserve left/right pairing.
        capture_read_words += lost_words;
        capture_dropped_frames += lost_words / PCM1802_CHANNELS;
        available = words_written - capture_read_words;
    }

    return available & ~1ull;
}

static void usb_discard_pending_tx(void)
{
    tx_packet_bytes = 0;
    tx_packet_offset = 0;
    if (tud_cdc_connected()) {
        tud_cdc_write_clear();
    }
}

static void packet_finalize(uint32_t bytes_without_crc)
{
    const uint32_t crc = crc32_calculate(tx_packet, bytes_without_crc);
    memcpy(&tx_packet[bytes_without_crc], &crc, sizeof(crc));
    tx_packet_bytes = bytes_without_crc + sizeof(crc);
    tx_packet_offset = 0;
}

static void packet_begin(uint8_t type, uint64_t first_frame, uint16_t frame_count, uint32_t payload_bytes)
{
    stream_header_t header;
    memset(&header, 0, sizeof(header));
    memcpy(header.magic, STREAM_MAGIC, sizeof(header.magic));
    header.version = PROTOCOL_VERSION;
    header.type = type;
    header.header_bytes = sizeof(header);
    header.session_id = active_session_id;
    header.sequence = packet_sequence++;
    header.sample_rate = PCM1802_SAMPLE_RATE;
    header.first_frame = first_frame;
    header.frame_count = frame_count;
    header.channels = PCM1802_CHANNELS;
    header.bits_per_sample = PCM1802_BITS_PER_SAMPLE;
    header.payload_bytes = payload_bytes;
    header.dropped_frames = capture_dropped_frames;
    memcpy(tx_packet, &header, sizeof(header));
}

static void queue_control_packet(uint8_t type)
{
    packet_begin(type, capture_read_words / PCM1802_CHANNELS, 0, 0);
    packet_finalize(sizeof(stream_header_t));
}

static void pack_sample(uint8_t *destination, uint32_t raw_sample)
{
#if NEOPICO_PCM1802_USB_BITS_PER_SAMPLE == 24
    destination[0] = (uint8_t)(raw_sample & 0xFFu);
    destination[1] = (uint8_t)((raw_sample >> 8u) & 0xFFu);
    destination[2] = (uint8_t)((raw_sample >> 16u) & 0xFFu);
#else
    // Keep the most-significant 16 bits of the signed 24-bit PCM sample.
    destination[0] = (uint8_t)((raw_sample >> 8u) & 0xFFu);
    destination[1] = (uint8_t)((raw_sample >> 16u) & 0xFFu);
#endif
}

static bool queue_audio_packet(void)
{
    if (!capture_running || capture_available_words() < AUDIO_WORDS_PER_PACKET) {
        return false;
    }

    const uint64_t first_frame = capture_read_words / PCM1802_CHANNELS;
    packet_begin(PACKET_AUDIO, first_frame, AUDIO_FRAMES_PER_PACKET, AUDIO_PAYLOAD_BYTES);

    uint8_t *payload = &tx_packet[sizeof(stream_header_t)];
    __dmb(); // Observe completed DMA writes before copying the ring.
    for (uint32_t frame = 0; frame < AUDIO_FRAMES_PER_PACKET; ++frame) {
        const uint64_t word_offset = capture_read_words + (uint64_t)frame * PCM1802_CHANNELS;
        const uint32_t left = dma_ring[(uint32_t)word_offset & DMA_RING_MASK];
        const uint32_t right = dma_ring[((uint32_t)word_offset + 1u) & DMA_RING_MASK];
        pack_sample(&payload[frame * AUDIO_BYTES_PER_FRAME], left);
        pack_sample(&payload[frame * AUDIO_BYTES_PER_FRAME + PCM1802_BYTES_PER_SAMPLE], right);
    }

    capture_read_words += AUDIO_WORDS_PER_PACKET;
    packet_finalize(sizeof(stream_header_t) + AUDIO_PAYLOAD_BYTES);
    return true;
}

static void usb_tx_task(void)
{
    if (tx_packet_bytes == 0 || !tud_cdc_connected()) {
        return;
    }

    const uint32_t available = tud_cdc_write_available();
    if (available == 0) {
        return;
    }

    uint32_t remaining = tx_packet_bytes - tx_packet_offset;
    if (remaining > available) {
        remaining = available;
    }

    const uint32_t written = tud_cdc_write(&tx_packet[tx_packet_offset], remaining);
    tx_packet_offset += written;
    tud_cdc_write_flush();

    if (tx_packet_offset == tx_packet_bytes) {
        tx_packet_bytes = 0;
        tx_packet_offset = 0;
    }
}

static void reset_session(void)
{
    capture_stop();
    session_armed = false;
    streaming = false;
    active_session_id = 0;
    packet_sequence = 0;
    command_buffer_used = 0;
    usb_discard_pending_tx();
}

static void handle_command(const command_packet_t *command)
{
    if (command->command == COMMAND_INFO) {
        capture_stop();
        usb_discard_pending_tx();
        active_session_id = command->session_id;
        packet_sequence = 0;
        session_armed = true;
        streaming = false;
        capture_read_words = 0;
        capture_dropped_frames = 0;
        queue_control_packet(PACKET_HELLO);
        return;
    }

    if (command->command == COMMAND_START) {
        if (!session_armed || command->session_id != active_session_id) {
            capture_stop();
            usb_discard_pending_tx();
            active_session_id = command->session_id;
            packet_sequence = 0;
            session_armed = false;
            streaming = false;
            queue_control_packet(PACKET_ERROR);
            return;
        }

        usb_discard_pending_tx();
        packet_sequence = 0;
        capture_start();
        streaming = true;
        queue_control_packet(PACKET_STARTED);
        return;
    }

    if (command->command == COMMAND_STOP && command->session_id == active_session_id) {
        capture_stop();
        streaming = false;
        usb_discard_pending_tx();
        queue_control_packet(PACKET_STOPPED);
    }
}

static void command_consume_byte(uint8_t byte)
{
    if (command_buffer_used < sizeof(command_buffer)) {
        command_buffer[command_buffer_used++] = byte;
    }

    while (command_buffer_used >= sizeof(COMMAND_MAGIC) - 1u &&
           memcmp(command_buffer, COMMAND_MAGIC, sizeof(COMMAND_MAGIC) - 1u) != 0) {
        memmove(command_buffer, &command_buffer[1], --command_buffer_used);
    }

    if (command_buffer_used != sizeof(command_packet_t)) {
        return;
    }

    command_packet_t command;
    memcpy(&command, command_buffer, sizeof(command));
    command_buffer_used = 0;

    if (command.version != PROTOCOL_VERSION || command.packet_bytes != sizeof(command_packet_t)) {
        return;
    }

    const uint32_t crc = crc32_calculate((const uint8_t *)&command, offsetof(command_packet_t, crc32));
    if (crc != command.crc32) {
        return;
    }

    handle_command(&command);
}

static void usb_rx_task(void)
{
    uint8_t bytes[64];
    while (tud_cdc_available() > 0) {
        const uint32_t count = tud_cdc_read(bytes, sizeof(bytes));
        for (uint32_t i = 0; i < count; ++i) {
            command_consume_byte(bytes[i]);
        }
    }
}

int main(void)
{
    board_init();
    crc32_init();
    capture_init();

    tud_init(BOARD_TUD_RHPORT);
    if (board_init_after_tusb) {
        board_init_after_tusb();
    }

    bool was_connected = false;
    while (true) {
        tud_task();

        const bool connected = tud_cdc_connected();
        if (!connected && was_connected) {
            reset_session();
        }
        was_connected = connected;

        if (!connected) {
            continue;
        }

        usb_rx_task();
        usb_tx_task();

        if (streaming) {
            // Update the overrun guard even while USB still owns a pending
            // packet. Any loss becomes visible in the next packet's counters
            // and first-frame index.
            (void)capture_available_words();
            if (tx_packet_bytes == 0) {
                (void)queue_audio_packet();
            }
        }
    }
}

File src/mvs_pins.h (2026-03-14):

/**
 * NeoPico-HD MVS Pin Configuration
 *
 * This file contains all MVS capture, I2S audio, and OSD control pins.
 * These are specific to the NeoPico-HD firmware and hardware layout.
 */

#ifndef MVS_PINS_H
#define MVS_PINS_H

// =============================================================================
// MVS Video Input Pins - GP27-45 CONTIGUOUS LAYOUT
// =============================================================================
// Captures RGB555 + SHADOW + DARK from Neo Geo MVS.
//
// 19-pin capture window: GP27 (LSB) through GP45 (MSB).
//
// Pin mapping (LSB to MSB in captured word):
//   Bit 0:      GP27 (CSYNC)
//   Bit 1:      GP28 (PCLK)
//   Bits 2-6:   GP29-33 (Blue B4-B0, contiguous)
//   Bits 7-11:  GP34-38 (Green G4-G0, contiguous)
//   Bits 12-16: GP39-43 (Red R4-R0, contiguous)
//   Bit 17:     GP44 (SHADOW)
//   Bit 18:     GP45 (DARK)
//
// With PIO GPIOBASE=16, pin index N = GP(N+16). So IN_BASE=11 → GP27.

#define PIN_MVS_CSYNC 27 // Composite sync (position 0 in capture word)
#define PIN_MVS_PCLK 28  // Pixel clock (6 MHz, position 1)
#define PIN_MVS_BASE 27  // Base pin - capture GP27-45 (19 pins), CSYNC first

// Blue channel (B4-B0) - CONTIGUOUS at bits 2-6
#define PIN_MVS_B4 29
#define PIN_MVS_B3 30
#define PIN_MVS_B2 31
#define PIN_MVS_B1 32
#define PIN_MVS_B0 33

// Green channel (G4-G0) - CONTIGUOUS at bits 7-11
#define PIN_MVS_G4 34
#define PIN_MVS_G3 35
#define PIN_MVS_G2 36
#define PIN_MVS_G1 37
#define PIN_MVS_G0 38

// Red channel (R4-R0) - CONTIGUOUS at bits 12-16
#define PIN_MVS_R4 39
#define PIN_MVS_R3 40
#define PIN_MVS_R2 41
#define PIN_MVS_R1 42
#define PIN_MVS_R0 43

// Special effects
#define PIN_MVS_SHADOW 44 // Bit 17
#define PIN_MVS_DARK 45   // Bit 18

#define MVS_CAPTURE_PIN_LAST PIN_MVS_DARK
#define MVS_CAPTURE_BITS 19

// =============================================================================
// I2S Audio Input Pins (DAT=GP22, WS=GP23, BCK=GP24)
// =============================================================================
// MV1C: NEO-YSA2 digital tap (right-justified, ~55.5kHz)
// PCM1802: ADC I2S output (standard I2S, 48kHz with 12.288MHz SCKI)
// Same GPIOs for both — pin order constrained by PIO `wait pin N`
#define PIN_I2S_DAT 22 // I2S data (DOUT on PCM1802)
#define PIN_I2S_WS 23  // I2S word select (LRCK on PCM1802)
#define PIN_I2S_BCK 24 // I2S bit clock (BCK on PCM1802)

// =============================================================================
// OSD Control (Direct Buttons)
// =============================================================================
// Custom PCB (WeAct RP2350B): SW_MENU=GP25, SW_BACK=GP26. Change if different.
#define PIN_OSD_BTN_MENU 25 // Menu / Select Button
#define PIN_OSD_BTN_BACK 26 // Back / Cycle Button

#endif // MVS_PINS_H

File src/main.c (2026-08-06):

/**
 * NeoPico-HD - MVS Video Capture + HSTX Output
 *
 * Core 0: Audio capture + processing
 * Core 1: HSTX HDMI output (DMA IRQ handler consumes DI queue)
 */

#include "pico_hdmi/hstx_data_island_queue.h"
#include "pico_hdmi/video_output_rt.h"

#include "pico/multicore.h"
#include "pico/stdlib.h"

#include "hardware/clocks.h"
#include "hardware/vreg.h"

#include <stdint.h>
#include <stdio.h>
#include <string.h>

#include "audio_subsystem.h"
#include "capture_pins.h"
#include "experiments/menu_diag_experiment.h"
#include "osd/fast_osd.h"
#include "settings.h"
#include "video/line_ring.h"
#include "video/video_config.h"
#include "video/video_pipeline.h"
#include "video_capture.h"

// Line ring buffer (shared between Core 0 and Core 1)
line_ring_t g_line_ring __attribute__((aligned(64)));

#ifndef NEOPICO_VIDEO_DVI_ONLY
#define NEOPICO_VIDEO_DVI_ONLY 0
#endif

#define SYS_CLK_60HZ_KHZ 126000U
#define SYS_CLK_720P_RUNTIME_KHZ 320000U
// 480p is line-doubled (31.5 kHz scanline IRQ): at 126 MHz that is only ~4000
// cyc/line and the per-line ISR occasionally underruns -> desync. Run 480p at
// 252 MHz (~8000 cyc/line, matching the stable 240p/720p budgets). The HSTX
// divider is doubled in video_mode_480_p so the pixel clock stays 25.2 MHz
// (picture identical); requires VREG 1.30V and copy_to_ram (252 MHz overclock).
#define SYS_CLK_480P_KHZ 252000U

#if NEOPICO_EXP_GENLOCK_DYNAMIC
// 480p/720p need no genlock-specific mode: their genlock is vtotal/htrim
// dithered at runtime around the same descriptor. 240p's genlock raster
// differs in h_total (1613 vs 1600, see video_mode_240_p_genlock), which is
// baked into command lists at mode apply, so it needs a distinct descriptor
// selected here instead of a runtime-only knob.
//
// This whole function is duplicated (rather than adding a parameter to the
// one below) so that a non-genlock build's compiled main.c is byte-for-byte
// identical to before this feature existed -- scratch_x is exactly full in
// default builds, and while this function itself isn't scratch-resident,
// byte-identity here is still how the gates in this task were verified.
static const video_mode_t *video_output_mode_for_reboot_mode(video_pipeline_reboot_mode_t mode, bool genlock_enabled)
{
    if (mode == VIDEO_PIPELINE_REBOOT_MODE_720P) {
        return &video_mode_720_p;
    }
    if (mode != VIDEO_PIPELINE_REBOOT_MODE_240P) {
        return &video_mode_480_p;
    }
#if PICO_HDMI_VBLANK_HTRIM
    if (genlock_enabled) {
        return &video_mode_240_p_genlock;
    }
#else
    (void)genlock_enabled;
#endif
    return &video_mode_240_p;
}
#else
static const video_mode_t *video_output_mode_for_reboot_mode(video_pipeline_reboot_mode_t mode)
{
    if (mode == VIDEO_PIPELINE_REBOOT_MODE_720P) {
        return &video_mode_720_p;
    }
    return (mode == VIDEO_PIPELINE_REBOOT_MODE_240P) ? &video_mode_240_p : &video_mode_480_p;
}
#endif

static void combined_background_task(void)
{
#if !NEOPICO_VIDEO_DVI_ONLY
    audio_subsystem_background_task();
#if NEOPICO_EXP_GENLOCK_DYNAMIC
    if (video_pipeline_genlock_enabled()) {
        video_output_htrim_update_audio_pacing();
    }
#endif
#endif
    menu_diag_experiment_tick_background();
}

// ============================================================================
// Main (Core 0)
// ============================================================================

int main(void)
{
    sleep_ms(1000);

    video_pipeline_reboot_mode_t reboot_boot_mode = VIDEO_PIPELINE_REBOOT_MODE_480P;
    const bool warm_reboot = video_pipeline_take_reboot_mode_boot_request(&reboot_boot_mode);
    neopico_settings_t persisted;
    settings_load(&persisted);
    // Batched Video-screen Apply safety net: an Apply that changed Resolution
    // and/or Refresh (genlock) reboots via
    // video_pipeline_request_reboot_mode_pending(), which sets a
    // watchdog-scratch pending marker and carries the revert resolution
    // across the reboot (see video_pipeline.c) -- volatile by design, so the
    // later Keep action has nothing to clear. The revert genlock bit has no
    // scratch carrier (genlock is applied at boot from this persisted
    // record, not from scratch), so it still comes from flash; settings_load()
    // above must run before this to make it available. Arm the same
    // keep/revert countdown UI here as before.
    video_pipeline_reboot_mode_t revert_resolution = VIDEO_PIPELINE_REBOOT_MODE_480P;
    if (video_pipeline_take_pending_confirmation(&revert_resolution)) {
        menu_diag_experiment_arm_revert_confirm(reboot_boot_mode, revert_resolution,
                                                persisted.pending_revert_genlock != 0U);
    }
#if NEOPICO_EXP_GENLOCK_DYNAMIC
    // Genlock is opt-in (default off) and, like resolution, applied only at
    // boot: Apply persists the new value to flash before rebooting (see
    // menu_diag_experiment.c), so the flash copy already reflects the
    // to-be-confirmed value by the time we read it here.
    const bool genlock_enabled = persisted.genlock_enabled != 0U;
#endif
#if NEOPICO_AUDIO_MODE == NEOPICO_AUDIO_MODE_SELECTABLE
    // Audio-source changes reboot through the existing warm-reboot path, so
    // unlike resolution the persisted source must be loaded on every boot.
    if (persisted.audio_source_valid == NEOPICO_SETTINGS_AUDIO_SOURCE_VALID &&
        audio_source_is_valid(persisted.audio_source)) {
        audio_subsystem_set_source((audio_source_t)persisted.audio_source);
    }
#endif
#if NEOPICO_MVS_COLOR_MODEL_MENU
    // Load the persisted model before capture starts. The capture module builds
    // both LUTs and publishes this initial selection before its first frame.
    if (persisted.color_model_valid == NEOPICO_SETTINGS_COLOR_MODEL_VALID &&
        mvs_color_model_is_valid(persisted.color_model)) {
        video_capture_set_color_model((mvs_color_model_t)persisted.color_model);
    }
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

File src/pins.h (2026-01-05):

/**
 * NeoPico-HD Pin Configuration
 *
 * Single source of truth for all GPIO pin assignments
 * Target: RP2350B (WeAct Studio RP2350B Core)
 */

#ifndef PINS_H
#define PINS_H

// =============================================================================
// MVS Video Input Pins - GP27-44 CONTIGUOUS LAYOUT
// =============================================================================
// Captures RGB555 + DARK + SHADOW from Neo Geo MVS
//
// GP27-44: 18-pin capture window (CONTIGUOUS bit fields for performance)
// GP45:    CSYNC (outside capture window, read separately)
//
// OPTIMIZED Pin mapping (Shift +2):
//   PCLK:   GP27 (position 0 - CRITICAL!)
//   Red:    R0=GP28, R1=GP29, R2=GP30, R3=GP31, R4=GP32 (5 bits, contiguous)
//   Green:  G0=GP33, G1=GP34, G2=GP35, G3=GP36, G4=GP37 (5 bits, contiguous)
//   Blue:   B0=GP38, B1=GP39, B2=GP40, B3=GP41, B4=GP42 (5 bits, contiguous)
//   DARK:   GP43 (1 bit)
//   SHADOW: GP44 (1 bit)
//   CSYNC:  GP45 (outside 18-pin window, separate PIO SM)
//
// PIO captures GP27-44 (18 consecutive pins) using 'in pins, 18'

#define PIN_MVS_PCLK 27  // Pixel clock (6 MHz, position 0)
#define PIN_MVS_CSYNC 45 // Composite sync (outside capture window)
#define PIN_MVS_BASE 27  // Base pin - capture GP27-44 (18 pins, PCLK first)

// Red channel (R0-R4) - CONTIGUOUS at bits 1-5
#define PIN_MVS_R0 28
#define PIN_MVS_R1 29
#define PIN_MVS_R2 30
#define PIN_MVS_R3 31
#define PIN_MVS_R4 32

// Green channel (G0-G4) - CONTIGUOUS at bits 6-10
#define PIN_MVS_G0 33
#define PIN_MVS_G1 34
#define PIN_MVS_G2 35
#define PIN_MVS_G3 36
#define PIN_MVS_G4 37

// Blue channel (B0-B4) - CONTIGUOUS at bits 11-15
#define PIN_MVS_B0 38
#define PIN_MVS_B1 39
#define PIN_MVS_B2 40
#define PIN_MVS_B3 41
#define PIN_MVS_B4 42

// Special effects (bits 16-17)
#define PIN_MVS_DARK 43   // Bit 16
#define PIN_MVS_SHADOW 44 // Bit 17

// =============================================================================
// DVI/HDMI Output Pins (GPIO 12-19)
// =============================================================================
#define PIN_DVI_CLK 12 // Clock pair base (12=CLK-, 13=CLK+)
#define PIN_DVI_D0 14  // Data 0 pair base (14=D0-, 15=D0+)
#define PIN_DVI_D1 16  // Data 1 pair base (16=D1-, 17=D1+)
#define PIN_DVI_D2 18  // Data 2 pair base (18=D2-, 19=D2+)

// =============================================================================
// I2S Audio Input Pins (GPIO 0-2)
// =============================================================================
#define PIN_I2S_DAT 0 // I2S data
#define PIN_I2S_WS 1  // I2S word select
#define PIN_I2S_BCK 2 // I2S bit clock

#endif // PINS_H

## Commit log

2025-11-29 Phase 5 complete: 4-bit RGB capture working perfectly!
    Major achievement: Solved PIO autopush alignment problem using 4-bit capture
    (R4, G4, B4, GND) instead of direct 3-bit capture.
    Key insight: 32-bit autopush ÷ 4 bits/pixel = 8 pixels (perfect alignment)
    GPIO 5 (tied to ground) provides free dummy bit for alignment!
    Changes:
    - Updated main.c extraction code for 4-bit capture
    - Changed output format from PGM to PPM (8-color RGB)
    - Verified with King of Fighters: crystal-clear, no artifacts
    - Documented 4-bit solution and why 3-bit was impossible
    What was learned:
    - 3-bit (32÷3 = 10.67): BROKEN - misaligned word boundaries
    - 4-bit (32÷4 = 8.00): PERFECT - exact pixel alignment
    - Only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
    [main.c]
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2025-12-16 Update docs with correct DVI pin configuration
    - Add DVI_PIN_TESTING.md documenting RP2350 PIO/PWM constraints
    - Update PROJECT_STATUS.md with correct GPIO pinout
    - Update agent instructions with current hardware configuration
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2026-01-01 GP25+ video capture working
    [neopico-hd.kicad_pcb, neopico-hd.kicad_sch]
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2026-01-05 Fix video pins mapping
    [pins.h, video_capture.c]
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2026-01-10 Fix HDMI signal timing, polarity and signal integrity for strict receivers
    [main.c]
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2026-02-03 Fix typo
    [neopico-hd.kicad_pcb, neopico-hd.kicad_sch]
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2026-02-08 Fix scratchy audio by using DROP mode. Interpolation might be okay.
    [main.c, video_capture.c]
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2026-02-13 Improve audio by adding 2s delay on startup
    [pico-retrodigital.kicad_pcb, pico-retrodigital.kicad_sch]
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2026-02-16 Add missing signal from selftest
    [menu_diag_experiment.c]
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2026-03-01 Hardware - add HDMI termination resistors and more
    [neopico-hd.kicad_pcb, neopico-hd.kicad_sch]
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2026-04-25 Add stable 720p non-RT build
    [neopico-hd.kicad_sch]
2026-04-26 Remove old kicad project
    [pico-retrodigital.kicad_pcb, pico-retrodigital.kicad_sch]
2026-04-26 Add reboot-based HDMI mode switch experiment
    [main.c, menu_diag_experiment.c]
2026-04-26 Add reboot-based HDMI mode switching
    [main.c, menu_diag_experiment.c]
2026-04-27 Stabilize reboot OSD mode switching
    - add flag-gated OSD/audio timing isolation paths
    - pre-render selector UI and keep cold apply path in SRAM
    - fix no-720p reboot callback to render 240p with quad scaling
    - update pico_hdmi submodule for 240p AVI metadata
    [main.c, menu_diag_experiment.c]
2026-04-28 Add stable reboot resolution cycler
    [audit_firmware.py, main.c, menu_diag_experiment.c]
2026-06-11 Upgrade pico_hdmi to 2.0-beta (7fa6dd5)
    Behaviorally inert: all 2.0 mechanisms (precomposed scanout, native pixel
    mode, ISR-side audio pacing, resync control) are opt-in and OFF. Included
    for free: audio underruns no longer assert the IEC block-start flag (sink
    channel-status resync glitch). The two formerly submodule-only commits
    (240p AVI metadata, reboot-mode switching) are now part of upstream
    2.0-beta, fixing the dangling submodule pointer for fresh clones.
    Both builds (480p RT, 720p non-RT) compile clean with zero app changes.
2026-06-11 Add experimental pico_hdmi 2.0 precomposed/native scanout path (480p)
    NEOPICO_EXP_PRECOMPOSED_HDMI (OFF by default; requires NEOPICO_USE_NONRT_HDMI,
    480p-only): pointer-model scanline callback -- video rows return the captured
    line_ring line directly (zero copy; bus replication + HSTX expander do the 2x
    doubling), letterbox/no-signal rows return static native color lines, OSD rows
    compose into a per-line ping/pong native scratch (word loops only in ISR
    context; cache invalidated per frame). Audio islands are patched into
    precomposed line headers by the library's scanline ISR, making audio delivery
    immune to Core 1 background stalls (the SRC's bursty load is the same hazard
    class that caused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
    [main.c]
2026-06-12 CI: drop pico-retrodigital from the KiBot matrix (files no longer in repo)
    Fixes the fabrication job failure (Schematic file not found), which hard-
    blocks the tag release job via needs: [build, fabrication].
2026-06-12 Execute from RAM (copy_to_ram): structural fix for XIP-induced sync drops
    Root cause of months of 'dead code perturbs sync' phenomena and the rare
    20-60 min sync drops in OSD-compiled precomposed builds: XIP flash-fetch
    stalls landing on timing-critical instants, with per-build flash layout
    deciding where they land. Proven by a one-variable oracle: the exact
    394-line patch that glitched instantly from flash runs calm from RAM;
    a build containing every previously-fatal ingredient (precomposed + OSD
    open + selftest + watchdog) soaked hours clean from RAM.
    - NEOPICO_COPY_TO_RAM option (pico_set_binary_type copy_to_ram); text is
    ~47 KB and both LUTs are runtime-built BSS, so it fits with >100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
    [main.c, menu_diag_experiment.c]
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2026-06-15 Default to RT + OSD; ship 3 resolution firmwares (240p/480p/720p)
    Make the runtime-modes (RT) path + OSD + self-test + root menu the
    project default (ENABLE_OSD/ENABLE_SELFTEST/OSD_ROOT_MENU now ON).
    No-arg build = 480p RT + OSD.
    CI now produces exactly three artifacts with identical flags varying
    only by resolution: neopico_hd_{240p,480p,720p}.uf2. Dropped the
    rt/non-rt/precomp/pcm1802 variants.
    720p (372 MHz overclock) auto-forces COPY_TO_RAM via a CMake guard: at
    that clock XIP flash reads corrupt and the core hard-faults; executing
    from RAM is the robust, flash-chip-independent fix.
    OSD is now button-triggered (MENU) instead of booting open; the old
    soak-aid boot-open is behind NEOPIC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
    [main.c, menu_diag_experiment.c]
2026-06-15 Baseline: single resolution-selector firmware (240p/480p/720p in OSD)
    The selector is now the default build: REBOOT_MODE_SWITCH(+720P) default ON,
    so one firmware switches all three modes from the OSD resolution menu (reboot
    based). CI ships a single neopico_hd.uf2; the 3 fixed-res artifacts are dropped.
    480p now runs at 252 MHz (SYS_CLK_480P_KHZ) for scanline-IRQ headroom: at
    126 MHz its line-doubled 31.5 kHz IRQ left only ~4000 cyc/line and underran
    -> desync. 252 MHz doubles that to ~8000 (matching 240p/720p). pico_hdmi's
    PICO_HDMI_480P_HSTX_CLK_DIV=2 keeps the pixel clock at 25.2 MHz (signal
    identical). The copy_to_ram guard now covers the 480p overclock too.
    OSD resolution menu: order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
    [main.c, menu_diag_experiment.c]
2026-06-15 Bump lib/pico_hdmi to f8034c7 (Tier-1 per-scanline ISR trim)
    Gates the perf probe off by default, replaces the v_scanline modulo with
    compare-and-reset, and precomputes the vertical region boundaries -- ~45-70
    cyc/line off the scanline ISR. Behaviorally identical; no clock change.
2026-06-15 Add compile-time audio volume (NEOPICO_AUDIO_VOLUME_PCT, default 100)
    Q15 attenuation on the final SRC output samples (audio_pipeline.c), applied
    only when != 100 so the default build is byte-identical. Attenuation-only ->
    overflow-safe, no clamp. Default 100 = unity (loud-audio turned out to be a
    sink/analog-chain issue, not firmware); knob kept dormant for convenience.
2026-06-15 Auto-reboot once on cold boot to fix cold-boot scratchy audio (default ON)
    On a cold power-on the MVS audio DAC hasn't settled and the TV's HDMI audio
    decoder can latch Data Islands before TMDS lock -> scratchy audio that a manual
    reset clears. NEOPICO_EXP_FIRST_BOOT_REBOOT (default ON) replicates that reset:
    on a cold boot it immediately reboots once into the default mode via the
    existing reboot-mode/watchdog-scratch path, so the warm boot re-establishes the
    HDMI link cleanly. Fires exactly once (warm boot sees the scratch magic and
    proceeds). Costs ~1-2s extra on cold power-on; warm/resolution-select reboots
    unaffected. Confirmed on hardware: clears SamSho/KOF98 cold-boot scratchiness.
    [main.c]
2026-06-15 Flash-backed settings: persist resolution across power-off
    New src/settings.{c,h}: a magic+version+CRC record in the last 4 KB flash
    sector (16 MB part, top sector never collides with the ~75 KB image). Read at
    cold boot, written at the reboot point. Payload has reserved bytes to grow
    without a format bump.
    - request_reboot_mode() persists the selected resolution (blocking erase+program
    before watchdog_reboot; with copy_to_ram the XIP suspend stalls nothing, and
    the brief ISR pause is invisible since we're rebooting).
    - Cold boot loads the saved resolution as the boot target (warm reboots still
    carry it in watchdog scratch). Previously resolution reset to 480p on power-off.
    - NEOPICO_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
    [main.c]
2026-06-15 Resolution-change safety net: keep/revert countdown after a switch
    After switching resolution the device reboots into the new mode and shows a
    10s 'Keep this resolution?' prompt (MENU keeps, BACK or timeout reverts).
    Auto-recovers from picking a mode the display can't show (black screen ->
    timeout -> back to the working res).
    - Pending state rides watchdog scratch[3] only: watchdog_reboot(0,0,..) clears
    scratch[4..7] (SDK boot vector) and the existing reboot mode owns scratch[0..2],
    so the marker+previous-mode+check are packed into the one surviving register.
    - Flash writes happen ONLY at reboot points (masked): select persists the new
    mode optimistically; revert/timeout rolls it back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
    [main.c, menu_diag_experiment.c]
2026-06-15 docs: add 720p purple-scanline glitch investigation tracker
    Root-caused to Core 0 capture activity (not channel/content, not FIFO
    underrun). Living document: isolation ladder, FIFO-probe result, ruled-out
    list, mechanism, open tiebreaker experiment, and mitigation options.
2026-06-15 docs(720p glitch): de-conclude — demote to leading hypothesis, flag under-powered tests
    Clean results came from ~2-min windows vs a <=2-min-period event (under-powered).
    Reframe as ranked hypotheses (power/EMI vs clock jitter vs sub-line bus), none
    confirmed; add confidence/caveats section; next step = a real long-window baseline.
2026-06-16 720p: label experimental in OSD + capture-health diag counters + tracker
    - OSD resolution menu: 720p now shows "Experimental (3x)" (rare Game-Mode
    glitch under investigation; see docs/720P_PURPLE_GLITCH.md).
    - NEOPICO_DIAG_COUNTERS (flag-gated, OFF by default): line-ring readiness/
    overrun, capture sync-reset, and in/out frame-rate counters over USB-serial.
    No effect on default builds.
    - OSD_BOOT_OPEN now also works without genlock (boots onto Self Test) for diag.
    - docs/720P_PURPLE_GLITCH.md: investigation tracker. Capture-timing/sync ruled
    out; differentiator is rendering live captured video; open fork = wrong-data-
    in-line vs output-side.
    [menu_diag_experiment.c, video_capture.c]
2026-06-27 audio: recover I2S capture after flashcart resets
    [video_capture.c]
2026-07-13 audio: fix PCM1802 sample-rate conversion
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2026-07-13 docs: HDMI audio pacing accuracy, dropout root cause, PCM1802 notes
    HSTX_IMPLEMENTATION: document Data Island pacing derivation, the
    floor-truncation drift vs ACR and the exact-rational pacing default
    (PICO_HDMI_EXACT_AUDIO_PACING), plus the AU underrun diag counter.
    KNOWN_ISSUES: add resolved entry for the rare periodic HDMI audio
    dropouts (sink buffer drain) with the remaining distinct mechanisms.
    MVS_MV1C_DIGITAL_AUDIO: document PCM1802/AES builds, the source-aware
    servo rate window (fix 52d9375) and why LINEAR SRC is the default
    for upsample-capable sources.
2026-07-13 firmware: fix 240p output and expand OSD controls
    [audit_firmware.py, main.c, menu_diag_experiment.c]
2026-07-15 docs: record 720p Game Mode glitch experiment state and production analysis
    Content axis closed (E1 static-screen glitch, E2a flash-torture demo clean),
    June clean windows re-weighted as under-powered, matched-pair live/pattern
    soak defined with build-live720-fixed as the pending gate, clk_hstx spec
    framing (150 MHz rated vs 372 MHz), E3 clock-source levers queued, and
    level-shifter/redriver/ESD mitigation research for the production board.
    New KNOWN_ISSUES entry for the open 720p transient corruption.
2026-08-01 build: collapse always-on flags into the only path
    The CMake surface had accumulated 38 NEOPICO_* options, many of which were
    permanently ON in shipped firmware or were dead experiments. Reduce to 11.
    Promote to permanent behavior (previously flag-gated, always ON in shipped
    builds): the OSD stack and root menu, selftest, translucent panel, resolution
    menu with keep/revert confirm, settings persistence, first-boot reboot,
    controller inputs, the ring frame guard, and copy-to-RAM. Audio mode is now
    derived from the capture target: MVS selectable, SNES digital.
    Make exact-clock 64 MHz the only 720p. Delete the compile-time pico_hdmi
    backend (including its 372 MHz CTA-style 720p), the compile-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
    [audit_firmware.py, capture_pins.h, main.c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]
2026-08-01 video: add cps2_digiav DARK/SHADOW model for hardware comparison
    Adds NEOPICO_MVS_EFFECT_MODEL=DIGIAV, a third effect profile transcribed
    from cps2_digiav: SHADOW halves the RGB555 value before expansion and forces
    DARK, channels expand as {v5, v5[4:2]}, and DARK subtracts four with
    saturation. Because SHADOW forces DARK it is a three-state model, so SHADOW
    and DARK+SHADOW are identical. White endpoints are 255/251/119/119.
    Normal and DARK output are byte-identical to MiSTer after RGB565 packing;
    the models differ only in the SHADOW states.
    Implemented in both backends. The split LUT alone would have been unusable
    for evaluation because that backend produces bottom-screen jitter, so
    mvs_di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
    [mvs_color_exhaustive.c]
2026-08-01 video: full-precision RGB888 scanout at 480p (experimental)
    Adds NEOPICO_EXP_RGB888_SCANOUT (default OFF), which carries the captured
    DARK/SHADOW signals through to true 8-bit output instead of quantising them
    into RGB565. Two defects motivate it:
    1. RGB565 gives red and blue only 5 bits, but the Neo Geo dark bit is a HALF
    step. Of 32 values, 17 showed no dark difference at all and the other 15
    showed double the true step. Only green (6 bits) was close to correct.
    2. Per raspberrypi/pico-feedback issue 454, the HSTX TMDS encoder zero-fills
    unused data bits, so RGB565 white reaches 0xF8FCF8 rather than 0xFFFFFF:
    every frame is about 3 percent dim with a slight green cast.
    The li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
    [mvs_color_exhaustive.c, mvs_effect_lut.h, video_capture_mvs.c]
2026-08-01 video: RGB888 working at 240p and 480p; add scanline timing trace
    Completes the 32-bit scanout path for the two modes that can sustain it, and
    adds the instrumentation that found out why the third cannot.
    Root cause of the 240p failure was a per-mode clock difference, not anything
    in the conversion. main.c runs 480p at 252 MHz (with the pico_hdmi divider
    holding the pixel clock at 25.2 MHz) but 240p at only 126 MHz, so 240p gives
    the CPU half the cycles per scanline. Measured with the new trace: 240p needed
    5913 of 8000 cycles (74%) and failed, while 480p used 4802 of 8001 (60%) and
    worked. 240p was the most loaded mode, not the least. Giving it the same
    double-clock treatment takes it to a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
    [main.c, read_scanline_trace.py, video_capture_mvs.c]
2026-08-01 video: 720p RGB888 via double-buffered scanout; all modes full precision
    Enables the pico_hdmi double-buffer option for RGB888 builds
    (NEOPICO_EXP_RGB888_DOUBLE_BUFFER, default OFF) and records the diagnostics
    that led to it. With it, all three output modes run true 8-bit colour with
    DARK/SHADOW: 480p (60% line budget), 240p (37% after its clock fix), and
    720p via the double-buffer (fill ~6150 cycles against a multi-line window).
    720p could not be fixed the way 240p was: its pixel clock is sys_clk/5 with
    the TMDS symbol rate pinning the divider, so sys_clk is exactly 320 MHz and
    there is no headroom to buy. The scanline trace measured the 3x fill at
    85-94% of the single-line budget, which i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
2026-08-01 fix: run 240p at 252 MHz (v0.11.0 DARK/SHADOW bottom-half regression)
    v0.11.0 enabled DARK/SHADOW conversion by default, making Core 0's
    per-pixel work heavier. At 240p the stock sysclk is only 126 MHz (480p
    runs 252, 720p 320), so conversion lateness accumulates down the frame:
    hardware shows bottom-half bounce and per-line horizontal shifts that
    grow toward the bottom. v0.10.0 and DARK/SHADOW-off builds are clean.
    Give 240p the same 252 MHz treatment as 480p. The new
    PICO_HDMI_240P_HSTX_CLK_DIV=2 (pico_hdmi 6fc1da3) holds clk_hstx at
    126 MHz so the 25.2 MHz pixel clock and the on-wire signal are
    unchanged; capture PIO dividers and audio pacing already derive from
    the runtime clocks and fo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
    [main.c]
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2026-08-01 docs: record VRR and tearing assessment vs genlock
    VRR (VTEM / FreeSync-over-HDMI) is feasible - hstx_di_queue_push takes
    arbitrary packets and rt_v_total_lines gives per-frame length control -
    but sinks rarely engage VRR below 1080p, scalers don't accept it, and
    with no DDC/EDID path activation would be blind. Tearing (per-scanline
    frame latch) keeps standard 60 Hz but replaces the periodic hiccup with
    a permanent crawling shear line. Genlock soak remains the plan; VRR is
    the follow-up if a direct-TV sink rejects fixed 59.19 Hz.
    Claude-Session: https://claude.ai/code/session_011kYDRQ1GZJyVSAR9KhaVuG
2026-08-01 genlock: fix dead htrim servo, retime 240p, adopt 252 MHz 240p clock
    Hardware findings behind this commit:
    - The resurrected servo's trim was a no-op: htrim slot registration
    never ran in non-precomposed builds (fixed in pico_hdmi, gated by
    PICO_HDMI_VBLANK_HTRIM which this build now sets when genlock is on).
    - 240p genlock nominal becomes 264 (retimed 1613x264 raster, 59.178 Hz,
    15.62 kHz H: numerically the MVS's own raster; residual ~2 px trim).
    - The 240p bottom-half artifact chased during bring-up turned out to be
    the v0.11.0 DARK/SHADOW regression (fixed on main: 240p at 252 MHz),
    not genlock; with that fix genlock 240p is hardware-clean.
    - NEOPICO_DIAG_GENLOCK_SERVO_OFF / NEO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
2026-08-01 runtime genlock toggle, persisted, default off, reboot-applied with keep/revert confirm; hardware-validated
    [main.c, menu_diag_experiment.c]
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2026-08-01 ci: pin pico-sdk commit and mirror local absolute paths for byte-identity
    Two remaining sources of drift between CI artifacts and the hardware-
    validated binary, on top of the already-pinned Arm GNU Toolchain:
    1. The "Setup Pico SDK" step did an unpinned `git clone --depth 1` of
    pico-sdk's default branch, which drifts over time. Confirmed this
    produced SDK 2.3.0 in CI vs 2.2.1-develop locally (a1e9cf0), with a
    >1KB .text/.bss delta. Pin to that exact commit; submodule gitlinks
    baked into it reproduce the same submodule SHAs as local.
    2. GCC embeds __FILE__ and DWARF paths literally as given on the
    command line. Check the repo out at /Users/dudu/Projects/neogeo/
    neopico-hd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
2026-08-02 firmware: fix HDMI audio dropouts when genlock trims the raster
    Audio DI pacing was computed once from the nominal mode raster, but the
    genlock servo's vblank h-trim changes the true line period, so delivery
    drifted a few samples per second off the exact rate the sink
    regenerates from ACR, slipping its FIFO into periodic dropouts. The
    Core 1 background task now asks pico_hdmi to recompute pacing from the
    effective trimmed raster whenever the servo moves (runtime genlock
    check; no ISR changes; byte-identical when genlock is compiled out).
    [main.c]
2026-08-02 osd: remove Genlock Info diagnostic screen
    Development tooling not meant to ship; the Genlock On/Off toggle and
    its keep/revert confirmation flow are unchanged. Servo telemetry
    globals stay for future diagnostics.
    [menu_diag_experiment.c]
2026-08-03 osd: grouped menu with batched Video Apply
    Replaces the flat root menu (Resolution / Audio / Colors / Self Test /
    Genlock) with Video / Audio / Self Test.
    Video is a single form holding Resolution, Refresh (the genlock rate,
    shown as 60Hz or 59.19Hz) and Colors, committed together by Apply and
    discarded together by Cancel. Batching means one reboot where changing
    resolution and refresh previously cost two.
    The keep/revert countdown is unchanged, but its pending flag now rides
    the existing watchdog-scratch pending-reboot API rather than a flash
    record, so Keep is a pure dismiss. A blocking Core 1 settings_save in
    that path was measured to make HDMI lose sync. Only the revert genlock
    and col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
    [capture_pins.h, main.c, menu_diag_experiment.c]
2026-08-03 tests: track Colors contract onto the Video screen
    The static contract still asserted a standalone MENU_SCREEN_COLOR_MODEL
    case, which the grouped menu removed. Retarget the same guarantees at
    the Video screen: Colors previews live on value change, Cancel restores
    the committed value, and a Colors-only Apply uses the deferred save
    rather than blocking Core 1 (the reboot branch of the same function may
    legitimately call settings_save, so that check is scoped to the
    no-reboot branch).
    Also locks in the invariant this release was built around: the
    post-Apply Keep path performs no flash access at all, measured on
    hardware to lose HDMI sync otherwise.
2026-08-06 osd: full controller pin map and a live button readout
    Aligns the controller taps with the actual harness: UP/DOWN swap to
    GP2/GP3, GP6 becomes A and GP7 becomes B (previously unread). A shares
    START's activate role and B shares SELECT's back role, so either the
    face buttons or START/SELECT drive the menu.
    Adds a live GP0-GP7 readout to the Self Test screen so a wiring map can
    be verified by pressing buttons rather than assumed. It redraws only on
    change, and its cache resets on entry because the screen is cleared.
    Also makes the Video screen fully operable from the two board buttons
    alone, since the controller taps may be unwired: BACK moves the cursor
    and MENU acts on the focused row. Wi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
    [capture_pins.h, main.c, menu_diag_experiment.c]
2026-08-06 video: scanlines with selectable strength
    Adds a Scanlines row to the Video screen: OFF, 25%, 50%, 75%, 100%,
    where the percentage is strength, so 100% is a black line. Both output
    modes use identical per-channel integer math, so they match exactly.
    The two modes need opposite implementations, chosen by which budget the
    code runs in. 720p dims in a deferred fill that has a 3-line window, so
    it can afford per-pixel SIMD (see the pico_hdmi commit). 480p re-renders
    every output line inside the per-line ISR with a one-line window, which
    is the tightest path in the system; a per-pixel version there dropped
    HDMI sync on hardware. So 480p dims through a second pre-dimmed LUT
    instead: same lookup,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
    [video_capture_mvs.c, video_capture_snes.c]
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2026-08-06 ci: the deferred-save queue is unconditional, stop asserting it is absent
    The audit treated settings_request_save / settings_service_pending_save /
    settings_save_pending as Colors-menu symbols and failed any feature-off
    build that contained them. That gate was deliberately removed when the
    Scanlines level became persistent: a blocking settings_save() on Core 1
    suspends XIP long enough to lose HDMI sync unless a reboot immediately
    follows, so the queue is the only safe path for a live setting in any
    configuration, and every build now needs it.
    Assert the stronger property instead -- present and RAM-resident in every
    build -- rather than absent in some. This is why CI has been red since the
    s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
    [audit_firmware.py]
